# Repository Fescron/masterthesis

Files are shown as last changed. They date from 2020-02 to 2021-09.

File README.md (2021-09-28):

# Masterthesis








<br/>

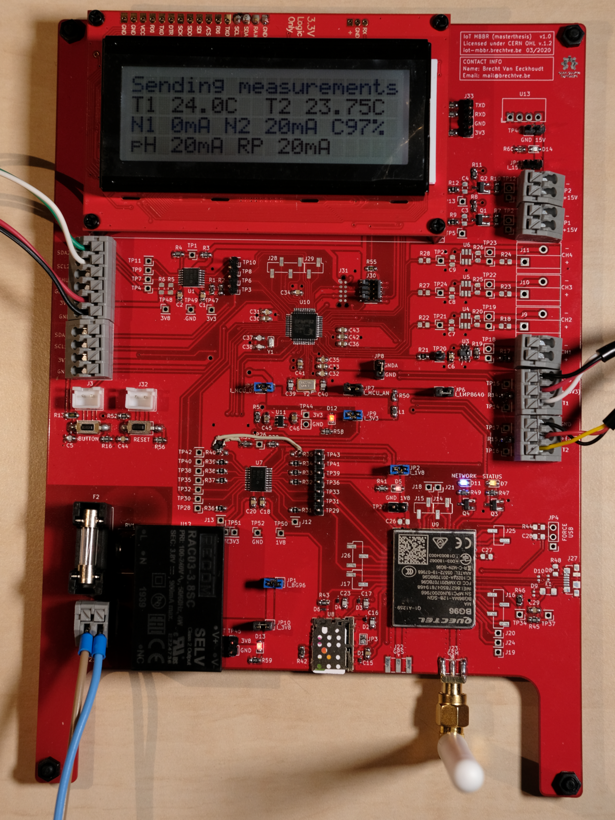
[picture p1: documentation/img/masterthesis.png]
Masterthesis PCB


<br/>

| Quick access links | |
|---|-----|
| [PCB v1.0 schematic (PDF)](hardware/masterthesis-hardware/Plots/masterthesis-hardware-v1.0.pdf) | [Doxygen code documentation of individual files and methods](https://fescron.github.io/masterthesis/files.html) |
| [PCB v1.0 layout (PDF)](hardware/masterthesis-hardware/Plots/masterthesis-hardware-v1-0-PCB.pdf) | [Doxygen TODO's](https://fescron.github.io/masterthesis/todo.html) |

<br>

This repository is a collection of hardware, firmware and some documentation files for the project I created for my masterthesis.

<br/>

## 0 - Table of Contents

- [Masterthesis](#masterthesis)
  - [0 - Table of Contents](#0---table-of-contents)
  - [1 - Situation](#1---situation)
  - [2 - Hardware](#2---hardware)
  - [3 - Firmware](#3---firmware)
  - [4 - Additional hardware changes (PCB v1.0)](#4---additional-hardware-changes-pcb-v10)

<br/>

## 1 - Situation

The goal of the thesis was to create a module to connect a *Moving Bed BioReactor* (MBBR, schematically pictured below) to the Cloud. A MBBR is a system which removes excess nitrites in, in this case, drainwater coming from greenhouses to prevent eutrophication in surrounding water bodies. This is done by denitrifying bacteria inside the bioreactor, which grow on moving plastic *carriers*, and convert the nitrate to nitrogen gas. This is done in anoxic conditions and in the presence of a suitable electron donor, such as a glycerol-based carbon source.

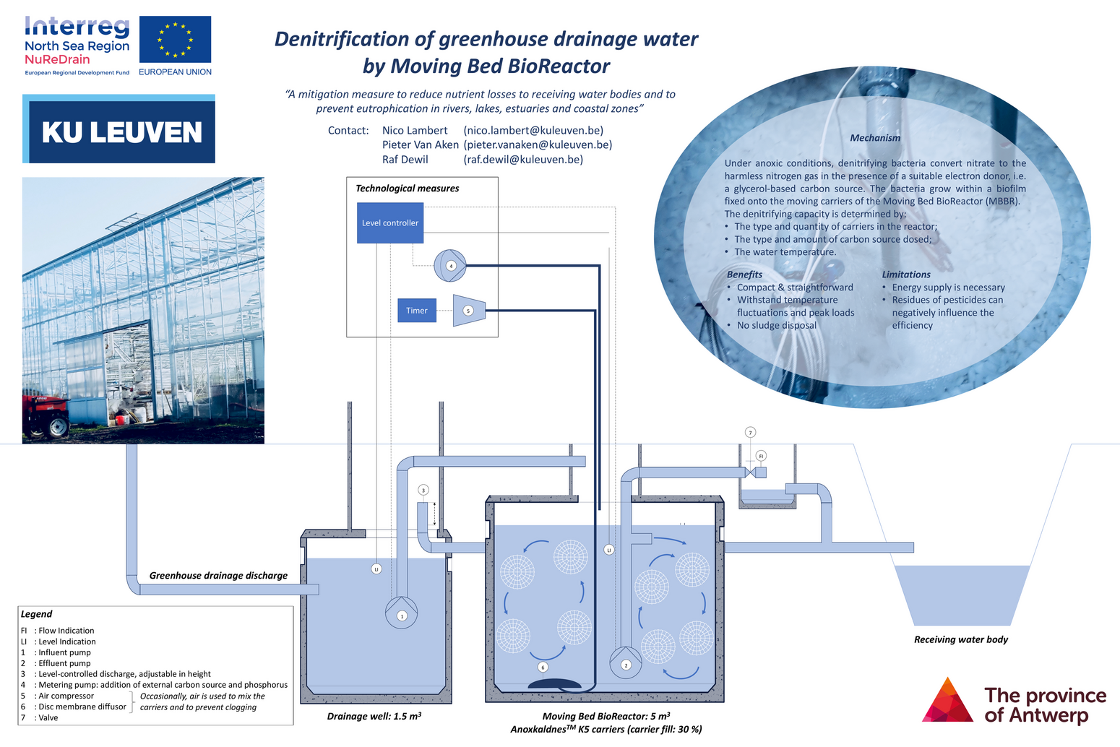
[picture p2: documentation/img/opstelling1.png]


<br/>

The picture below on the left gives an overview of the system that has already been build on the location. The drainage well from the diagram above is pictured on the lower right of this picture. The MBBR itself and a smaller drainage well are underground, under the two manhole covers on the left. In the middle of the picture the measuring system is visible, with under it two blue barrels of carbon source. The picture below on the right gives a peek inside the MBBR. The plastic *carries* are clearly visible.

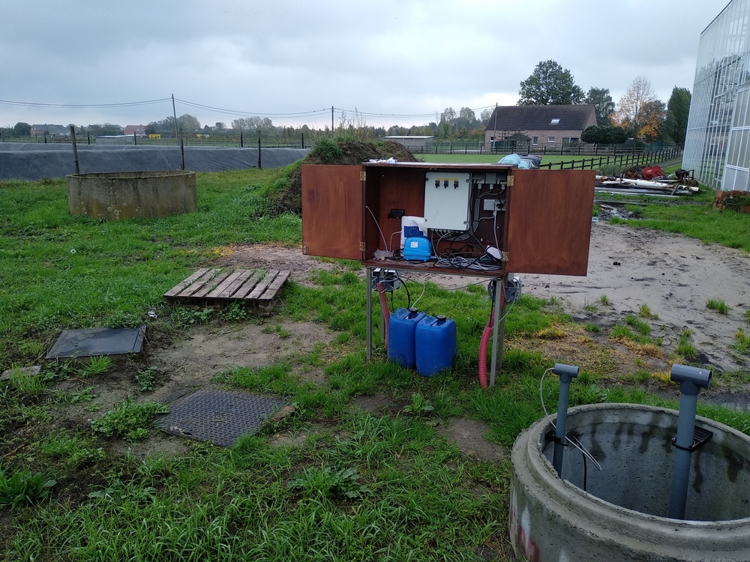
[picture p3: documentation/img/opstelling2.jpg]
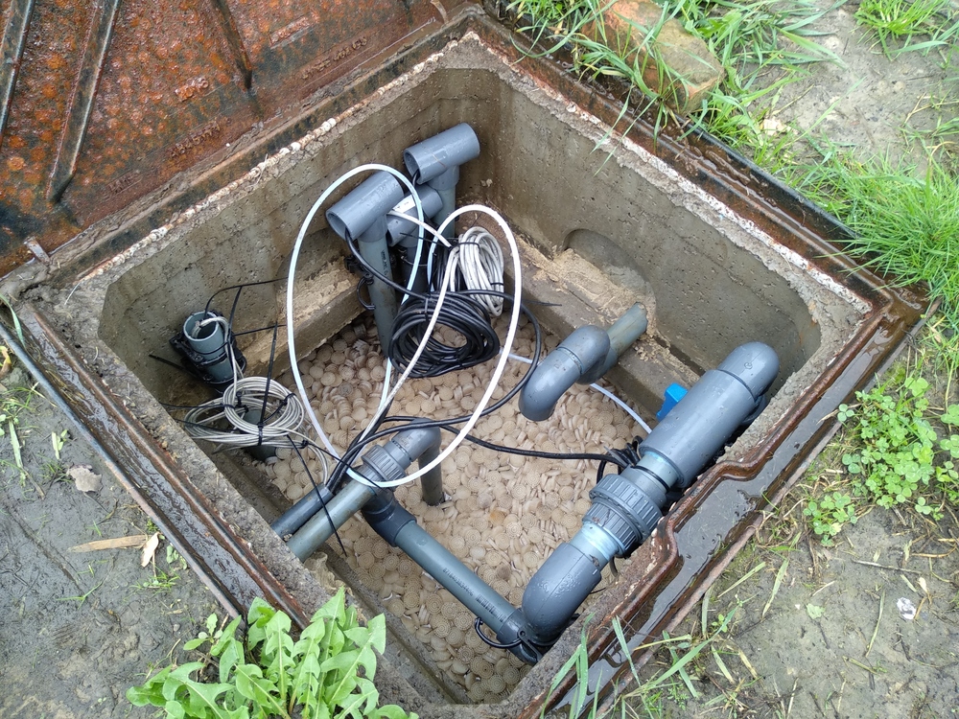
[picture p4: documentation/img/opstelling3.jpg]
MBBR
 

<br/>

To get an overview of the added components of the masterthesis (in full-color) in relation to the already existing structures (semi-transparant), a global block diagram (in Dutch) was created which can be seen below.

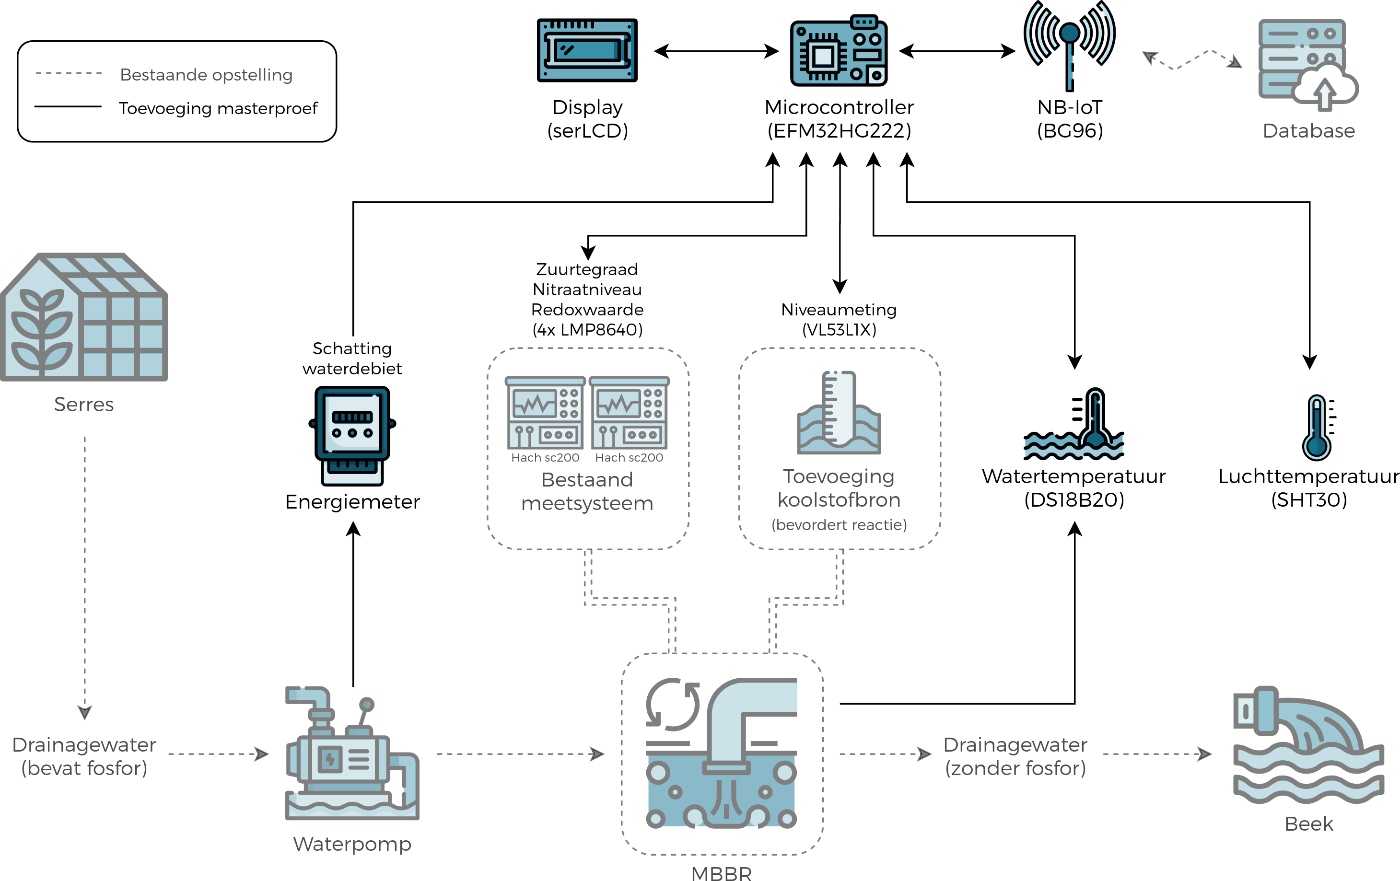
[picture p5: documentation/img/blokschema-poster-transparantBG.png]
Block diagram in relation to MBBR


<br>

The heart of the project is the *EFM32HG222* microcontroller and with a Sparkfun *SerLCD* display it is possible to display status information and measurements. The IoT connection is done with a *BG96* modem over NB-IoT. To get an indication of the amount of water processed by the MBBR, the amount of energy used by the waterpump is monitored with an energy-meter. This gives a pulse to the microcontroller when a certain amount of energy is used. Measurements done by the MBBR system (Hach *sc200*: acidity level, nitrate value, redox value) are acquired via *4-20 mA current loops*. The remaining amount of carbon source in a barrel is measured with a *VL53L1X* sensor. To measure the water temperature a *DS18B20* sensor was chosen, and to get the air temperature (and humidity) a *SHT30* sensor is used.

<br/>

## 2 - Hardware

Below one can see the block diagram of the constructed PCB (inside the big grey rounded rectangle) and the external sensors/modules on the far right. Semi-transparent items are optional for future expansion. The voltages used by the different components are indicated in square brackets. The different interconnecting technologies (I2C, USART, SWD, ADC, GPIO, ...) are indicated inside the MCU block.

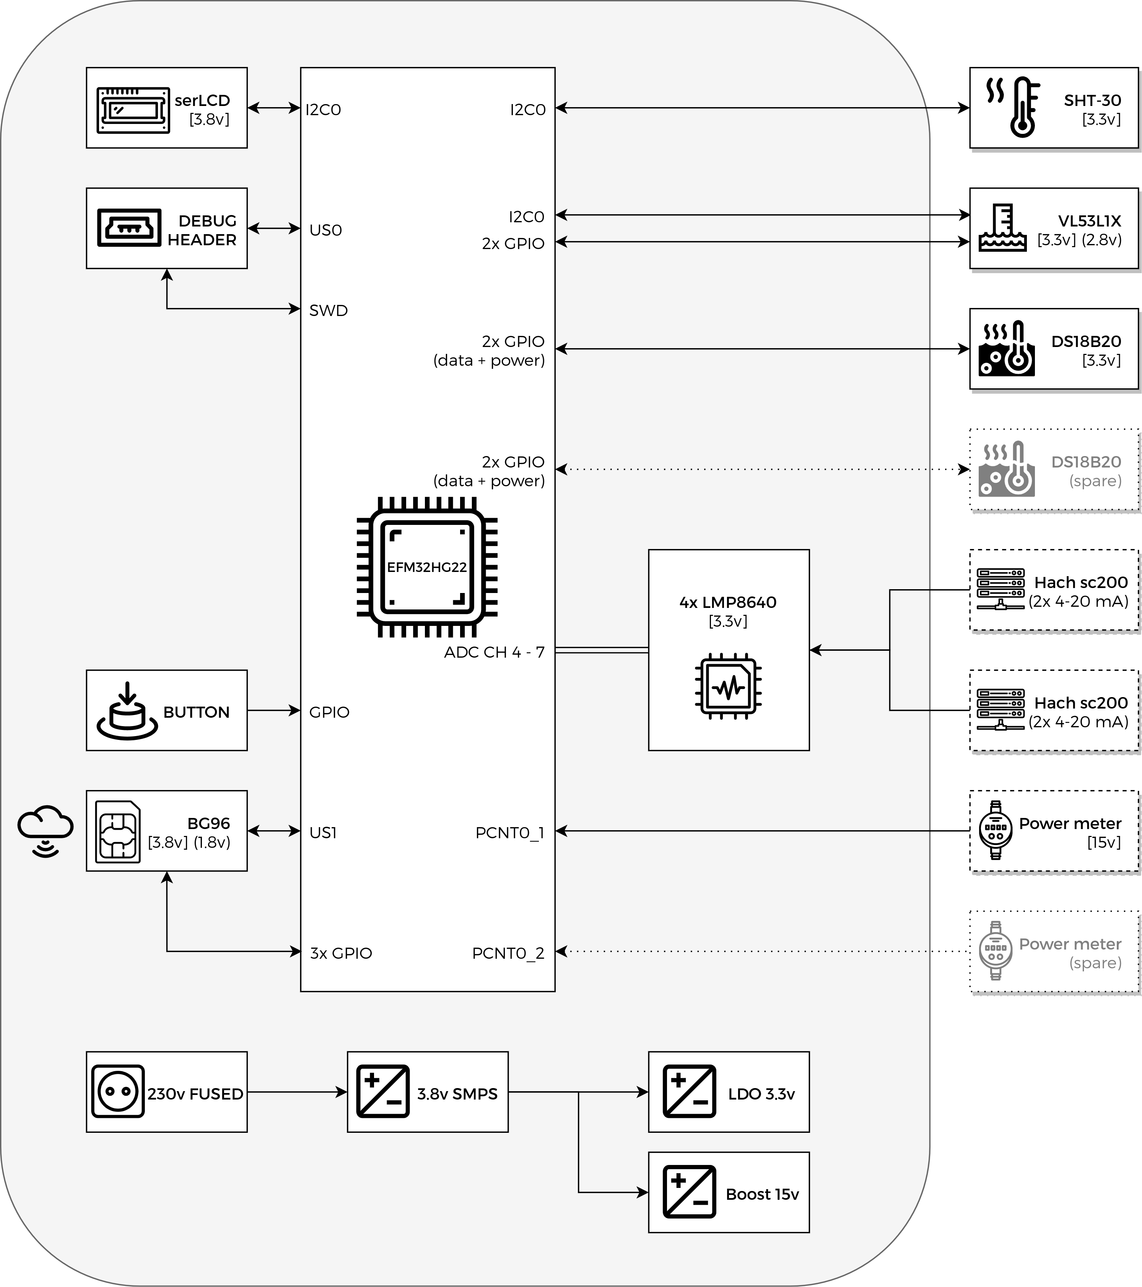
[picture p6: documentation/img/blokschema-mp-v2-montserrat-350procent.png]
Block diagram of the constructed PCB


<br>

230v mains power is used to power the project. A big SMPS is used to convert this AC voltage to a 3.8v DC voltage, mainly to power the BG96 modem and the display. The logic interfaces of the modem however run on 1.8v (indicated by the rounded brackets), so a level-shifter is used to convert the 3.3v logic signals from the MCU. The 3.8v voltage is then further stepped down to 3.3V using an LDO, for use by the MCU and temperature sensors. A 15V boostconverter is also added to supply power to the energy-meter. The schematic of the project can be found [here](hardware/masterthesis-hardware/Plots/masterthesis-hardware-v1.0.pdf).

<br/>

## 3 - Firmware

To get a better idea of the code functionality a few flowcharts were designed, which can be seen below. The left most diagram indicates the *main code-flow*. The code-flow inside the yellow frames on this main flowchart are elaborated in the two diagrams next to the main diagram. The middle flowchart indicates how different statuses are send to the cloud, and the right one indicates how data is being send to the cloud.

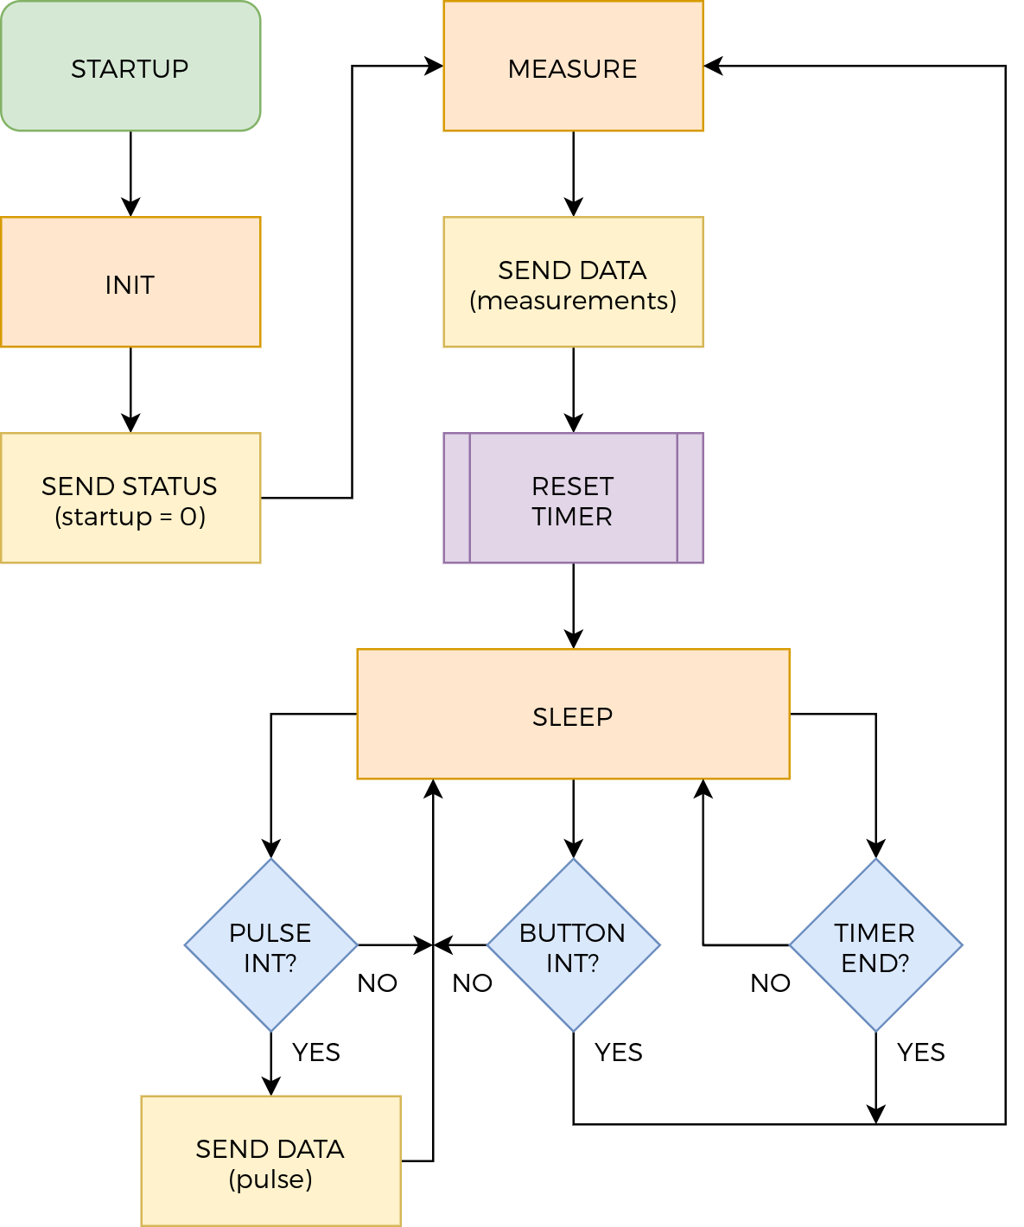
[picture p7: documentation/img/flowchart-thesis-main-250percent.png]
Main flow chart
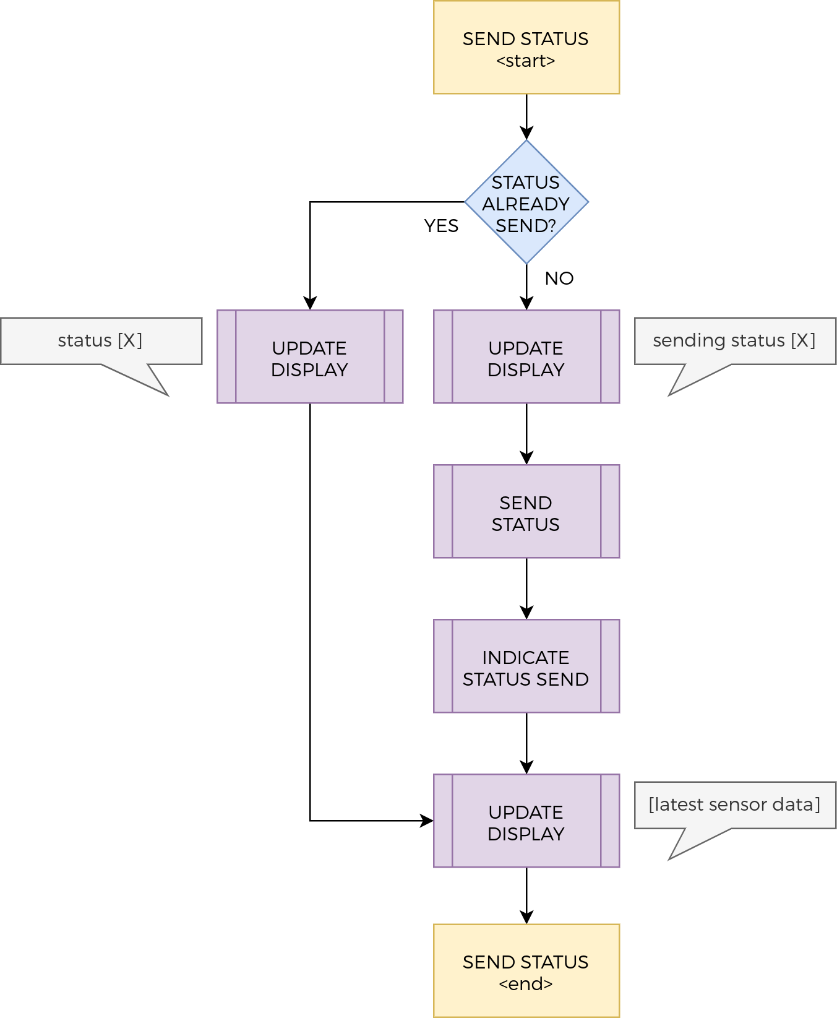
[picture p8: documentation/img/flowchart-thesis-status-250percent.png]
Status flow chart
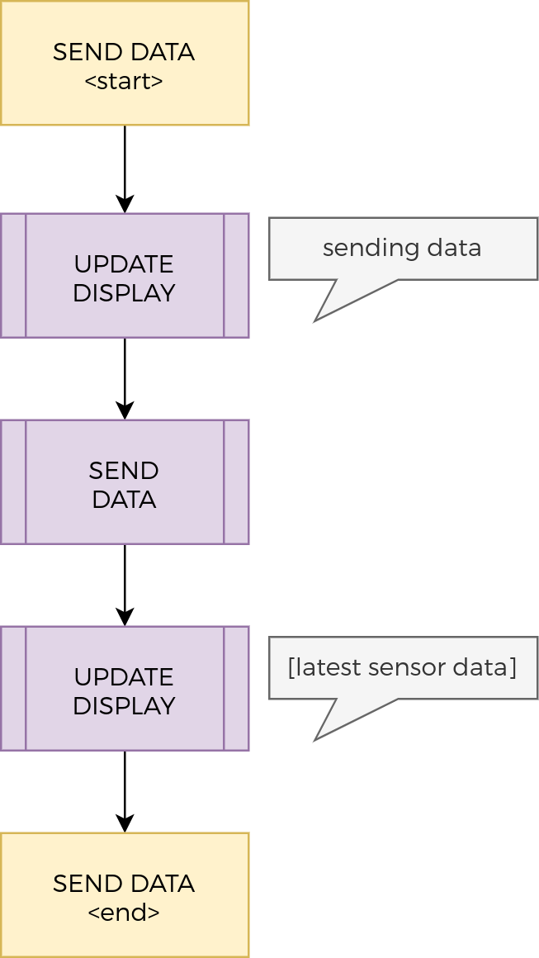
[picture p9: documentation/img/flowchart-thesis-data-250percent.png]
Sending data flow chart
  

<br>

When starting up the code first initializes all the peripherals (INIT). After this a status message is send (SEND STATUS) indicating that the module started up. It can be noted that there is functionality to make sure the module doesn't *spam* status messages, which can be seen in the middle flowchart. Before sending the status message the display is updated indicating that a status message is being send. After the message has been send to the cloud the display is updated with the latest measurements.

After the startup message has been send new measurements are taken (MEASURE), and subsequently these are send to the cloud (SEND DATA). Prior to sending this data the display is updated with a message that data is being send. Afterwards the new measurements are shown on the display. When all of this is done the internal timer is reset (RESET TIMER) so the module can go back to sleep (SLEEP) and wake up after a predefined amount of time (TIMER END) to take new measurements. The module can also wake up on a button press (BUTTON INT) or on an incoming pulse from the energy meter (PULS INT). If the latter is the case this is directly send to the cloud (SEND DATA).

<br>

## 4 - Additional hardware changes (PCB v1.0)

Even though a lot of time was spend making sure the schematic was correct a bodge had to be made to make sure the modem could be turned correctly on and off with the `PWRKEY` pin. At first this was supposed to be done with the `TXB0108PWR` levelshifter but it turned out this could not work due to the inner workings of this chip. Luckily a lot of testpads and zero-ohm resistors were included in the design and a MOSFET, resistor and bodge-wire could easily be soldered to enable the correct functionality. This can be seen on the first overview picture on this repository.

What can also be seen on this picture is that not all of the components are fitted. Some were not soldered because they were not necessary at that point, like for example the micro-USB port which can be used for firmware updates and configuration of the modem. A 3D-render of the whole project is however given below, only missing the display and surrounding case.

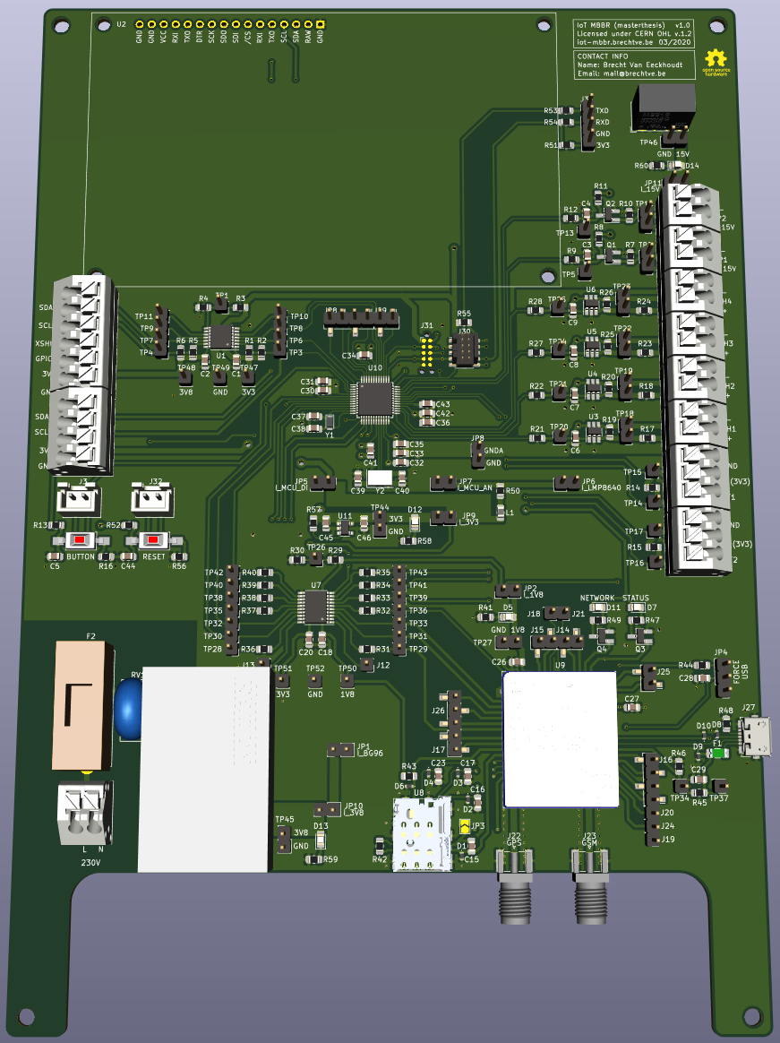
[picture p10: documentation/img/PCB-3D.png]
Masterthesis PCB 3D view


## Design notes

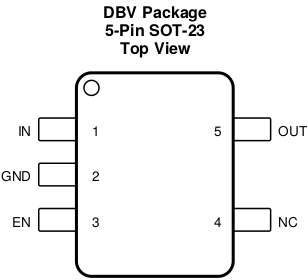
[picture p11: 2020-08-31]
hardware/masterthesis-hardware/TLV75533PDBV-SOT-23-5.png

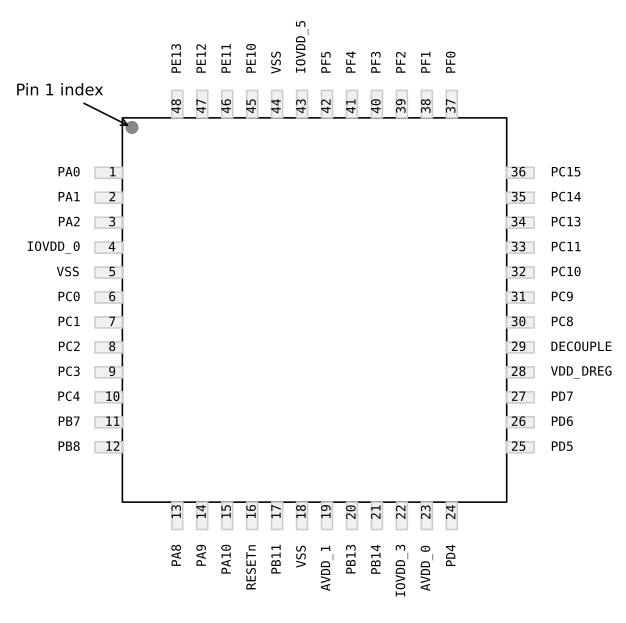
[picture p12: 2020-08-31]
hardware/masterthesis-hardware/EFM32HG222-TQFP48.png

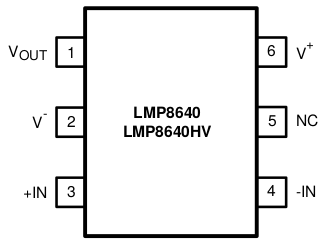
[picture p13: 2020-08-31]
hardware/masterthesis-hardware/LMP38640-SOT-23-6.png

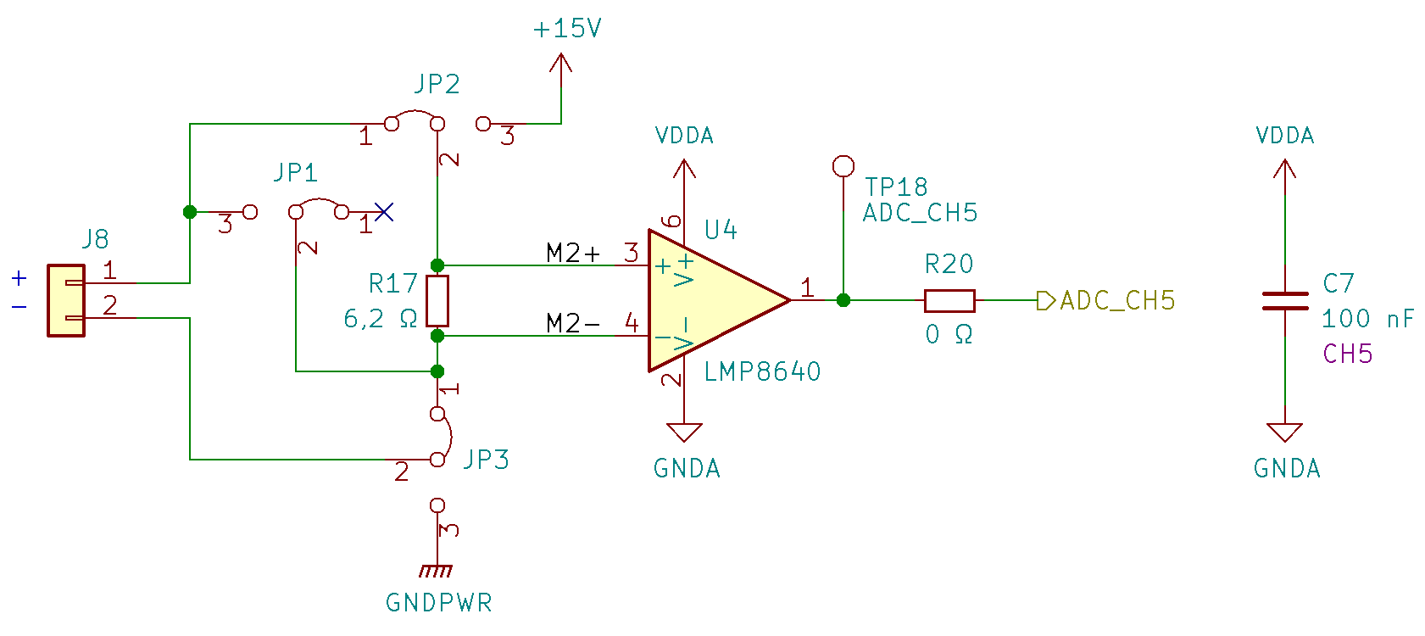
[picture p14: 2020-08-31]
documentation/schematics/4-20mA-active-passive.png

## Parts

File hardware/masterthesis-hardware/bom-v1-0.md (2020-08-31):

# BOM - v1.0 - [15/03/2020]

<br/>

## Sensors and other modules

| Type | Manufacturer | Ordering |
| --- | --- | --- |
| SHT30 | Adafruit | [Mouser.be](https://www.mouser.be/ProductDetail/Adafruit/4099?qs=sGAEpiMZZMve4%2FbfQkoj%252BBbfTR7tiJ1XAJc4Q4bxq1I%3D) |
| DS18B20 | Sparkfun | [Mouser.be](https://www.mouser.be/ProductDetail/SparkFun/SEN-11050?qs=WyAARYrbSnY0sq2HamgEvg%3D%3D) |
| VL53L1X | STMicroelectronics | [Mouser.be](https://www.mouser.be/ProductDetail/STMicroelectronics/VL53L1X-SATEL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) |
| Slip ring | Adafruit | [Mouser.be](https://www.mouser.be/ProductDetail/Adafruit/736?qs=sGAEpiMZZMsMyYRRhGMFNoMqoNVCBxsNJSIWehw82CY%3D) |
| serLCD | Sparkfun | [Mouser.be](https://www.mouser.be/ProductDetail/SparkFun/LCD-14074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) |
| 230VAC to 3.8VDC 3W | RECOM Power | [Mouser.be](https://www.mouser.be/ProductDetail/RECOM-Power/RAC03-38SC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) |
| 3.3VDC to 15VDC 1W  | Murata Power Solutions | [Mouser.be](https://www.mouser.be/ProductDetail/Murata-Power-Solutions/MEE1S0315SC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) |
| Case | Hammond Manufacturing  | [Mouser.be](https://www.mouser.be/ProductDetail/Hammond-Manufacturing/1554V2GYCL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) |

<br/>

## Chips and other components

| Component | Value | Footprint | Other | Ordering |
| --- | --- | --- | --- | --- |
| | EFM32HG222 | TQFP48 | 64 kB flash, 8 kB RAM | [Mouser.be](https://www.mouser.be/ProductDetail/Silicon-Labs/EFM32HG222F64G-C-QFP48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) |
| | LMP8640 | SOT-23-Thin-6 | Texas Instruments Current Shunt Monitor | [Mouser.be](https://www.mouser.be/ProductDetail/Texas-Instruments/LMP8640MK-T-NOPB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) |
| | MMUN2233LT1G | SOT-23 | Calibrated NPN bipolar transistor | [Mouser.be](https://www.mouser.be/ProductDetail/ON-Semiconductor/MMUN2233LT1G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) |
| | TXB0108PWR | TSSOP-20 | 8-Bit Bidirectional Voltage-Level Translator | [Mouser.be](https://www.mouser.be/ProductDetail/Texas-Instruments/TXB0108PWR?qs=sGAEpiMZZMupTq4AYuRvQKKOVTxKvBsp) |
| | TXS0104EPWR | TSSOP-14 | 4-Bit Bidirectional Voltage-Level Translator | [Mouser.be](https://www.mouser.be/ProductDetail/Texas-Instruments/TXS0104EPWR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) |
| | TLV75533PDBVR | SOT-23-5 | 3.3V LDO | [Mouser.be](https://www.mouser.be/ProductDetail/Texas-Instruments/TLV75533PDBVR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) |
| | PPTC resettable fuse | 1206 | Littelfuse 1206L110SLYR (6V 1,1A hold, 2,2A cutoff) | [Mouser.be](https://www.mouser.be/ProductDetail/Littelfuse/1206L110SLYR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) |
| | SP3030-01ETG | 0402 | Unidirectional Low Capacitance TVS | [Mouser.be](https://www.mouser.be/ProductDetail/Littelfuse/SSP3030-01ETGP3030-01ETG?qs=sGAEpiMZZMsUHo5Nc1jlm5q6wolV3djR) |
| | SP1003-01ETG | 0402 | Unidirectional General Purpose TVS | [Mouser.be](https://www.mouser.be/ProductDetail/Littelfuse/SP1003-01ETG?qs=sGAEpiMZZMvn9JuIWNFwezGwQ6bhGW%2Ff) |
| | Ferrite Bead | 0805 | 0,5 Ω (1 kΩ @ 100 MHz), 250 mA, (&plusmn;)25% | [Mouser.be](https://www.mouser.be/ProductDetail/Murata-Electronics/BLM21BD102SN1D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) |
| | SPST Tact Switch | SW_SPST_FSMSM | 50 mA, 24 VDC | [Mouser.be](https://www.mouser.be/ProductDetail/TE-Connectivity-Alcoswitch/FSMSM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) |
| | 32,768 kHz Crystal | 2012 | 12,5 pF, (&plusmn;)20 PPM | [Mouser.be](https://www.mouser.be/ProductDetail/ABRACON/ABS06-127-32768kHz-T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) |
| | 24 MHz Crystal | 5x3.2-4PAD | 8 pF min, 20 pF Typical, (&plusmn;)10 PPM | [Mouser.be](https://www.mouser.be/ProductDetail/ECS/ECS-240-8-30B-CKM-TR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) |
| | Red LED | 0805 | 2V 20mA typical | [Mouser.be](https://www.mouser.be/ProductDetail/Wurth-Elektronik/150080RS75000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) |
| | Yellow LED | 0805 | 2V 20mA typical | [Mouser.be](https://www.mouser.be/ProductDetail/Wurth-Elektronik/150080YS75000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) |
| | Bright Green LED | 0805 | 2V 20mA typical | [Mouser.be](https://www.mouser.be/ProductDetail/Wurth-Elektronik/150080VS75000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) |
| | 250 VAC Fuse | 5 mm x 20 mm | 32 mA , Slow Blow/Time Delay | [Mouser.be](https://www.mouser.be/ProductDetail/Littelfuse/0218032MXP?qs=sGAEpiMZZMsIz3CjQ1xegWrlMY7vL59ho1KZDWRmjG4%3D) |
| | (250 VAC Fuse) | (5 mm x 20 mm) | (40 mA , Slow Blow/Time Delay) | ([Mouser.be](https://www.mouser.be/ProductDetail/Littelfuse/0218040MXP?qs=sGAEpiMZZMsIz3CjQ1xegWrlMY7vL59hsDSpvDVgBZo%3D)) |
| | 5 mm Fuse Holder | Stelvio-Kontek_PTF78 | Keystone Electronics, Black, Shrouded | [Mouser.be](https://www.mouser.be/ProductDetail/Keystone-Electronics/4628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) |
| | 250 VAC RMS MOV | D12mm_W6.1mm_P7.5mm  | 650 Vmax Clamping Voltage (varistor) | [Mouser.be](https://www.mouser.be/ProductDetail/Panasonic/ERZ-E08A391CS?qs=sGAEpiMZZMuQmL5N8IqpXw3FFZmgJFwpBddYiZ3tFNw%3D) |
| | MOSFET (NMOS) | SOT-23 | Enhancement, 60V 210 mA | [Mouser.be](https://www.mouser.be/ProductDetail/Diodes-Incorporated/2N7002-7-F?qs=jMXWnm70%252BC%252BAX%252BMLzUkTZg==) |

<br/>

## Connectors

| Component | Value | Footprint | Other | Ordering |
| --- | --- | --- | --- | --- |
| | TBL002A-350-02GY-2GY | 01x02 3.5mm pitch | 45° grey screwless terminal block | [Mouser.be](https://www.mouser.be/ProductDetail/CUI-Devices/TBL002A-350-02GY-2GY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) |
| | TBL002A-350-03GY-2GY | 01x03 3.5mm pitch | 45° grey screwless terminal block | [Mouser.be](https://www.mouser.be/ProductDetail/CUI-Devices/TBL002A-350-03GY-2GY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) |
| | TBL002A-350-04GY-2GY | 01x04 3.5mm pitch | 45° grey screwless terminal block | [Mouser.be](https://www.mouser.be/ProductDetail/CUI-Devices/TBL002A-350-04GY-2GY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) |
| | TBL002A-350-06GY-2GY | 01x06 3.5mm pitch | 45° grey screwless terminal block | [Mouser.be](https://www.mouser.be/ProductDetail/CUI-Devices/TBL002A-350-06GY-2GY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) |
| | SWD header | 02x05 0.05" | keyed/shrouded header | [Mouser.be](https://www.mouser.be/ProductDetail/Samtec/FTSH-105-01-L-DV-K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) |
| | CON-SMA-EDGE-S | SMA edge | SMA-J-P-X-ST-EM1_EdgeMount | [Mouser.be](https://www.mouser.be/ProductDetail/RF-Solutions/CON-SMA-EDGE-S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) |
| | Micro USB | 47346-0001 | Molex | [Mouser.be](https://www.mouser.be/ProductDetail/Molex/47346-0001?qs=%2Fha2pyFaduiJWkclJ6vmoxPm1IDZfDKPxl9YVM5WTkQ%3D) |
| | Nano SIM holder | | JAE Electronics | [Mouser.be](https://www.mouser.be/ProductDetail/JAE-Electronics/SF72S006VBAR2500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) |

<br/>

## Resistors

| Component | Value | Footprint | Other | Ordering |
| --- | --- | --- | --- | --- |
| | 0 Ω | 0805 | (&plusmn;)5% | [Mouser.be](https://www.mouser.be/ProductDetail/Yageo/RC0805JR-070RL?qs=sGAEpiMZZMtlubZbdhIBIL%252BeN7w0kdZVrTXkiv06W9E%3D) |
| | 1 Ω | 0805 | (&plusmn;)1% | [Mouser.be](https://www.mouser.be/ProductDetail/Yageo/RC0805FR-071RL?qs=sGAEpiMZZMtlubZbdhIBIBEZimkhVqQ4xwd%252BRXN4zfg%3D) |
| | 6,2 Ω | 0805 | (&plusmn;)0,1% | [Mouser.be](https://www.mouser.be/ProductDetail/TE-Connectivity-Neohm/CPF0805B6R2E1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) |
| | 100 Ω | 0805 | | |
| | 1 kΩ | 0805 | | |
| | 1,47 kΩ | 0805 | (&plusmn;)1% | [Mouser.be](https://www.mouser.be/ProductDetail/Yageo/RC0805FR-071K47L?qs=sGAEpiMZZMu61qfTUdNhG5eFuApKbqVdLUrU1N1LHRY%3D) |
| | 2,2 kΩ  | 0805 | | |
| | 10 kΩ | 0805 | | |
| | 15 kΩ | 0805 | | |
| | 51 kΩ | 0805 | (&plusmn;)1% | [Mouser.be](https://www.mouser.be/ProductDetail/Yageo/RE0805FRE0751KL?qs=sGAEpiMZZMtlubZbdhIBIKm0gsRX2fVks15H7Fepbdc%3D) |
| | 100 kΩ  | 0805 | | |
| | 120 kΩ  | 0805 | | |
| | 1 MΩ | 0805 | (&plusmn;)1% | [Mouser.be](https://www.mouser.be/ProductDetail/Yageo/RC0805FR-101ML?qs=sGAEpiMZZMtlubZbdhIBIEM5%252BYIsBt7JbDHmQom9yyE%3D) |

<br/>

## Capacitors

| Component | Value | Footprint | Other | Ordering |
| --- | --- | --- | --- | --- |
| | 10 pF | 0805 | C0G, 50V, (&plusmn;)10% | [Mouser.be](https://www.mouser.be/ProductDetail/Yageo/CC0805KRNPO9BN100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) |
| | 12 pF | 0805 | C0G, 50V, (&plusmn;)5% | [Mouser.be](https://www.mouser.be/ProductDetail/AVX/08055A120JAT2A?qs=sGAEpiMZZMs0AnBnWHyRQAO9wz3NDm%2FCUKlQUVMZQfQ%3D) |
| | 18 pF | 0805 | C0G, 50V, (&plusmn;)5% | [Mouser.be](https://www.mouser.be/ProductDetail/AVX/08055A180JAT2A?qs=sGAEpiMZZMs0AnBnWHyRQKZcV7shucx0ZTMDhu%252BdGVw%3D) |
| | 33 pF | 0805 | C0G, 50V, (&plusmn;)10% | [Mouser.be](https://www.mouser.be/ProductDetail/KEMET/C0805C330K5GACTU?qs=sGAEpiMZZMs0AnBnWHyRQDFFXrMS8epKKdBCCDfrMeo%3D) |
| | 1 nF = 1000 pF | 0805 | X7R, 16V, (&plusmn;)10% | [Mouser.be](https://www.mouser.be/ProductDetail/Wurth-Elektronik/885012207033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) |
| | 10 nF | 0805 | X7R, 50V, (&plusmn;)10% | [Mouser.be](https://www.mouser.be/ProductDetail/Wurth-Elektronik/885012207092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) |
| | 100 nF = 0,1 µF | 0805 | X7R, 16V, (&plusmn;)10% | [Mouser.be](https://www.mouser.be/ProductDetail/Yageo/CC0805KRX7R7BB104?qs=sGAEpiMZZMs0AnBnWHyRQMMzfhmH8IQX2eB5GrOHrwc%3D) |
| | 1 µF | 0805 | X7R, 16V, (&plusmn;)10% | [Mouser.be](https://www.mouser.be/ProductDetail/Taiyo-Yuden/EMK212B7105KG-T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) |
| | 2,2 µF | 0805 | X7R, 10V, (&plusmn;)10% | [Mouser.be](https://www.mouser.be/ProductDetail/Taiyo-Yuden/LMK212B7225KG-T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) |
| | 10 µF | 0805 | X7R, 10V, (&plusmn;)10% | [Mouser.be](https://www.mouser.be/ProductDetail/Murata-Electronics/GRM21BR71A106KA73K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) |
| | 100 µF | 1206 | X5R, 10V, (&plusmn;)20% | [Mouser.be](https://www.mouser.be/ProductDetail/Murata-Electronics/GRM31CR61A107ME05L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) |
| | 470 µF (instead of 100 µF) | 2917 (7343-43) | Tantalium, 10V, (&plusmn;)10% | [Mouser.be](https://www.mouser.be/ProductDetail/AVX/TPSE477K010R0100?qs=sGAEpiMZZMtZ1n0r9vR22WBN%252BThccN0vWWE0vgOaCcw%3D) |

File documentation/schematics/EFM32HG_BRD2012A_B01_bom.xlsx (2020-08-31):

P/N: | BRD2012A
Revision: | B01
Description: | EFM32 Happy Gecko Starter Kit
Revised: | Friday, March 27, 2015
Item | Quantity | Reference | Value | Manufacturer | Manufacturers Part Number | Tolerance | Rating | Technology | Not Mounted
1 | 5 | C100,C101,C610,C1001,C1003 | 1N | Murata | GRM155 |  | 16V | X7R
2 | 56 | C102,C103,C104,C105,C106,C107,C108,C408,C409,C410,C411,C600,C603,C604,C605,C606,C611,C660,C701,C702,C704,C706,C707,C710,C721,C724,C726,C727,C728,C730,C733,C734,C736,C739,C740,C741,C742,C744,C800,C803,C804,C805,C806,C807,C808,C810,C891,C904,C910,C911,C912,C913,C914,C916,C917,C920 | 100N | Murata | GRM155 |  | 16V | X7R
3 | 4 | C400,C401,C608,C609 | 1U | Murata | GRM18 |  | 10V | X5R
4 | 1 | C402 | 4U7 | Murata | GRM21 |  | 25V | X5R
5 | 15 | C404,C415,C601,C607,C700,C703,C714,C719,C720,C725,C731,C732,C735,C907,C915 | 10U | Murata | GRM21 |  | 10V | X5R
6 | 9 | C405,C406,C650,C718,C738,C890,C905,C908,C909 | 10N | Murata | GRM155 |  | 16V | X7R
7 | 2 | C417,C418 | 12P | Murata | GRM155 |  | 50V | C0G
8 | 4 | C421,C422,C900,C901 | 18P | Murata | GRM155 |  | 50V | C0G
9 | 2 | C602,C705 | 33N | Murata | GRM155 |  | 16V | X7R
10 | 2 | C729,C737 | 10N | Murata | GRM155 |  | 16V | X7R | NM
11 | 1 | C743 | 22U | Murata | GRM21 |  | 10V | X5R
12 | 2 | C902,C903 | 12P | Murata | GRM155 |  | 50V | C0G
13 | 2 | C1002,C1004 | 10P | Murata | GRM155 |  | 50V | C0G
14 | 1 | DISP1 | LS013B7DH03 | SHARP | LS013B7DH03
15 | 1 | D400 | PRTR5V0U2F | NXP Semiconductors | PRTR5V0U2F,115
16 | 1 | D600 | IP4220CZ6 | NXP Semiconductors | IP4220CZ6,125
17 | 1 | D703 | LM4040CIM3-3.0 | National | LM4040CIM3-3.0/NOPB
18 | 2 | D705,D800 | VESD05A8A-HNH | Vishay Semiconductors | VESD05A8A-HNH
19 | 1 | D801 | PESD5V0F5UF | NXP Semiconductors | PESD5V0F5UF,115
20 | 2 | J101,J102 | HEADER_2X16_2.54MM_TH |  |  |  |  |  | NM
21 | 3 | LED100,LED101,LED900 | YELLOW | Würth Electronics | 150060YS75000
22 | 1 | LED901 | BLUE | Panasonic | LNJ926W8CRA
23 | 1 | LED903 | RED | Würth Electronics | 150060RS75000
24 | 1 | LED904 | LED_G_R | Avago | HSMF-C165
25 | 9 | L400,L700,L702,L703,L780,L800,L801,L900,L1001 | CBF102WB | Würth Electronics | 74279266
26 | 2 | L401,L600 | CBF221HC | Würth Electronics | 742792022
27 | 1 | M1 | HOLE_PTH_3MM |  |  |  |  |  | NM
28 | 2 | M2,M3 | HOLE_TH_3MM |  |  |  |  |  | NM
29 | 2 | M4,M5 | 25x4mm | Parafix | PAR220812RB1
30 | 1 | PCB1 | PCB2012 |  | PCB2012 Rev. B00
31 | 1 | P100 | HEADER_2X10_2.54MM_HOR_SMD | Taitek | HE2-20G6C394-5R
32 | 1 | P101 | XF2L-1025-1A_MEMLCD | OMRON | XF2L-1025-1A
33 | 1 | P400 | USB MICRO-B | Hirose | ZX62-B-5PA(11)
34 | 1 | P601 | WR_COM_USB_MINI_B | Würth Electronics | 651 005 161 21
35 | 1 | P700 | COIN_CELL | Keystone | 3002
36 | 1 | P701 | HEADER_2X10_1.27MM_SMD | Sullins | GRPB102VWQS
37 | 1 | P800 | HEADER_DEBUG_ETM | Samtec | FSTH-110-01-L-DV-K-P-TR
38 | 1 | Q700 | BSS84 | Diodes Inc. | BSS84DW-7-F
39 | 1 | Q701 | DMN5L06 | Diodes Inc. | DMN5L06DWK-7
40 | 1 | Q702 | BC846BWT1G | ON Semiconductor | BC846BWT1G
41 | 1 | Q703 | NTS210 | ON Semiconductor | NTS2101PT1G
42 | 1 | Q800 | DMN5L06WK | Diodes Inc. | DMN5L06WK-7
43 | 2 | RP800,RP801 | 33R | ROHM | MNR04M0APJ330
44 | 6 | R100,R103,R129,R728,R810,R811 | 100R
45 | 6 | R101,R102,R109,R708,R742,R815 | 1M
46 | 8 | R104,R111,R119,R748,R779,R786,R915,R916 | 0R
47 | 4 | R105,R118,R610,R814 | 10M
48 | 16 | R106,R603,R604,R605,R606,R611,R612,R650,R651,R652,R681,R735,R800,R816,R890,R891 | 100K |  |  | 1%
49 | 3 | R107,R108,R900 | 3K
50 | 1 | R110 | 10M |  |  |  |  |  | NM
51 | 11 | R112,R113,R600,R609,R623,R700,R729,R739,R782,R785,R914 | 10K |  |  | 1%
52 | 8 | R114,R115,R607,R608,R727,R774,R807,R808 | 4K7
53 | 2 | R116,R734 | 510K |  |  | 1%
54 | 9 | R128,R682,R705,R743,R772,R783,R792,R919,R920 | 1K
55 | 3 | R403,R731,R910 | 1R
56 | 2 | R405,R406 | 15R
57 | 2 | R601,R702 | 180K
58 | 2 | R602,R703 | 110K
59 | 4 | R621,R627,R745,R747 | 0R |  |  |  |  |  | NM
60 | 1 | R622 | 47R |  |  | 1%
61 | 2 | R701,R740 | 4R7 | Bourns | CRT1206-BY-4R7-ELFTR | 0.10%
62 | 1 | R706 | 15K
63 | 1 | R707 | 33K
64 | 4 | R709,R710,R732,R733 | 1K8 | YAGEO | RT0603BRD071K8L | 0.10%
65 | 2 | R717,R736 | 10R
66 | 2 | R718,R737 | 12K | YAGEO | RT0603BRD0712KL | 0.10%
67 | 1 | R738 | 8K2
68 | 1 | R741 | 51K |  |  | 1%
69 | 1 | R744 | 22K
70 | 1 | R746 | 2R2
71 | 1 | R760 | 330K |  |  | 1%
72 | 2 | R781,R805 | 33R
73 | 1 | R801 | 47K
74 | 1 | R809 | 100K |  |  | 1% |  |  | NM
75 | 1 | R901 | 1K5
76 | 2 | R902,R904 | 22R
77 | 2 | R903,R912 | 2K
78 | 2 | R917,R918 | 4K7 |  |  |  |  |  | NM
79 | 2 | R1002,R1007 | 6K2
80 | 2 | R1003,R1008 | 62R
81 | 3 | R1004,R1009,R1010 | 51K | YAGEO | RT0603BRD0751KL | 0.10%
82 | 1 | R1005 | 160R | YAGEO | RT0603BRD07160RL | 0.10%
83 | 1 | ST1 | 2X1 2.54MM |  |  |  |  |  | NM
84 | 2 | SW100,SW101 | WS_TSS_6X6MM_SMD | Würth Electronics | 430 182 043 816
85 | 1 | SW103 | WS_TASV_6X3.5MM_SMD | Würth Electronics | 434 121 043 816
86 | 1 | SW104 | SW_DP3T | ALPS | SSSS223600
87 | 1 | TPH999 | PROTO_TH |  |  |  |  |  | NM
88 | 3 | TPJ403,TPJ404,TPJ405 | TP_SMD
89 | 54 | TP150,TP151,TP152,TP153,TPJ600,TPJ606,TPJ607,TPJ608,TPJ611,TPJ612,TPJ613,TPJ614,TPJ650,TPJ651,TPJ652,TPJ653,TP700,TP701,TP702,TP705,TP706,TP707,TP708,TP710,TP711,TP712,TP713,TP714,TPJ811,TPJ812,TPJ813,TPJ814,TPJ817,TPJ818,TPJ820,TPJ900,TPJ901,TPJ902,TP903,TPJ905,TPJ908,TPJ909,TPJ910,TPJ911,TPJ912,TPJ913,TP923,TPJ950,TPJ951,TPJ952,TPJ953,TPJ954,TPJ955,TPJ956 | TP_SMD |  |  |  |  |  | NM
90 | 6 | TP154,TP156,TP400,TP401,TP703,TP709 | TP_SMD |  |  |  |  |  | NM
91 | 2 | T1,T2 | TOUCH |  |  |  |  |  | NM
92 | 1 | U1 | EFM32HG322F64 | Silicon Laboratories | EFM32HG322F64
93 | 1 | U100 | TS3A44159 | Texas Instruments | TS3A44159RSVR
94 | 2 | U101,U707 | TS3A24159 | Texas Instruments | TS3A24159YZPR
95 | 1 | U102 | Si7021-A10 | Silicon Laboratories | Si7021-A10-GM1
96 | 5 | U103,U602,U650,U702,U805 | TS3A4751 | Texas Instruments | TS3A4751RUCR
97 | 2 | U600,U701 | LP3982ILD-ADJ | National Semiconductor | LP3982ILDX-ADJ
98 | 1 | U601 | 24AA024 | Microchip | 24AA024-I/MS
99 | 1 | U603 | TLV70536 | Texas Instruments | TLV70536YFP
100 | 4 | U604,U800,U802,U806 | 74LVC4066 | NXP | 74LVC4066BQ,115
101 | 5 | U660,U661,U803,U804,U809 | 74LVC2G125 | Texas Instruments | SN74LVC2G125YZPR
102 | 1 | U700 | NX3V1G66 | NXP | NX3V1G66GM
103 | 2 | U703,U705 | LTC6102CDD | National Semiconductor | LTC6102CDD#PBF
104 | 1 | U704 | TS5A23167 | Texas Instruments | TS5A23167YZP
105 | 1 | U706 | MCP6001T | Microchip Technology | MCP6001T-I/LT
106 | 2 | U708,U709 | TS5A23166 | Texas Instruments | TS5A23166YZPR
107 | 1 | U808 | 74LVC8T245 | Texas Instruments | SN74LVC8T245RHL
108 | 1 | U900 | Control MCU
109 | 1 | U902 | M25PX16 | Numonyx | M25PX16-VMP6E
110 | 1 | U1000 | AD8656 | Analog Devices Inc | AD8656ARMZ
111 | 1 | X400 | 24 MHz | NDK | NX3225GA-24.000MHz
112 | 1 | X401 | 32.768kHz | Micro Crytstal AG | CM8V-T1A, 32768Hz, 12.5pF, +/- 20ppm
113 | 1 | X900 | 16MHz | NDK | NX3225GA-16.000MHZ

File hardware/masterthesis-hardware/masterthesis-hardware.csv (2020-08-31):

Source: | /home/brecht/Qsync/Documents/1-Github-Repositories/masterthesis-hardware/hardware/masterthesis-hardware/masterthesis-hardware.sch
Date: | di 12 mei 2020 15:58:45 CEST
Tool: | Eeschema 5.1.5-52549c5~86~ubuntu19.04.1
Generator: | /usr/share/kicad/plugins/bom_csv_grouped_by_value.py
Component Count: | 195
Individual Components:
Item | Qty | Reference(s) | Value | LibPart | Footprint | Datasheet | Class | Comment | Comment2 | Function | Load capacitance | Mounted | Placement | Tolerance | Type
 |  | C1 | 100 nF | Device:C_Small | Capacitor_SMD:C_0805_2012Metric_Pad1.15x1.40mm_HandSolder | ~
 |  | C2 | 100 nF | Device:C_Small | Capacitor_SMD:C_0805_2012Metric_Pad1.15x1.40mm_HandSolder | ~
 |  | C3 | 100 nF | Device:C_Small | Capacitor_SMD:C_0805_2012Metric_Pad1.15x1.40mm_HandSolder | ~ |  |  |  | optional
 |  | C4 | 100 nF | Device:C_Small | Capacitor_SMD:C_0805_2012Metric_Pad1.15x1.40mm_HandSolder | ~ |  |  |  | optional
 |  | C5 | 1 nF | Device:C_Small | Capacitor_SMD:C_0805_2012Metric_Pad1.15x1.40mm_HandSolder | ~
 |  | C6 | 100 nF | Device:C_Small | Capacitor_SMD:C_0805_2012Metric_Pad1.15x1.40mm_HandSolder | ~ |  |  |  |  |  |  | CH4
 |  | C7 | 100 nF | Device:C_Small | Capacitor_SMD:C_0805_2012Metric_Pad1.15x1.40mm_HandSolder | ~ |  |  |  |  |  |  | CH5
 |  | C8 | 100 nF | Device:C_Small | Capacitor_SMD:C_0805_2012Metric_Pad1.15x1.40mm_HandSolder | ~ |  |  |  |  |  |  | CH6
 |  | C9 | 100 nF | Device:C_Small | Capacitor_SMD:C_0805_2012Metric_Pad1.15x1.40mm_HandSolder | ~ |  |  |  |  |  |  | CH7
 |  | C10 | 470 µF | Device:CP_Small | Capacitor_Tantalum_SMD:CP_EIA-7343-43_Kemet-X_Pad2.25x2.55mm_HandSolder | ~ |  |  |  |  |  | NM | VBAT_BB_alt |  | LOW ESR
 |  | C11 | 100 µF | Device:C_Small | Capacitor_SMD:C_1206_3216Metric_Pad1.42x1.75mm_HandSolder | ~ |  |  |  |  |  |  | VBAT_BB |  | LOW ESR
 |  | C12 | 100 nF | Device:C_Small | Capacitor_SMD:C_0805_2012Metric_Pad1.15x1.40mm_HandSolder | ~ |  |  |  |  |  |  | VBAT_BB |  | MLCC
 |  | C13 | 470 µF | Device:CP_Small | Capacitor_Tantalum_SMD:CP_EIA-7343-43_Kemet-X_Pad2.25x2.55mm_HandSolder | ~ |  |  |  |  |  | NM | VBAT_RB_alt |  | LOW ESR
 |  | C14 | 33 pF | Device:C_Small | Capacitor_SMD:C_0805_2012Metric_Pad1.15x1.40mm_HandSolder | ~ |  |  |  |  |  |  | VBAT_BB |  | MLCC
 |  | C15 | 100 nF | Device:C_Small | Capacitor_SMD:C_0805_2012Metric_Pad1.15x1.40mm_HandSolder | ~
 |  | C16 | 33 pF | Device:C_Small | Capacitor_SMD:C_0805_2012Metric_Pad1.15x1.40mm_HandSolder | ~
 |  | C17 | 33 pF | Device:C_Small | Capacitor_SMD:C_0805_2012Metric_Pad1.15x1.40mm_HandSolder | ~
 |  | C18 | 100 nF | Device:C_Small | Capacitor_SMD:C_0805_2012Metric_Pad1.15x1.40mm_HandSolder | ~
 |  | C19 | 10 pF | Device:C_Small | Capacitor_SMD:C_0805_2012Metric_Pad1.15x1.40mm_HandSolder | ~ |  |  |  |  |  |  | VBAT_BB |  | MLCC
 |  | C20 | 100 nF | Device:C_Small | Capacitor_SMD:C_0805_2012Metric_Pad1.15x1.40mm_HandSolder | ~
 |  | C21 | 100 µF | Device:C_Small | Capacitor_SMD:C_1206_3216Metric_Pad1.42x1.75mm_HandSolder | ~ |  |  |  |  |  |  | VBAT_RF |  | LOW ESR
 |  | C22 | 100 nF | Device:C_Small | Capacitor_SMD:C_0805_2012Metric_Pad1.15x1.40mm_HandSolder | ~ |  |  |  |  |  |  | VBAT_RF |  | MLCC
 |  | C23 | 33 pF | Device:C_Small | Capacitor_SMD:C_0805_2012Metric_Pad1.15x1.40mm_HandSolder | ~
 |  | C24 | 33 pF | Device:C_Small | Capacitor_SMD:C_0805_2012Metric_Pad1.15x1.40mm_HandSolder | ~ |  |  |  |  |  |  | VBAT_RF |  | MLCC
 |  | C25 | 10 pF | Device:C_Small | Capacitor_SMD:C_0805_2012Metric_Pad1.15x1.40mm_HandSolder | ~ |  |  |  |  |  |  | VBAT_RF |  | MLCC
 |  | C26 | 2,2 µF | Device:C_Small | Capacitor_SMD:C_0805_2012Metric_Pad1.15x1.40mm_HandSolder | ~ |  |  |  | optional
 |  | C27 | 10 nF | Device:C_Small | Capacitor_SMD:C_0805_2012Metric_Pad1.15x1.40mm_HandSolder | ~ |  |  |  | optional
 |  | C28 | 10 nF | Device:C_Small | Capacitor_SMD:C_0805_2012Metric_Pad1.15x1.40mm_HandSolder | ~ |  |  |  | optional
 |  | C29 | 100 nF | Device:C_Small | Capacitor_SMD:C_0805_2012Metric_Pad1.15x1.40mm_HandSolder | ~ |  |  |  | optional
 |  | C30 | 10 µF | Device:C_Small | Capacitor_SMD:C_0805_2012Metric_Pad1.15x1.40mm_HandSolder | ~ |  |  |  |  |  |  | IOVDD_0
 |  | C31 | 100 nF | Device:C_Small | Capacitor_SMD:C_0805_2012Metric_Pad1.15x1.40mm_HandSolder | ~ |  |  |  |  |  |  | IOVDD_0
 |  | C32 | 100 nF | Device:C_Small | Capacitor_SMD:C_0805_2012Metric_Pad1.15x1.40mm_HandSolder | ~ |  |  |  |  |  |  | IOVDD_3
 |  | C33 | 10 µF | Device:C_Small | Capacitor_SMD:C_0805_2012Metric_Pad1.15x1.40mm_HandSolder | ~ |  |  |  |  |  |  | AVDDD_0
 |  | C34 | 100 nF | Device:C_Small | Capacitor_SMD:C_0805_2012Metric_Pad1.15x1.40mm_HandSolder | ~ |  |  |  |  |  |  | IOVDD_5
 |  | C35 | 10 nF | Device:C_Small | Capacitor_SMD:C_0805_2012Metric_Pad1.15x1.40mm_HandSolder | ~ |  |  |  |  |  |  | AVDD_0
 |  | C36 | 10 µF | Device:C_Small | Capacitor_SMD:C_0805_2012Metric_Pad1.15x1.40mm_HandSolder | ~ |  |  |  |  |  |  | VDD_DREG
 |  | C37 | 18 pF | Device:C_Small | Capacitor_SMD:C_0805_2012Metric_Pad1.15x1.40mm_HandSolder | ~
 |  | C38 | 18 pF | Device:C_Small | Capacitor_SMD:C_0805_2012Metric_Pad1.15x1.40mm_HandSolder | ~
 |  | C39 | 12 pF | Device:C_Small | Capacitor_SMD:C_0805_2012Metric_Pad1.15x1.40mm_HandSolder | ~
 |  | C40 | 12 pF | Device:C_Small | Capacitor_SMD:C_0805_2012Metric_Pad1.15x1.40mm_HandSolder | ~
 |  | C41 | 10 nF | Device:C_Small | Capacitor_SMD:C_0805_2012Metric_Pad1.15x1.40mm_HandSolder | ~ |  |  |  |  |  |  | AVDD_1
 |  | C42 | 100 nF | Device:C_Small | Capacitor_SMD:C_0805_2012Metric_Pad1.15x1.40mm_HandSolder | ~ |  |  |  |  |  |  | VDD_DREG
 |  | C43 | 1 µF | Device:C_Small | Capacitor_SMD:C_0805_2012Metric_Pad1.15x1.40mm_HandSolder | ~ | X5R |  |  |  |  |  | DECOUPLE
 |  | C44 | 100 nF | Device:C_Small | Capacitor_SMD:C_0805_2012Metric_Pad1.15x1.40mm_HandSolder | ~
 |  | C45 | 1 µF | Device:C_Small | Capacitor_SMD:C_0805_2012Metric_Pad1.15x1.40mm_HandSolder | ~
 |  | C46 | 1 µF | Device:C_Small | Capacitor_SMD:C_0805_2012Metric_Pad1.15x1.40mm_HandSolder | ~
 |  | D1 | SP1003-01ETG | Device:D_Zener_Small_ALT | Diode_SMD:D_0402_1005Metric | ~ |  | Unidirectional TVS | General Purpose
 |  | D2 | SP1003-01ETG | Device:D_Zener_Small_ALT | Diode_SMD:D_0402_1005Metric | ~ |  | Unidirectional TVS | General Purpose
 |  | D3 | SP1003-01ETG | Device:D_Zener_Small_ALT | Diode_SMD:D_0402_1005Metric | ~ |  | Unidirectional TVS | General Purpose
 |  | D4 | SP1003-01ETG | Device:D_Zener_Small_ALT | Diode_SMD:D_0402_1005Metric | ~ |  | Unidirectional TVS | General Purpose
 |  | D5 | RED_1V8 | Device:LED_Small_ALT | LED_SMD:LED_0805_2012Metric_Pad1.15x1.40mm_HandSolder | ~
 |  | D6 | SP1003-01ETG | Device:D_Zener_Small_ALT | Diode_SMD:D_0402_1005Metric | ~ |  | Unidirectional TVS | General Purpose
 |  | D7 | YELLOW_STATUS | Device:LED_Small_ALT | LED_SMD:LED_0805_2012Metric_Pad1.15x1.40mm_HandSolder | ~
 |  | D8 | SP3030-01ETG | Device:D_Zener_Small_ALT | Diode_SMD:D_0402_1005Metric | ~ |  | Unidirectional TVS | Low Capacitance
 |  | D9 | SP1003-01ETG | Device:D_Zener_Small_ALT | Diode_SMD:D_0402_1005Metric | ~ |  | Unidirectional TVS | General Purpose
 |  | D10 | SP3030-01ETG | Device:D_Zener_Small_ALT | Diode_SMD:D_0402_1005Metric | ~ |  | Unidirectional TVS | Low Capacitance
 |  | D11 | GREEN_NETWORK | Device:LED_Small_ALT | LED_SMD:LED_0805_2012Metric_Pad1.15x1.40mm_HandSolder | ~
 |  | D12 | RED_3V3 | Device:LED_Small_ALT | LED_SMD:LED_0805_2012Metric_Pad1.15x1.40mm_HandSolder | ~
 |  | D13 | RED_3V8 | Device:LED_Small_ALT | LED_SMD:LED_0805_2012Metric_Pad1.15x1.40mm_HandSolder | ~
 |  | D14 | RED_15V | Device:LED_Small_ALT | LED_SMD:LED_0805_2012Metric_Pad1.15x1.40mm_HandSolder | ~
 |  | F1 | 1206L110SLYR | Device:Polyfuse_Small | Fuse:Fuse_1206_3216Metric_Pad1.42x1.75mm_HandSolder | ~
 |  | F2 | 32 mA | Device:Fuse_Small | Fuse:Fuseholder_Cylinder-5x20mm_Stelvio-Kontek_PTF78_Horizontal_Open | ~ |  |  |  |  |  |  |  |  | Slow Blow
 |  | G1 | Symbol_OSHW-Logo_11.4x12mm | BrechtVE_Aesthetics:Symbol_OSHW-Logo_11.4x12mm | BrechtVE_Aesthetics:OSHW-Logo_5.7x6mm_SolderMask
 |  | H1 | MountingHole | Mechanical:MountingHole | MountingHole:MountingHole_3.2mm_M3 | ~
 |  | H2 | MountingHole | Mechanical:MountingHole | MountingHole:MountingHole_3.2mm_M3 | ~
 |  | H3 | MountingHole | Mechanical:MountingHole | MountingHole:MountingHole_3.2mm_M3 | ~
 |  | H4 | MountingHole | Mechanical:MountingHole | MountingHole:MountingHole_3.2mm_M3 | ~
 |  | J1 | PCNT | Connector_Generic:Conn_01x02 | Connector_Phoenix_PTSA_extra:PhoenixContact_PTSA_1,5_2-G-3,5_1x02_P3.50mm_Angled | ~
 |  | J2 | PCNT_spare | Connector_Generic:Conn_01x02 | Connector_Phoenix_PTSA_extra:PhoenixContact_PTSA_1,5_2-G-3,5_1x02_P3.50mm_Angled | ~
 |  | J3 | PUSH_button | Connector_Generic:Conn_01x02 | Connector_JST:JST_XH_B2B-XH-A_1x02_P2.50mm_Vertical | ~
 |  | J4 | VL51L1X | Connector_Generic:Conn_01x06 | Connector_Phoenix_PTSA_extra:PhoenixContact_PTSA_1,5_6-G-3,5_1x06_P3.50mm_Angled | ~
 |  | J5 | SHT-30 | Connector_Generic:Conn_01x04 | Connector_Phoenix_PTSA_extra:PhoenixContact_PTSA_1,5_4-G-3,5_1x04_P3.50mm_Angled | ~
 |  | J6 | DS18B20 | Connector_Generic:Conn_01x03 | Connector_Phoenix_PTSA_extra:PhoenixContact_PTSA_1,5_3-G-3,5_1x03_P3.50mm_Angled | ~
 |  | J7 | DS18B20_spare | Connector_Generic:Conn_01x03 | Connector_Phoenix_PTSA_extra:PhoenixContact_PTSA_1,5_3-G-3,5_1x03_P3.50mm_Angled | ~
 |  | J8 | CH4 | Connector_Generic:Conn_01x02 | Connector_Phoenix_PTSA_extra:PhoenixContact_PTSA_1,5_2-G-3,5_1x02_P3.50mm_Angled | ~
 |  | J9 | CH4 | Connector_Generic:Conn_01x02 | Connector_Phoenix_PTSA_extra:PhoenixContact_PTSA_1,5_2-G-3,5_1x02_P3.50mm_Angled | ~
 |  | J10 | CH4 | Connector_Generic:Conn_01x02 | Connector_Phoenix_PTSA_extra:PhoenixContact_PTSA_1,5_2-G-3,5_1x02_P3.50mm_Angled | ~
 |  | J11 | CH4 | Connector_Generic:Conn_01x02 | Connector_Phoenix_PTSA_extra:PhoenixContact_PTSA_1,5_2-G-3,5_1x02_P3.50mm_Angled | ~
 |  | J12 | A1 | Connector_Generic:Conn_01x01 | Connector_PinHeader_2.54mm:PinHeader_1x01_P2.54mm_Vertical | ~
 |  | J13 | B1 | Connector_Generic:Conn_01x01 | Connector_PinHeader_2.54mm:PinHeader_1x01_P2.54mm_Vertical | ~
 |  | J14 | UART2 | Connector_Generic:Conn_01x02 | Connector_PinHeader_2.54mm:PinHeader_1x02_P2.54mm_Vertical_SMD_Pin1Left | ~
 |  | J15 | UART3 | Connector_Generic:Conn_01x02 | Connector_PinHeader_2.54mm:PinHeader_1x02_P2.54mm_Vertical_SMD_Pin1Left | ~
 |  | J16 | PCM | Connector_Generic:Conn_01x04 | Connector_PinHeader_2.54mm:PinHeader_1x04_P2.54mm_Vertical_SMD_Pin1Left | ~
 |  | J17 | I2C | Connector_Generic:Conn_01x02 | Connector_PinHeader_2.54mm:PinHeader_1x02_P2.54mm_Vertical_SMD_Pin1Left | ~
 |  | J18 | GPIO26 | Connector_Generic:Conn_01x01 | Connector_PinHeader_2.54mm:PinHeader_1x01_P2.54mm_Vertical | ~
 |  | J19 | GPIO64 | Connector_Generic:Conn_01x01 | Connector_PinHeader_2.54mm:PinHeader_1x01_P2.54mm_Vertical | ~
 |  | J20 | ADC1 | Connector_Generic:Conn_01x01 | Connector_PinHeader_2.54mm:PinHeader_1x01_P2.54mm_Vertical | ~
 |  | J21 | ADC0 | Connector_Generic:Conn_01x01 | Connector_PinHeader_2.54mm:PinHeader_1x01_P2.54mm_Vertical | ~
 |  | J22 | SMA-edge | Connector:Conn_Coaxial_Power | Connector_Coaxial:SMA_Samtec_SMA-J-P-X-ST-EM1_EdgeMount | ~
 |  | J23 | SMA-edge | Connector:Conn_Coaxial_Power | Connector_Coaxial:SMA_Samtec_SMA-J-P-X-ST-EM1_EdgeMount | ~
 |  | J24 | PSM_IND | Connector_Generic:Conn_01x01 | Connector_PinHeader_2.54mm:PinHeader_1x01_P2.54mm_Vertical | ~
 |  | J25 | W/AP | Connector_Generic:Conn_01x02 | Connector_PinHeader_2.54mm:PinHeader_1x02_P2.54mm_Vertical_SMD_Pin1Left | ~
 |  | J26 | UART1_unused | Connector_Generic:Conn_01x03 | Connector_PinHeader_2.54mm:PinHeader_1x03_P2.54mm_Vertical_SMD_Pin1Left | ~
 |  | J27 | USB_B_Micro | Connector:USB_B_Micro | Connector_USB:USB_Micro-B_Molex_47346-0001 | ~
 |  | J28 | GPIO_PE_spare | Connector_Generic:Conn_01x04 | Connector_PinHeader_2.54mm:PinHeader_1x04_P2.54mm_Vertical_SMD_Pin1Left | ~
 |  | J29 | GPIO_PF_spare | Connector_Generic:Conn_01x02 | Connector_PinHeader_2.54mm:PinHeader_1x02_P2.54mm_Vertical_SMD_Pin1Left | ~
 |  | J30 | DebugHeader_Cortex-M_SWD_UART_10p | BrechtVE_DebugHeader:DebugHeader_Cortex-M_SWD_UART_10p | Connector_PinHeader_1.27mm:PinHeader_2x05_P1.27mm_Vertical_SMD
 |  | J31 | DebugHeader_Cortex-M_JTAG_10p_TagConnect | BrechtVE_DebugHeader:DebugHeader_Cortex-M_SWD_UART_10p_TagConnect | Connector:Tag-Connect_TC2050-IDC-NL_2x05_P1.27mm_Vertical
 |  | J32 | RESET_button | Connector_Generic:Conn_01x02 | Connector_JST:JST_XH_B2B-XH-A_1x02_P2.50mm_Vertical | ~
 |  | J33 | DebugHeader_UART_4p | BrechtVE_DebugHeader:DebugHeader_UART_4p | Connector_PinHeader_2.54mm:PinHeader_1x04_P2.54mm_Vertical
 |  | J34 | 230V input | Connector_Generic:Conn_01x02 | Connector_Phoenix_PTSA_extra:PhoenixContact_PTSA_1,5_2-G-3,5_1x02_P3.50mm_Angled | ~
 |  | JP1 | I_BG96 | Device:Jumper_NC_Small | Connector_PinHeader_2.54mm:PinHeader_1x02_P2.54mm_Vertical | ~
 |  | JP2 | I_1V8 | Device:Jumper_NC_Small | Connector_PinHeader_2.54mm:PinHeader_1x02_P2.54mm_Vertical | ~
 |  | JP3 | GND_USIM_GND | Jumper:SolderJumper_2_Open | Jumper:SolderJumper-2_P1.3mm_Open_TrianglePad1.0x1.5mm | ~
 |  | JP4 | USB_BOOT | Jumper:Jumper_3_Bridged12 | Connector_PinHeader_2.54mm:PinHeader_1x03_P2.54mm_Vertical | ~
 |  | JP5 | I_MCU_DI | Device:Jumper_NC_Small | Connector_PinHeader_2.54mm:PinHeader_1x02_P2.54mm_Vertical | ~
 |  | JP6 | I_LPM8640 | Device:Jumper_NC_Small | Connector_PinHeader_2.54mm:PinHeader_1x02_P2.54mm_Vertical | ~
 |  | JP7 | I_MCU_AN | Device:Jumper_NC_Small | Connector_PinHeader_2.54mm:PinHeader_1x02_P2.54mm_Vertical | ~
 |  | JP8 | GND_GNDA | Device:Jumper_NC_Small | Connector_PinHeader_2.54mm:PinHeader_1x02_P2.54mm_Vertical | ~
 |  | JP9 | I_3V3 | Device:Jumper_NC_Small | Connector_PinHeader_2.54mm:PinHeader_1x02_P2.54mm_Vertical | ~
 |  | JP10 | I_3V8 | Device:Jumper_NC_Small | Connector_PinHeader_2.54mm:PinHeader_1x02_P2.54mm_Vertical | ~
 |  | JP11 | I_15V | Device:Jumper_NC_Small | Connector_PinHeader_2.54mm:PinHeader_1x02_P2.54mm_Vertical | ~
 |  | L1 | BLM21BD102SN1D | Device:L_Core_Ferrite_Small | Inductor_SMD:L_0805_2012Metric_Pad1.15x1.40mm_HandSolder | ~
 |  | Q1 | 2N7002-7-F | Transistor_FET:2N7002 | Package_TO_SOT_SMD:SOT-23_Handsoldering | https://www.mouser.be/datasheet/2/115/2N7002-1591994.pdf
 |  | Q2 | 2N7002-7-F | Transistor_FET:2N7002 | Package_TO_SOT_SMD:SOT-23_Handsoldering | https://www.mouser.be/datasheet/2/115/2N7002-1591994.pdf
 |  | Q3 | MMUN2233LT1G | Transistor_BJT:DTC143Z | Package_TO_SOT_SMD:SOT-23_Handsoldering | https://www.mouser.be/datasheet/2/308/DTC143Z-D-462208.pdf
 |  | Q4 | MMUN2233LT1G | Transistor_BJT:DTC143Z | Package_TO_SOT_SMD:SOT-23_Handsoldering | https://www.mouser.be/datasheet/2/308/DTC143Z-D-462208.pdf
 |  | R1 | 10 kΩ | Device:R_Small | Resistor_SMD:R_0805_2012Metric_Pad1.15x1.40mm_HandSolder | ~ |  |  |  |  |  | NM
 |  | R2 | 10 kΩ | Device:R_Small | Resistor_SMD:R_0805_2012Metric_Pad1.15x1.40mm_HandSolder | ~ |  |  |  |  |  | NM
 |  | R3 | 10 kΩ | Device:R_Small | Resistor_SMD:R_0805_2012Metric_Pad1.15x1.40mm_HandSolder | ~ |  |  |  | protection
 |  | R4 | 120 kΩ | Device:R_Small | Resistor_SMD:R_0805_2012Metric_Pad1.15x1.40mm_HandSolder | ~ |  |  |  | protection
 |  | R5 | 10 kΩ | Device:R_Small | Resistor_SMD:R_0805_2012Metric_Pad1.15x1.40mm_HandSolder | ~ |  |  |  |  |  | NM
 |  | R6 | 10 kΩ | Device:R_Small | Resistor_SMD:R_0805_2012Metric_Pad1.15x1.40mm_HandSolder | ~ |  |  |  |  |  | NM
 |  | R7 | 10 kΩ | Device:R_Small | Resistor_SMD:R_0805_2012Metric_Pad1.15x1.40mm_HandSolder | ~
 |  | R8 | 10 kΩ | Device:R_Small | Resistor_SMD:R_0805_2012Metric_Pad1.15x1.40mm_HandSolder | ~
 |  | R9 | 0 Ω | Device:R_Small | Resistor_SMD:R_0805_2012Metric_Pad1.15x1.40mm_HandSolder | ~
 |  | R10 | 10 kΩ | Device:R_Small | Resistor_SMD:R_0805_2012Metric_Pad1.15x1.40mm_HandSolder | ~
 |  | R11 | 10 kΩ | Device:R_Small | Resistor_SMD:R_0805_2012Metric_Pad1.15x1.40mm_HandSolder | ~
 |  | R12 | 0 Ω | Device:R_Small | Resistor_SMD:R_0805_2012Metric_Pad1.15x1.40mm_HandSolder | ~
 |  | R13 | 1 MΩ | Device:R_Small | Resistor_SMD:R_0805_2012Metric_Pad1.15x1.40mm_HandSolder | ~
 |  | R14 | 10 kΩ | Device:R_Small | Resistor_SMD:R_0805_2012Metric_Pad1.15x1.40mm_HandSolder | ~
 |  | R15 | 10 kΩ | Device:R_Small | Resistor_SMD:R_0805_2012Metric_Pad1.15x1.40mm_HandSolder | ~
 |  | R16 | 100 Ω | Device:R_Small | Resistor_SMD:R_0805_2012Metric_Pad1.15x1.40mm_HandSolder | ~
 |  | R17 | 0 Ω | Device:R_Small | Resistor_SMD:R_0805_2012Metric_Pad1.15x1.40mm_HandSolder | ~
 |  | R18 | 0 Ω | Device:R_Small | Resistor_SMD:R_0805_2012Metric_Pad1.15x1.40mm_HandSolder | ~
 |  | R19 | 6,2 Ω | Device:R_Small | Resistor_SMD:R_0805_2012Metric_Pad1.15x1.40mm_HandSolder | ~
 |  | R20 | 6,2 Ω | Device:R_Small | Resistor_SMD:R_0805_2012Metric_Pad1.15x1.40mm_HandSolder | ~
 |  | R21 | 0 Ω | Device:R_Small | Resistor_SMD:R_0805_2012Metric_Pad1.15x1.40mm_HandSolder | ~
 |  | R22 | 0 Ω | Device:R_Small | Resistor_SMD:R_0805_2012Metric_Pad1.15x1.40mm_HandSolder | ~
 |  | R23 | 0 Ω | Device:R_Small | Resistor_SMD:R_0805_2012Metric_Pad1.15x1.40mm_HandSolder | ~
 |  | R24 | 0 Ω | Device:R_Small | Resistor_SMD:R_0805_2012Metric_Pad1.15x1.40mm_HandSolder | ~
 |  | R25 | 6,2 Ω | Device:R_Small | Resistor_SMD:R_0805_2012Metric_Pad1.15x1.40mm_HandSolder | ~
 |  | R26 | 6,2 Ω | Device:R_Small | Resistor_SMD:R_0805_2012Metric_Pad1.15x1.40mm_HandSolder | ~
 |  | R27 | 0 Ω | Device:R_Small | Resistor_SMD:R_0805_2012Metric_Pad1.15x1.40mm_HandSolder | ~
 |  | R28 | 0 Ω | Device:R_Small | Resistor_SMD:R_0805_2012Metric_Pad1.15x1.40mm_HandSolder | ~
 |  | R29 | 10 kΩ | Device:R_Small | Resistor_SMD:R_0805_2012Metric_Pad1.15x1.40mm_HandSolder | ~ |  |  |  | protection
 |  | R30 | 120 kΩ | Device:R_Small | Resistor_SMD:R_0805_2012Metric_Pad1.15x1.40mm_HandSolder | ~ |  |  |  | protection
 |  | R31 | 0 Ω | Device:R_Small | Resistor_SMD:R_0805_2012Metric_Pad1.15x1.40mm_HandSolder | ~
 |  | R32 | 0 Ω | Device:R_Small | Resistor_SMD:R_0805_2012Metric_Pad1.15x1.40mm_HandSolder | ~
 |  | R33 | 0 Ω | Device:R_Small | Resistor_SMD:R_0805_2012Metric_Pad1.15x1.40mm_HandSolder | ~
 |  | R34 | 0 Ω | Device:R_Small | Resistor_SMD:R_0805_2012Metric_Pad1.15x1.40mm_HandSolder | ~
 |  | R35 | 0 Ω | Device:R_Small | Resistor_SMD:R_0805_2012Metric_Pad1.15x1.40mm_HandSolder | ~
 |  | R36 | 0 Ω | Device:R_Small | Resistor_SMD:R_0805_2012Metric_Pad1.15x1.40mm_HandSolder | ~
 |  | R37 | 0 Ω | Device:R_Small | Resistor_SMD:R_0805_2012Metric_Pad1.15x1.40mm_HandSolder | ~
 |  | R38 | 0 Ω | Device:R_Small | Resistor_SMD:R_0805_2012Metric_Pad1.15x1.40mm_HandSolder | ~
 |  | R39 | 0 Ω | Device:R_Small | Resistor_SMD:R_0805_2012Metric_Pad1.15x1.40mm_HandSolder | ~
 |  | R40 | 0 Ω | Device:R_Small | Resistor_SMD:R_0805_2012Metric_Pad1.15x1.40mm_HandSolder | ~
 |  | R41 | 100 Ω | Device:R_Small | Resistor_SMD:R_0805_2012Metric_Pad1.15x1.40mm_HandSolder | ~
 |  | R42 | 15 kΩ | Device:R_Small | Resistor_SMD:R_0805_2012Metric_Pad1.15x1.40mm_HandSolder | ~
 |  | R43 | 51 kΩ | Device:R_Small | Resistor_SMD:R_0805_2012Metric_Pad1.15x1.40mm_HandSolder | ~
 |  | R44 | 10 kΩ | Device:R_Small | Resistor_SMD:R_0805_2012Metric_Pad1.15x1.40mm_HandSolder | ~
 |  | R45 | 1 kΩ | Device:R_Small | Resistor_SMD:R_0805_2012Metric_Pad1.15x1.40mm_HandSolder | ~ |  |  |  | protection
 |  | R46 | 2.2 kΩ | Device:R_Small | Resistor_SMD:R_0805_2012Metric_Pad1.15x1.40mm_HandSolder | ~ |  |  |  | protection
 |  | R47 | 2,2 kΩ | Device:R_Small | Resistor_SMD:R_0805_2012Metric_Pad1.15x1.40mm_HandSolder | ~
 |  | R48 | 1 MΩ | Device:R_Small | Resistor_SMD:R_0805_2012Metric_Pad1.15x1.40mm_HandSolder | ~
 |  | R49 | 2,2 kΩ | Device:R_Small | Resistor_SMD:R_0805_2012Metric_Pad1.15x1.40mm_HandSolder | ~
 |  | R50 | 1 Ω | Device:R_Small | Resistor_SMD:R_0805_2012Metric_Pad1.15x1.40mm_HandSolder | ~
 |  | R51 | 10 kΩ | Device:R_Small | Resistor_SMD:R_0805_2012Metric_Pad1.15x1.40mm_HandSolder | ~
 |  | R52 | 1 kΩ | Device:R_Small | Resistor_SMD:R_0805_2012Metric_Pad1.15x1.40mm_HandSolder | ~
 |  | R53 | 100 Ω | Device:R_Small | Resistor_SMD:R_0805_2012Metric_Pad1.15x1.40mm_HandSolder | ~
 |  | R54 | 100 Ω | Device:R_Small | Resistor_SMD:R_0805_2012Metric_Pad1.15x1.40mm_HandSolder | ~
 |  | R55 | 100 kΩ | Device:R_Small | Resistor_SMD:R_0805_2012Metric_Pad1.15x1.40mm_HandSolder | ~
 |  | R56 | 100 Ω | Device:R_Small | Resistor_SMD:R_0805_2012Metric_Pad1.15x1.40mm_HandSolder | ~
 |  | R57 | 10 kΩ | Device:R_Small | Resistor_SMD:R_0805_2012Metric_Pad1.15x1.40mm_HandSolder | ~
 |  | R58 | 1 kΩ | Device:R_Small | Resistor_SMD:R_0805_2012Metric_Pad1.15x1.40mm_HandSolder | ~
 |  | R59 | 1, 47 kΩ | Device:R_Small | Resistor_SMD:R_0805_2012Metric_Pad1.15x1.40mm_HandSolder | ~
 |  | R60 | 10 kΩ | Device:R_Small | Resistor_SMD:R_0805_2012Metric_Pad1.15x1.40mm_HandSolder | ~
 |  | RV1 | ERZ-E08A391CS | Device:Varistor | Varistor:RV_Disc_D12mm_W6.1mm_P7.5mm | ~
 |  | SW1 | SW_Push | Switch:SW_Push | Button_Switch_SMD:SW_SPST_FSMSM | ~
 |  | SW2 | SW_Push | Switch:SW_Push | Button_Switch_SMD:SW_SPST_FSMSM | ~
 |  | U1 | TXS0104EPWR | Logic_LevelTranslator_extra:TXS0104EPWR | Package_SO:TSSOP-14_4.4x5mm_P0.65mm | http://www.ti.com/lit/ds/symlink/txs0104e.pdf
 |  | U2 | Sparkfun_20x4_serLCD | Display_Character_extra:Sparkfun_20x4_serLCD | Display_extra:Sparkfun_20x4_serLCD | https://www.sparkfun.com/products/14074
 |  | U3 | LMP8640 | Amplifier_Current:LMP8640 | Package_TO_SOT_SMD:SOT-23-6_Handsoldering | http://www.ti.com/lit/ds/symlink/lmp8640.pdf
 |  | U4 | LMP8640 | Amplifier_Current:LMP8640 | Package_TO_SOT_SMD:SOT-23-6_Handsoldering | http://www.ti.com/lit/ds/symlink/lmp8640.pdf
 |  | U5 | LMP8640 | Amplifier_Current:LMP8640 | Package_TO_SOT_SMD:SOT-23-6_Handsoldering | http://www.ti.com/lit/ds/symlink/lmp8640.pdf
 |  | U6 | LMP8640 | Amplifier_Current:LMP8640 | Package_TO_SOT_SMD:SOT-23-6_Handsoldering | http://www.ti.com/lit/ds/symlink/lmp8640.pdf
 |  | U7 | TXB0108PWR | Logic_LevelTranslator_extra:TXB0108PWR | Package_SO:TSSOP-20_4.4x6.5mm_P0.65mm | http://www.ti.com/lit/ds/symlink/txb0108.pdf
 |  | U8 | nanoSIM_JAE_SF72S006VBAR2500 | Connector_extra:nanoSIM_JAE_SF72S006VBAR2500 | Connector_Card_extra:nanoSIM_JAE_SF72S006VBAR2500 | https://www.mouser.be/datasheet/2/206/B-0282-2E_SF72-1100798.pdf
 |  | U9 | Quectel_BG96 | RF_GSM_extra:Quectel_BG96 | Package_LGA_extra:Quectel_BG96_LGA102
 |  | U10 | EFM32HG222 | MCU_SiliconLabs_extra:EFM32HG222 | Package_QFP:TQFP-48_7x7mm_P0.5mm
 |  | U11 | TLV75533PDBV | Regulator_Linear:TLV75533PDBV | Package_TO_SOT_SMD:SOT-23-5 | http://www.ti.com/lit/ds/symlink/tlv755p.pdf
 |  | U12 | RAC03-3.8SC | Converter_ACDC_extra:RAC03-3.8SC | Converter_ACDC_extra:RAC03-3.8SC | https://www.mouser.be/datasheet/2/468/RAC03-C-1711223.pdf
 |  | U13 | MEE1S0315SC | Converter_DCDC_extra:MEE1S0315SC | Converter_DCDC:Converter_DCDC_Murata_MEE1SxxxxSC_THT | https://www.mouser.be/datasheet/2/281/MEE1%20Series-1186048.pdf
 |  | Y1 | 32,768 kHz | Device:Crystal_Small | Crystal:Crystal_SMD_2012-2Pin_2.0x1.2mm_HandSoldering | ~ |  |  |  |  | 12,5 pF |  |  | +- 20 ppm
 |  | Y2 | 24 MHz | Device:Crystal_GND24_Small | Crystal:Crystal_SMD_5032-4Pin_5.0x3.2mm | ~ |  |  |  |  | 8 pF |  |  | +- 20 ppm
Collated Components:
Item | Qty | Reference(s) | Value | LibPart | Footprint | Datasheet | Class | Comment | Comment2 | Function | Load capacitance | Mounted | Placement | Tolerance | Type
1 | 19 | C1, C2, C3, C4, C6, C7, C8, C9, C12, C15, C18, C20, C22, C29, C31, C32, C34, C42, C44 | 100 nF | Device:C_Small | Capacitor_SMD:C_0805_2012Metric_Pad1.15x1.40mm_HandSolder | ~ |  |  |  | optional |  |  | CH4 |  | MLCC
2 | 1 | C5 | 1 nF | Device:C_Small | Capacitor_SMD:C_0805_2012Metric_Pad1.15x1.40mm_HandSolder | ~
3 | 2 | C10, C13 | 470 µF | Device:CP_Small | Capacitor_Tantalum_SMD:CP_EIA-7343-43_Kemet-X_Pad2.25x2.55mm_HandSolder | ~ |  |  |  |  |  | NM | VBAT_BB_alt |  | LOW ESR
4 | 2 | C11, C21 | 100 µF | Device:C_Small | Capacitor_SMD:C_1206_3216Metric_Pad1.42x1.75mm_HandSolder | ~ |  |  |  |  |  |  | VBAT_BB |  | LOW ESR
5 | 5 | C14, C16, C17, C23, C24 | 33 pF | Device:C_Small | Capacitor_SMD:C_0805_2012Metric_Pad1.15x1.40mm_HandSolder | ~ |  |  |  |  |  |  | VBAT_BB |  | MLCC
6 | 2 | C19, C25 | 10 pF | Device:C_Small | Capacitor_SMD:C_0805_2012Metric_Pad1.15x1.40mm_HandSolder | ~ |  |  |  |  |  |  | VBAT_BB |  | MLCC
7 | 1 | C26 | 2,2 µF | Device:C_Small | Capacitor_SMD:C_0805_2012Metric_Pad1.15x1.40mm_HandSolder | ~ |  |  |  | optional
8 | 4 | C27, C28, C35, C41 | 10 nF | Device:C_Small | Capacitor_SMD:C_0805_2012Metric_Pad1.15x1.40mm_HandSolder | ~ |  |  |  | optional |  |  | AVDD_0
9 | 3 | C30, C33, C36 | 10 µF | Device:C_Small | Capacitor_SMD:C_0805_2012Metric_Pad1.15x1.40mm_HandSolder | ~ |  |  |  |  |  |  | IOVDD_0
10 | 2 | C37, C38 | 18 pF | Device:C_Small | Capacitor_SMD:C_0805_2012Metric_Pad1.15x1.40mm_HandSolder | ~
11 | 2 | C39, C40 | 12 pF | Device:C_Small | Capacitor_SMD:C_0805_2012Metric_Pad1.15x1.40mm_HandSolder | ~
12 | 3 | C43, C45, C46 | 1 µF | Device:C_Small | Capacitor_SMD:C_0805_2012Metric_Pad1.15x1.40mm_HandSolder | ~ | X5R |  |  |  |  |  | DECOUPLE
13 | 6 | D1, D2, D3, D4, D6, D9 | SP1003-01ETG | Device:D_Zener_Small_ALT | Diode_SMD:D_0402_1005Metric | ~ |  | Unidirectional TVS | General Purpose
14 | 1 | D5 | RED_1V8 | Device:LED_Small_ALT | LED_SMD:LED_0805_2012Metric_Pad1.15x1.40mm_HandSolder | ~
15 | 1 | D7 | YELLOW_STATUS | Device:LED_Small_ALT | LED_SMD:LED_0805_2012Metric_Pad1.15x1.40mm_HandSolder | ~
16 | 2 | D8, D10 | SP3030-01ETG | Device:D_Zener_Small_ALT | Diode_SMD:D_0402_1005Metric | ~ |  | Unidirectional TVS | Low Capacitance
17 | 1 | D11 | GREEN_NETWORK | Device:LED_Small_ALT | LED_SMD:LED_0805_2012Metric_Pad1.15x1.40mm_HandSolder | ~
18 | 1 | D12 | RED_3V3 | Device:LED_Small_ALT | LED_SMD:LED_0805_2012Metric_Pad1.15x1.40mm_HandSolder | ~
19 | 1 | D13 | RED_3V8 | Device:LED_Small_ALT | LED_SMD:LED_0805_2012Metric_Pad1.15x1.40mm_HandSolder | ~
20 | 1 | D14 | RED_15V | Device:LED_Small_ALT | LED_SMD:LED_0805_2012Metric_Pad1.15x1.40mm_HandSolder | ~
21 | 1 | F1 | 1206L110SLYR | Device:Polyfuse_Small | Fuse:Fuse_1206_3216Metric_Pad1.42x1.75mm_HandSolder | ~
22 | 1 | F2 | 32 mA | Device:Fuse_Small | Fuse:Fuseholder_Cylinder-5x20mm_Stelvio-Kontek_PTF78_Horizontal_Open | ~ |  |  |  |  |  |  |  |  | Slow Blow
23 | 1 | G1 | Symbol_OSHW-Logo_11.4x12mm | BrechtVE_Aesthetics:Symbol_OSHW-Logo_11.4x12mm | BrechtVE_Aesthetics:OSHW-Logo_5.7x6mm_SolderMask
24 | 4 | H1, H2, H3, H4 | MountingHole | Mechanical:MountingHole | MountingHole:MountingHole_3.2mm_M3 | ~
25 | 1 | J1 | PCNT | Connector_Generic:Conn_01x02 | Connector_Phoenix_PTSA_extra:PhoenixContact_PTSA_1,5_2-G-3,5_1x02_P3.50mm_Angled | ~
26 | 1 | J2 | PCNT_spare | Connector_Generic:Conn_01x02 | Connector_Phoenix_PTSA_extra:PhoenixContact_PTSA_1,5_2-G-3,5_1x02_P3.50mm_Angled | ~
27 | 1 | J3 | PUSH_button | Connector_Generic:Conn_01x02 | Connector_JST:JST_XH_B2B-XH-A_1x02_P2.50mm_Vertical | ~
28 | 1 | J4 | VL51L1X | Connector_Generic:Conn_01x06 | Connector_Phoenix_PTSA_extra:PhoenixContact_PTSA_1,5_6-G-3,5_1x06_P3.50mm_Angled | ~
29 | 1 | J5 | SHT-30 | Connector_Generic:Conn_01x04 | Connector_Phoenix_PTSA_extra:PhoenixContact_PTSA_1,5_4-G-3,5_1x04_P3.50mm_Angled | ~
30 | 1 | J6 | DS18B20 | Connector_Generic:Conn_01x03 | Connector_Phoenix_PTSA_extra:PhoenixContact_PTSA_1,5_3-G-3,5_1x03_P3.50mm_Angled | ~
31 | 1 | J7 | DS18B20_spare | Connector_Generic:Conn_01x03 | Connector_Phoenix_PTSA_extra:PhoenixContact_PTSA_1,5_3-G-3,5_1x03_P3.50mm_Angled | ~
32 | 4 | J8, J9, J10, J11 | CH4 | Connector_Generic:Conn_01x02 | Connector_Phoenix_PTSA_extra:PhoenixContact_PTSA_1,5_2-G-3,5_1x02_P3.50mm_Angled | ~
33 | 1 | J12 | A1 | Connector_Generic:Conn_01x01 | Connector_PinHeader_2.54mm:PinHeader_1x01_P2.54mm_Vertical | ~
34 | 1 | J13 | B1 | Connector_Generic:Conn_01x01 | Connector_PinHeader_2.54mm:PinHeader_1x01_P2.54mm_Vertical | ~
35 | 1 | J14 | UART2 | Connector_Generic:Conn_01x02 | Connector_PinHeader_2.54mm:PinHeader_1x02_P2.54mm_Vertical_SMD_Pin1Left | ~
36 | 1 | J15 | UART3 | Connector_Generic:Conn_01x02 | Connector_PinHeader_2.54mm:PinHeader_1x02_P2.54mm_Vertical_SMD_Pin1Left | ~
37 | 1 | J16 | PCM | Connector_Generic:Conn_01x04 | Connector_PinHeader_2.54mm:PinHeader_1x04_P2.54mm_Vertical_SMD_Pin1Left | ~
38 | 1 | J17 | I2C | Connector_Generic:Conn_01x02 | Connector_PinHeader_2.54mm:PinHeader_1x02_P2.54mm_Vertical_SMD_Pin1Left | ~
39 | 1 | J18 | GPIO26 | Connector_Generic:Conn_01x01 | Connector_PinHeader_2.54mm:PinHeader_1x01_P2.54mm_Vertical | ~
40 | 1 | J19 | GPIO64 | Connector_Generic:Conn_01x01 | Connector_PinHeader_2.54mm:PinHeader_1x01_P2.54mm_Vertical | ~
41 | 1 | J20 | ADC1 | Connector_Generic:Conn_01x01 | Connector_PinHeader_2.54mm:PinHeader_1x01_P2.54mm_Vertical | ~
42 | 1 | J21 | ADC0 | Connector_Generic:Conn_01x01 | Connector_PinHeader_2.54mm:PinHeader_1x01_P2.54mm_Vertical | ~
43 | 2 | J22, J23 | SMA-edge | Connector:Conn_Coaxial_Power | Connector_Coaxial:SMA_Samtec_SMA-J-P-X-ST-EM1_EdgeMount | ~
44 | 1 | J24 | PSM_IND | Connector_Generic:Conn_01x01 | Connector_PinHeader_2.54mm:PinHeader_1x01_P2.54mm_Vertical | ~
45 | 1 | J25 | W/AP | Connector_Generic:Conn_01x02 | Connector_PinHeader_2.54mm:PinHeader_1x02_P2.54mm_Vertical_SMD_Pin1Left | ~
46 | 1 | J26 | UART1_unused | Connector_Generic:Conn_01x03 | Connector_PinHeader_2.54mm:PinHeader_1x03_P2.54mm_Vertical_SMD_Pin1Left | ~
47 | 1 | J27 | USB_B_Micro | Connector:USB_B_Micro | Connector_USB:USB_Micro-B_Molex_47346-0001 | ~
48 | 1 | J28 | GPIO_PE_spare | Connector_Generic:Conn_01x04 | Connector_PinHeader_2.54mm:PinHeader_1x04_P2.54mm_Vertical_SMD_Pin1Left | ~
49 | 1 | J29 | GPIO_PF_spare | Connector_Generic:Conn_01x02 | Connector_PinHeader_2.54mm:PinHeader_1x02_P2.54mm_Vertical_SMD_Pin1Left | ~
50 | 1 | J30 | DebugHeader_Cortex-M_SWD_UART_10p | BrechtVE_DebugHeader:DebugHeader_Cortex-M_SWD_UART_10p | Connector_PinHeader_1.27mm:PinHeader_2x05_P1.27mm_Vertical_SMD
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

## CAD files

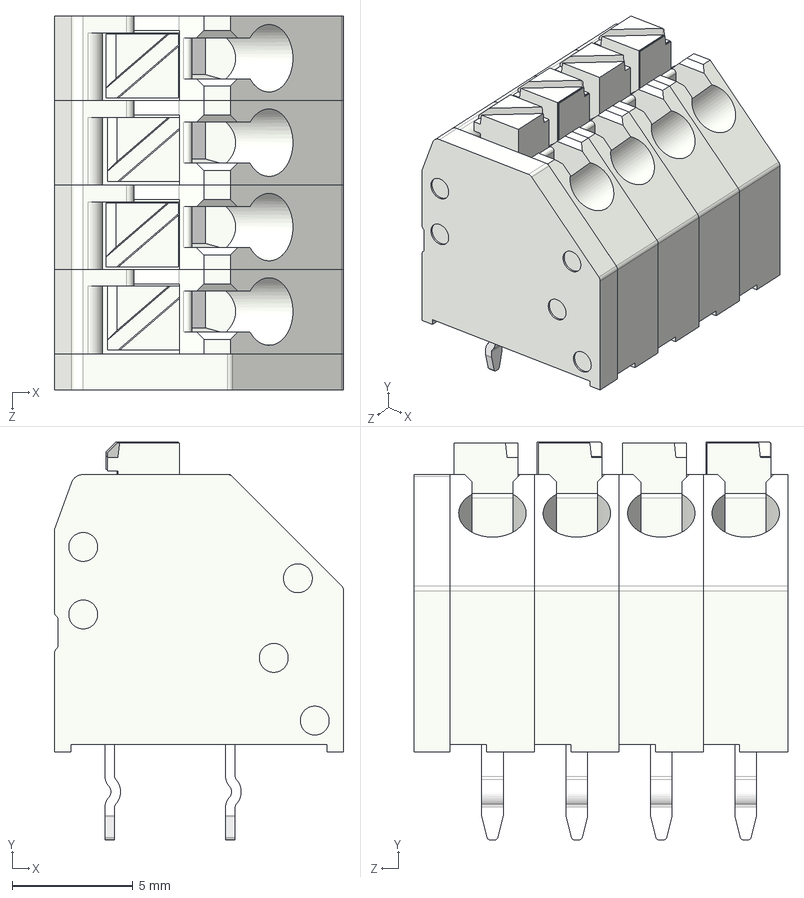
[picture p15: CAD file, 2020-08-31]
hardware/masterthesis-hardware/3D/CUI_DEVICES_TBL002A-350-04GY-2GY.step
12.0 x 16.5 x 15.5 mm
TBL002A-350 - END CAP_Gray
TBL002A-350 - BODY A_Gray x 2
TBL002A-350 - BODY B_Gray x 2
TBL002A-350 - PUSH BUTTON A_Gray x 2
TBL002A-350 - PUSH BUTTON B_Gray x 2

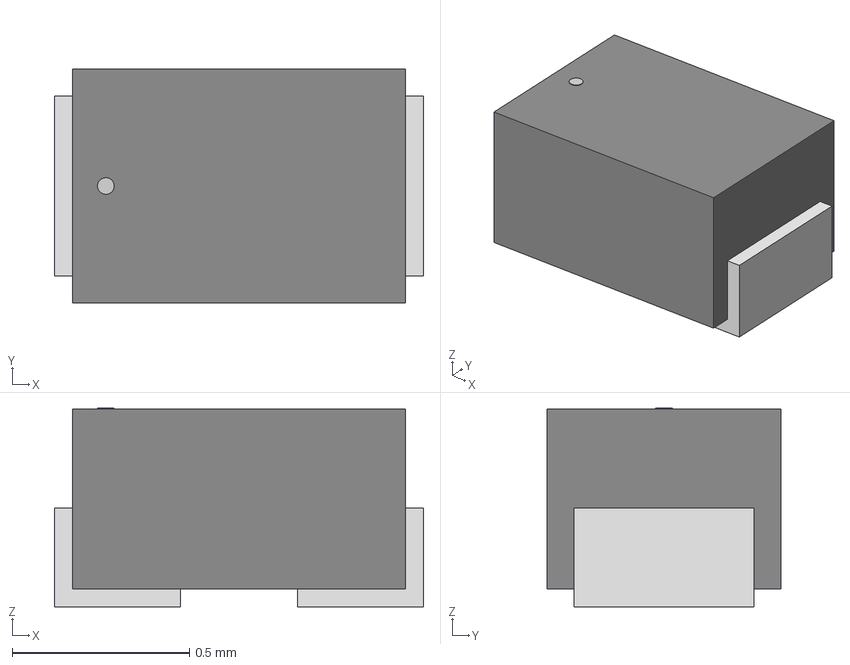
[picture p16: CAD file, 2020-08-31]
hardware/masterthesis-hardware/3D/CPDQR.step
1.04 x 0.66 x 0.561 mm

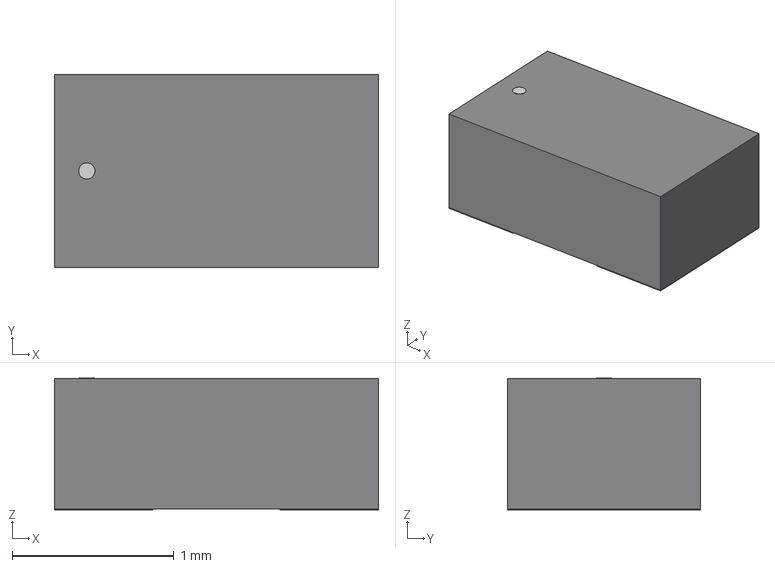
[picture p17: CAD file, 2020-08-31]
hardware/masterthesis-hardware/3D/xtal2_ST2012SB.step
2.01 x 1.19 x 0.815 mm

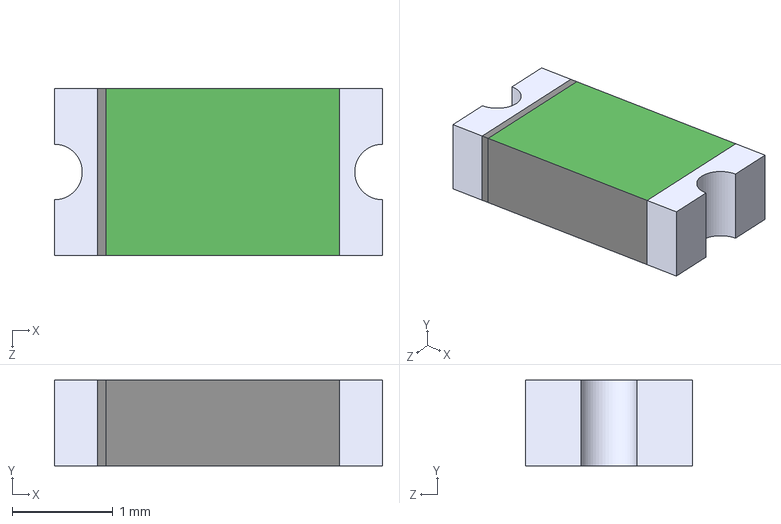
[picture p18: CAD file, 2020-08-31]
hardware/masterthesis-hardware/3D/0ZCJ0010FF2E--3DModel-STEP-56544.STEP
3.25 x 0.85 x 1.65 mm

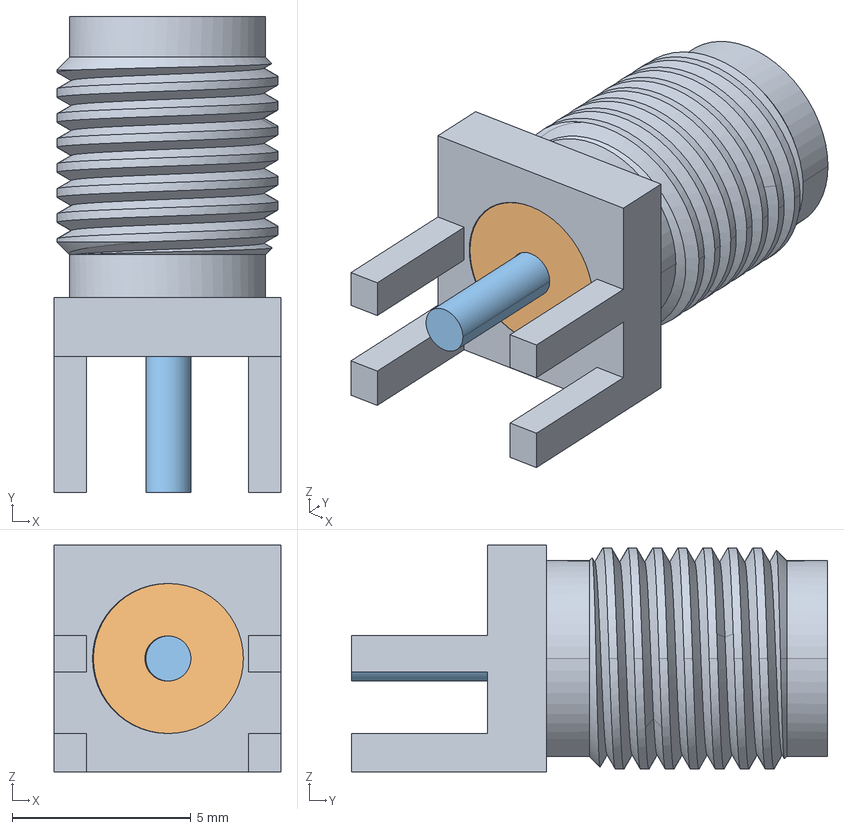
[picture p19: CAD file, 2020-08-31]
hardware/masterthesis-hardware/3D/CON-SMA-EDGE-S.stp
6.35 x 13.3 x 6.35 mm
SMA-K-KE
JIAOLI
ZHEN

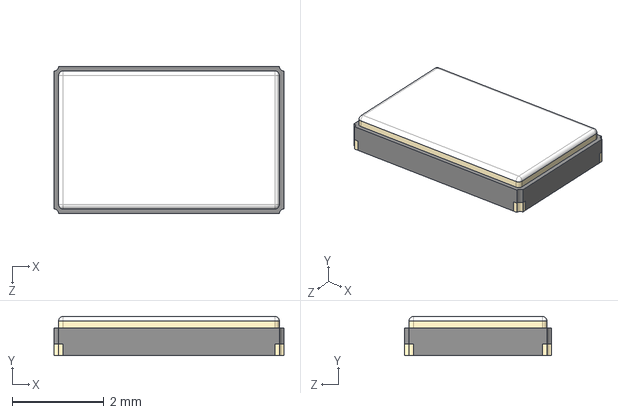
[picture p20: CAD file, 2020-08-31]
hardware/masterthesis-hardware/3D/ECS-100-20-30B-TR--3DModel-STEP-40055.STEP
5.00 x 0.85 x 3.20 mm

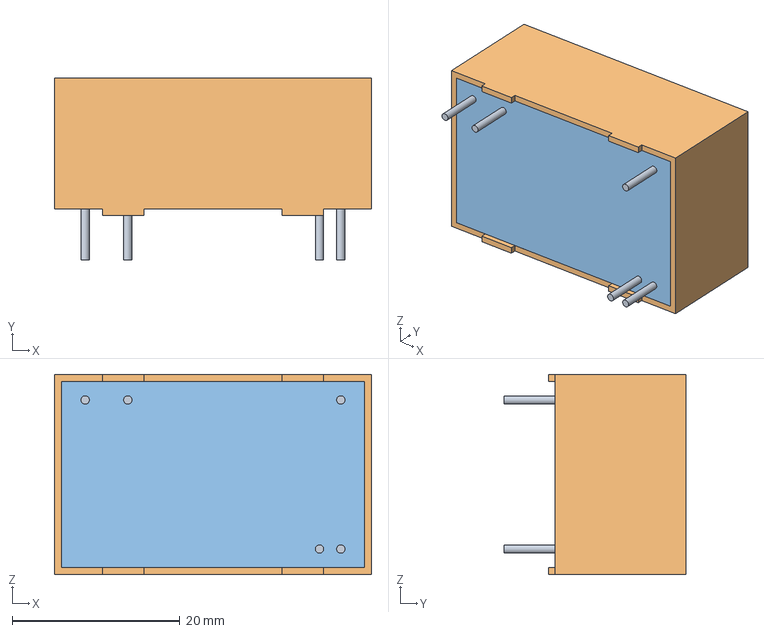
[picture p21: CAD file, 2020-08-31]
hardware/masterthesis-hardware/3D/RAC03-24SC--3DModel-STEP-1.STEP
37.8 x 21.8 x 23.9 mm

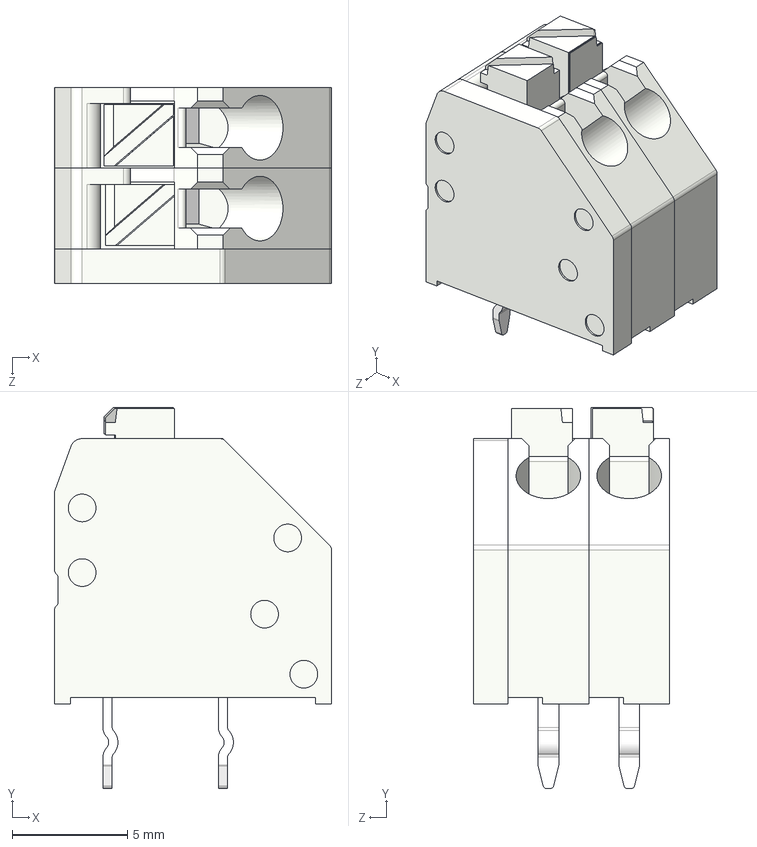
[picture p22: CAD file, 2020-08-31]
hardware/masterthesis-hardware/3D/CUI_DEVICES_TBL002A-350-02GY-2GY.step
12.0 x 16.5 x 8.50 mm
TBL002A-350 - END CAP_Gray
TBL002A-350 - BODY A_Gray
TBL002A-350 - BODY B_Gray
TBL002A-350 - PUSH BUTTON A_Gray
TBL002A-350 - PUSH BUTTON B_Gray

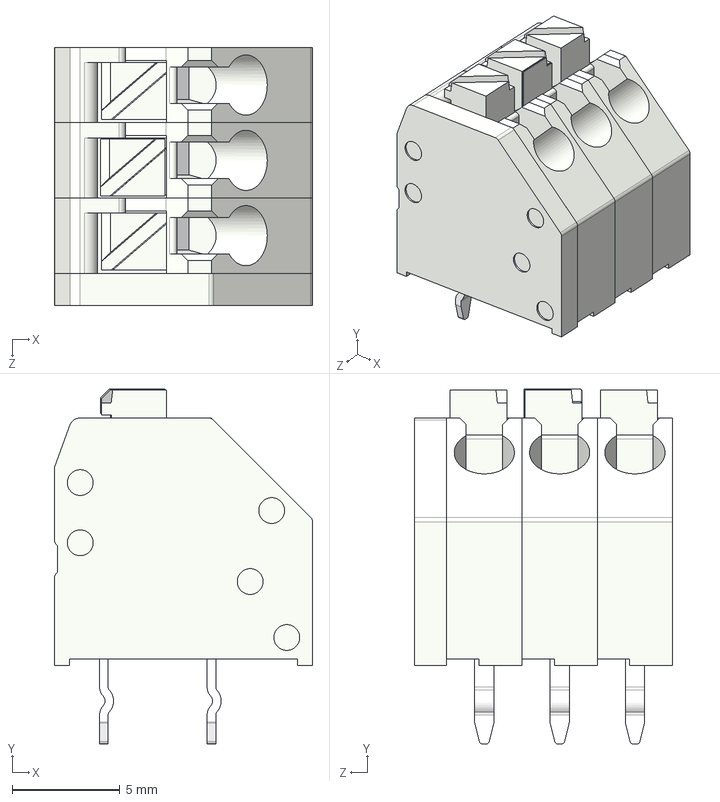
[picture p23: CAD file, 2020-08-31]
hardware/masterthesis-hardware/3D/CUI_DEVICES_TBL002A-350-03GY-2GY.step
12.0 x 16.5 x 12.0 mm
TBL002A-350 - END CAP_Gray
TBL002A-350 - BODY A_Gray x 2
TBL002A-350 - BODY B_Gray
TBL002A-350 - PUSH BUTTON A_Gray x 2
TBL002A-350 - PUSH BUTTON B_Gray

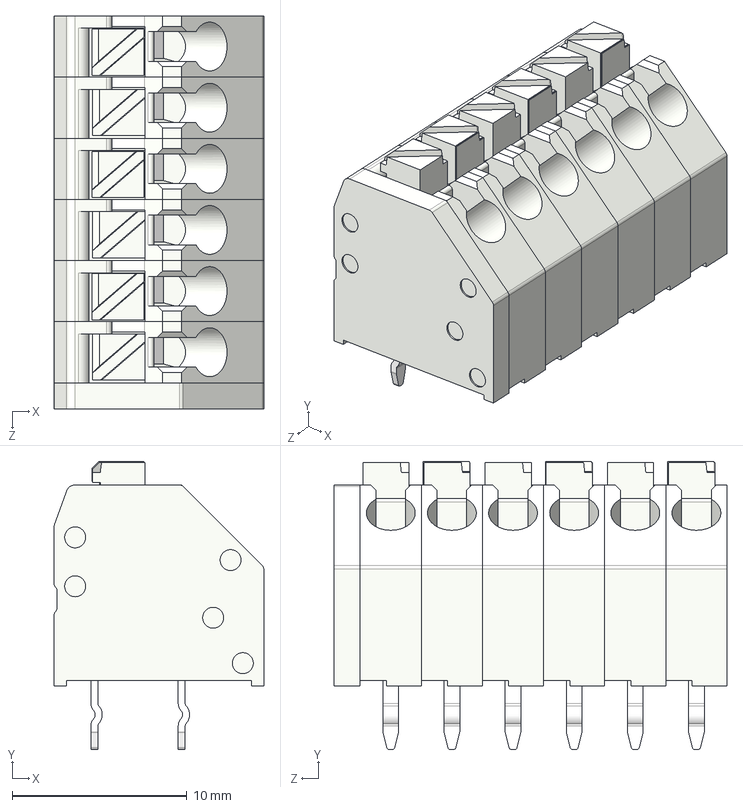
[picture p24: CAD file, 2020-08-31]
hardware/masterthesis-hardware/3D/CUI_DEVICES_TBL002A-350-06GY-2GY.step
12.0 x 16.5 x 22.5 mm
TBL002A-350 - END CAP_Gray
TBL002A-350 - BODY A_Gray x 3
TBL002A-350 - BODY B_Gray x 3
TBL002A-350 - PUSH BUTTON A_Gray x 3
TBL002A-350 - PUSH BUTTON B_Gray x 3

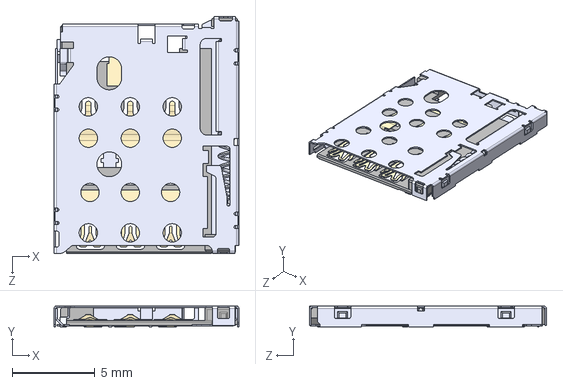
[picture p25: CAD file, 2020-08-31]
hardware/masterthesis-hardware/3D/SF72S006VBAR2500--3DModel-STEP-56544.STEP
11.2 x 1.26 x 14.4 mm

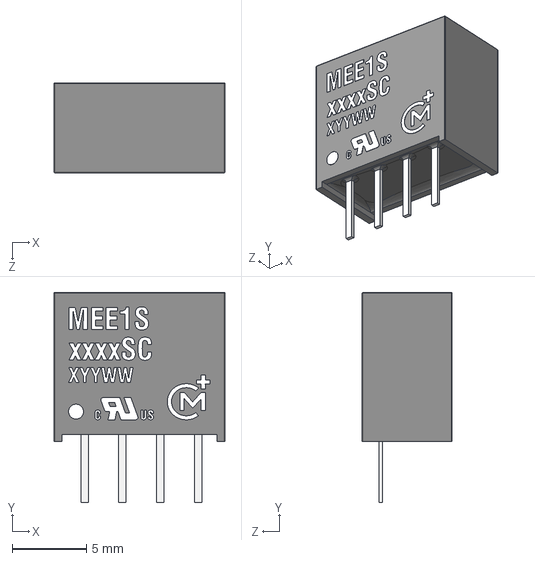
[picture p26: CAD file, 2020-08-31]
hardware/masterthesis-hardware/3D/mps_dcdc_mee1s_sc_a.step
11.5 x 14.1 x 6.07 mm

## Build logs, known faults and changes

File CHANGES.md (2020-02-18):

# Modifications made by Licensee (see section 3.4.b)

## Extract from license

**3.4.** The Licensee may communicate to the public and distribute the modified Documentation (thereby in addition to being a Licensee also becoming a Licensor), always provided that he shall:

- **a)** comply with section 3.1;
- **b)** cause the modified Documentation to carry prominent notices stating that the Licensee has modified the Documentation, with the date and description of the modifications;
- **c)** cause the modified Documentation to carry a new Documentation Location notice if the original Documentation provided for one;
- **d)** make available the modified Documentation at the same level of abstraction as that of the Documentation, in the preferred format for making modifications to it (e.g. the native format of the CAD tool as applicable), and in the event that format is proprietary, in a format viewable with a tool licensed under an OSI-approved license if the proprietary tool can create it; and
- **e)** license the modified Documentation under the terms and conditions of this Licence or, where applicable, a later version of this Licence as may be issued by CERN.

<br/>

## Versions

- v1.0: Initial version (Brecht Van Eeckhoudt - 02/2020)

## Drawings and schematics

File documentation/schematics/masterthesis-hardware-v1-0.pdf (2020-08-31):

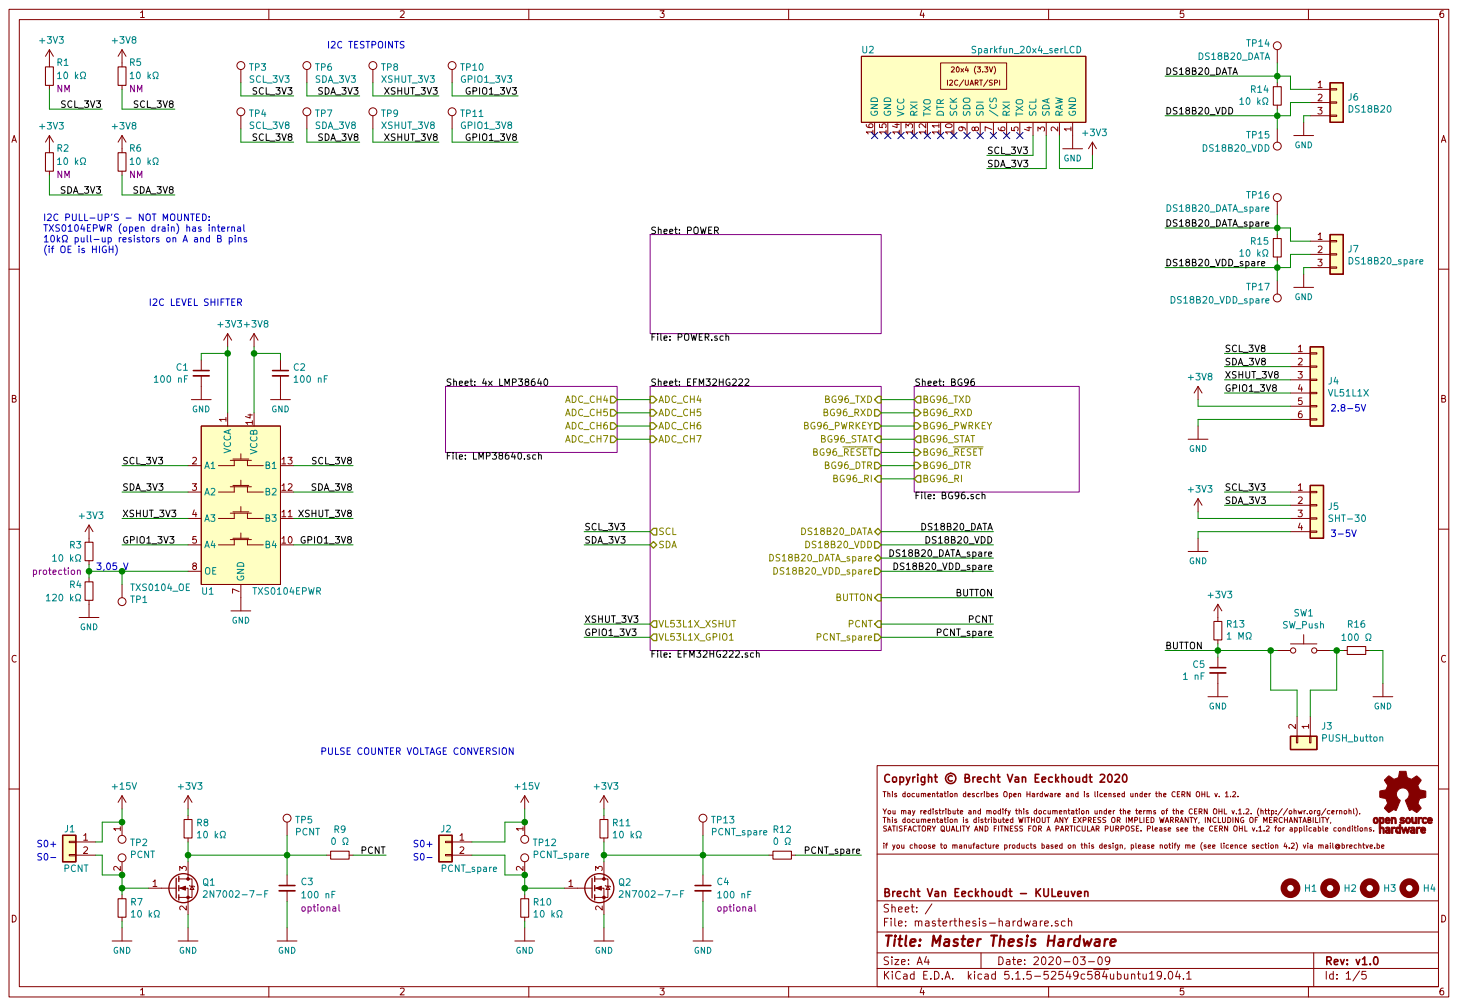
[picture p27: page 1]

1 SCK 10 DTR 11 TXO 12 RXI 13 VCC 14 GND 15 GND 16 RAW

I2C PULL-UP'S - NOT MOUNTED: TXS0104EPWR (open drain) has internal

10k pull-up resistors on A and B pins

PULSE COUNTER VOLTAGE CONVERSION

File: masterthesis-hardware.sch Sheet: / Brecht Van Eeckhoudt - KULeuven Copyright © Brecht Van Eeckhoudt 2020

This documentation describes Open Hardware and is licensed under the CERN OHL v. 1.2.

You may redistribute and modify this documentation under the terms of the CERN OHL v.1.2. (http://ohwr.org/cernohl).

Id: 1/5 Title: Master Thesis Hardware

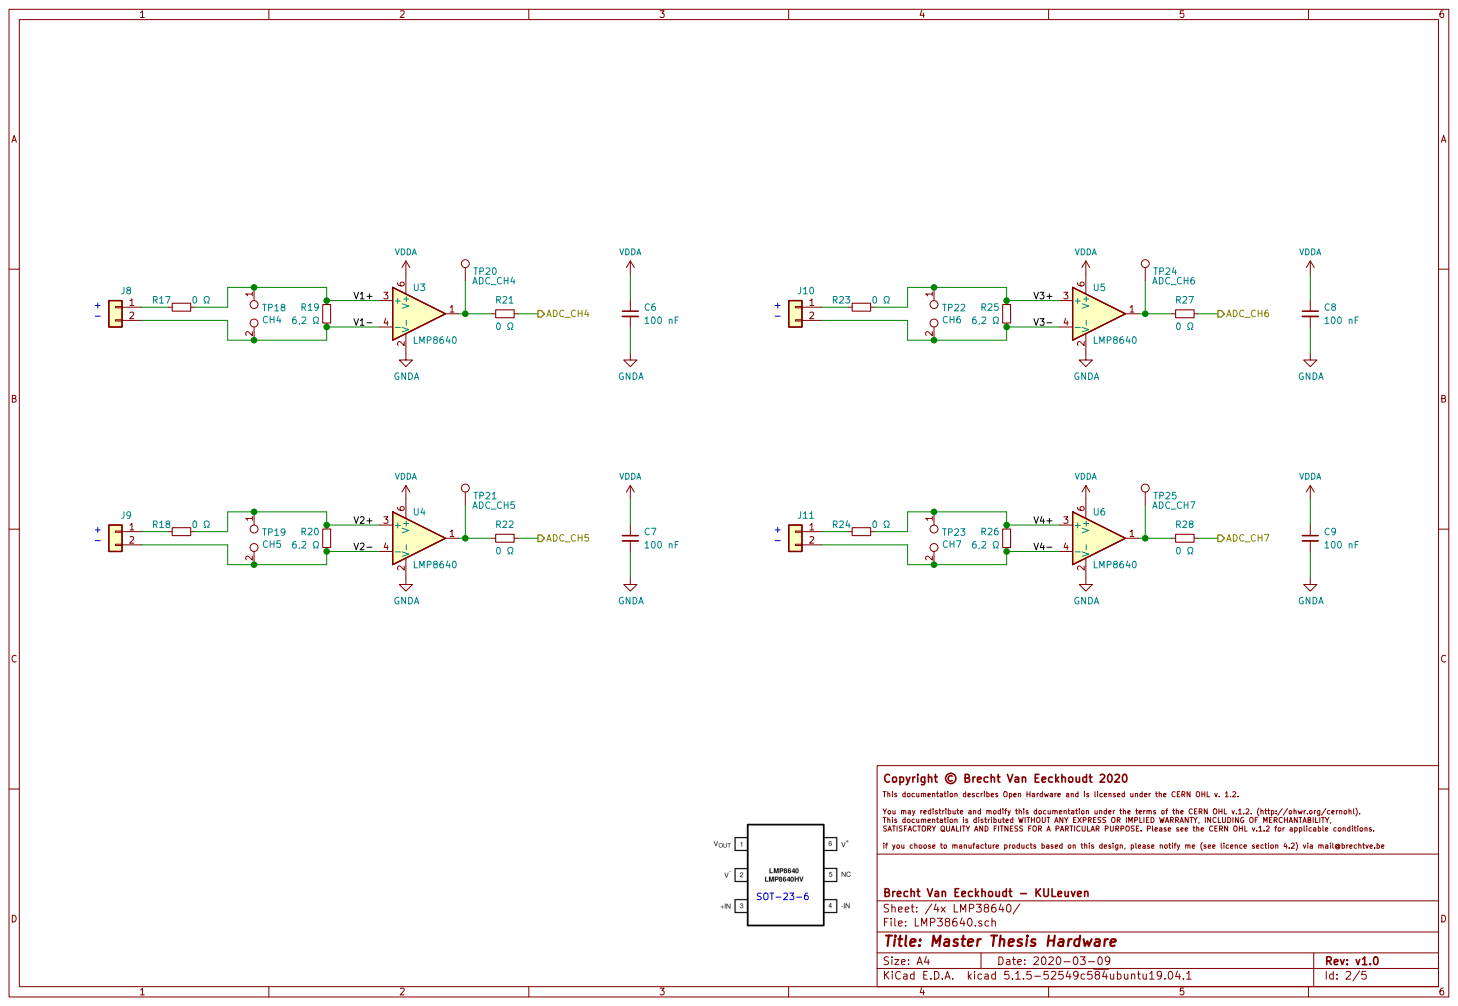
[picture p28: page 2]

if you choose to manufacture products based on this design, please notify me (see licence section 4.2) via mail@brechtve.be GNDA

File: LMP38640.sch Sheet: /4x LMP38640/ Brecht Van Eeckhoudt - KULeuven Copyright © Brecht Van Eeckhoudt 2020

This documentation describes Open Hardware and is licensed under the CERN OHL v. 1.2.

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

Id: 2/5 Title: Master Thesis Hardware

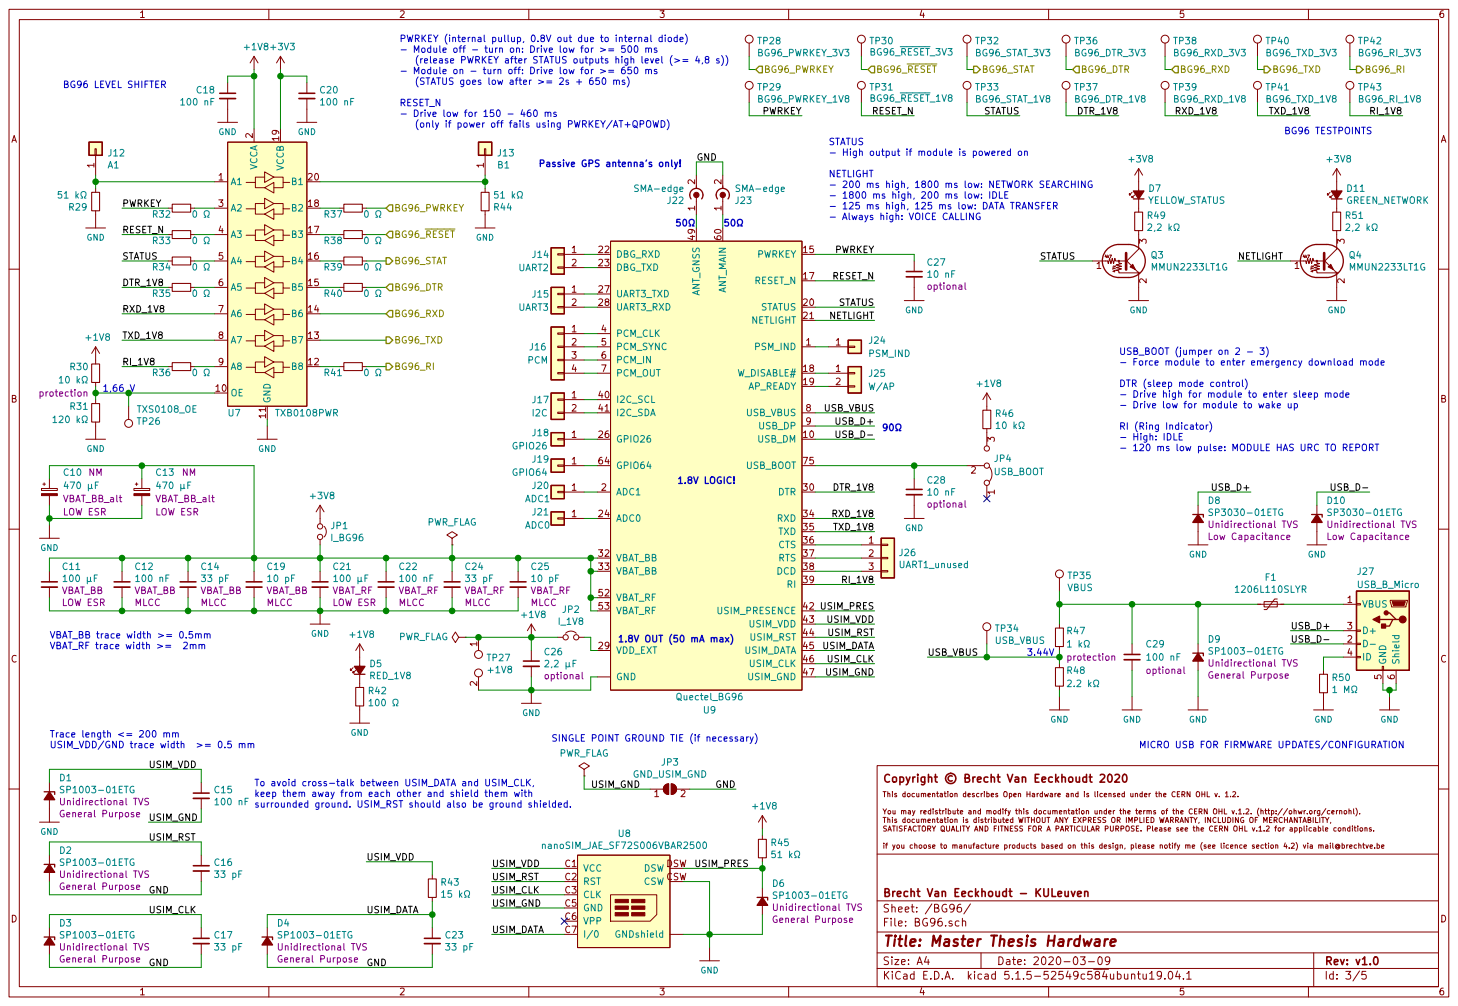
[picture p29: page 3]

PWRKEY (internal pullup, 0.8V out due to internal diode)
- Module off - turn on: Drive low for >= 500 ms
(release PWRKEY after STATUS outputs high level (>= 4,8 s))
- Module on - turn off: Drive low for >= 650 ms
(STATUS goes low after >= 2s + 650 ms) RESET_N
I_BG96 GND C15

- Drive low for 150 - 460 ms

(only if power off fails using PWRKEY/AT+QPOWD) VBAT_BB trace width >= 0.5mm

STATUS
- High output if module is powered on NETLIGHT

- 200 ms high, 1800 ms low: NETWORK SEARCHING
- 1800 ms high, 200 ms low: IDLE
- 125 ms high, 125 ms low: DATA TRANSFER
- Always high: VOICE CALLING

USB_BOOT (jumper on 2 - 3)
- Force module to enter emergency download mode
Unidirectional TVS General Purpose D8SP3030-01ETG

DTR (sleep mode control)
- Drive high for module to enter sleep mode
- Drive low for module to wake up

RI (Ring Indicator)
- High: IDLE
- 120 ms low pulse: MODULE HAS URC TO REPORT

if you choose to manufacture products based on this design, please notify me (see licence section 4.2) via mail@brechtve.be TP34 USB_VBUS GND

SINGLE POINT GROUND TIE (if necessary) Trace length <= 200 mm
USIM_VDD/GND trace width >= 0.5 mm

Unidirectional TVS General Purpose D1SP1003-01ETG

To avoid cross-talk between USIM_DATA and USIM_CLK, keep them away from each other and shield them with

File: BG96.sch Sheet: /BG96/ Brecht Van Eeckhoudt - KULeuven Copyright © Brecht Van Eeckhoudt 2020

Unidirectional TVS General Purpose D3SP1003-01ETG

surrounded ground. USIM_RST should also be ground shielded.

This documentation describes Open Hardware and is licensed under the CERN OHL v. 1.2.

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

Unidirectional TVS General Purpose

Id: 3/5 Title: Master Thesis Hardware

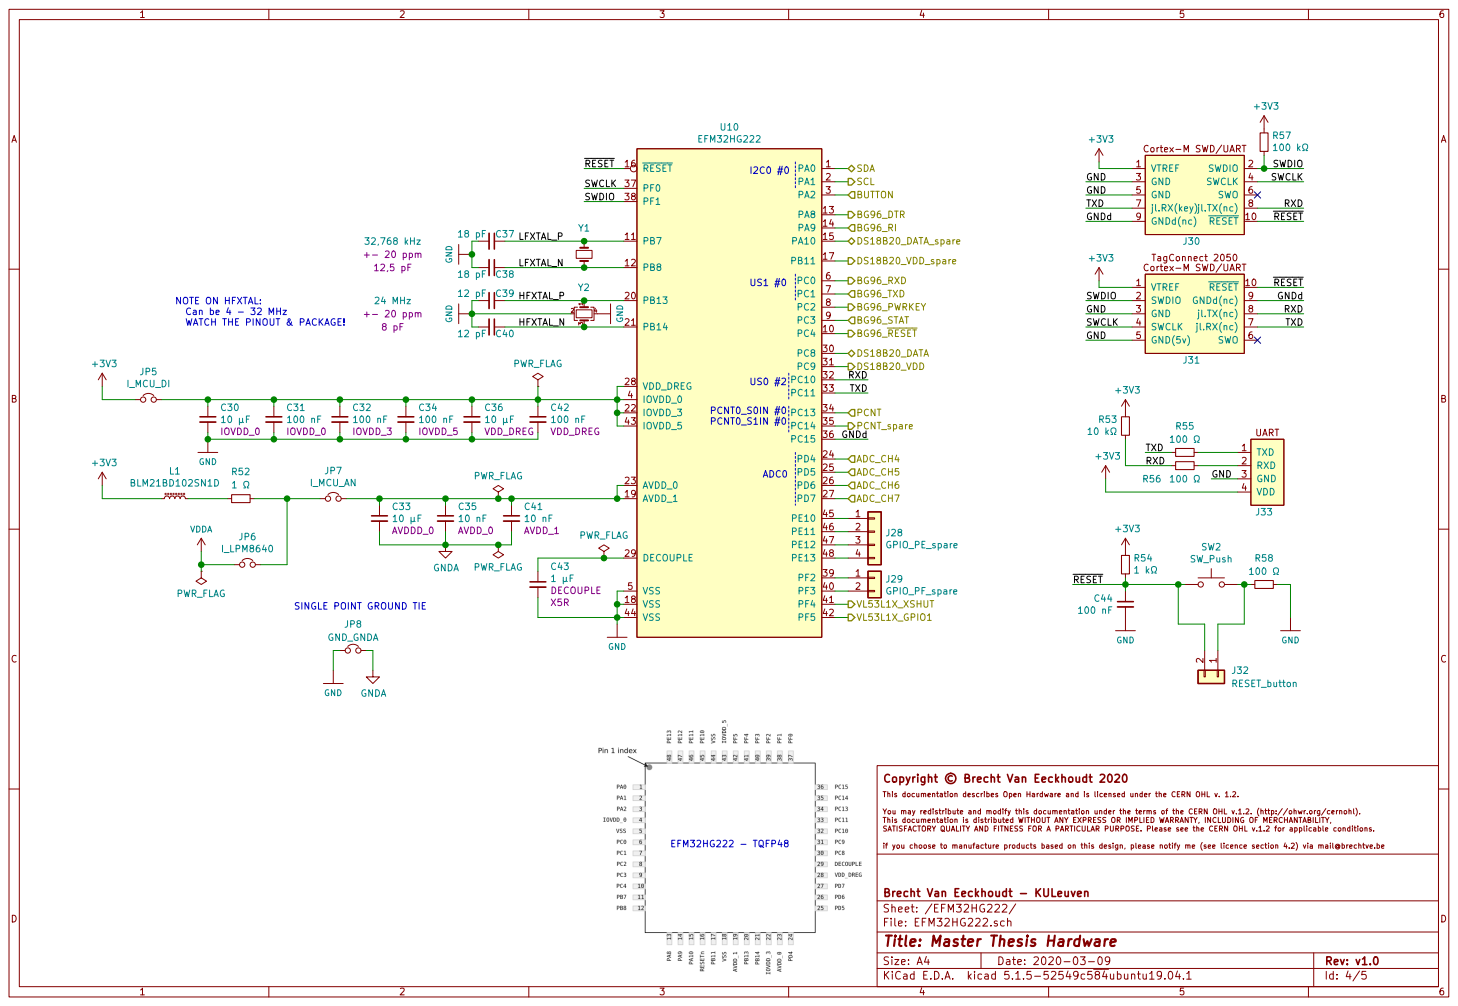
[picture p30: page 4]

Can be 4 - 32 MHz
WATCH THE PINOUT & PACKAGE!

File: EFM32HG222.sch Sheet: /EFM32HG222/ Brecht Van Eeckhoudt - KULeuven Copyright © Brecht Van Eeckhoudt 2020

This documentation describes Open Hardware and is licensed under the CERN OHL v. 1.2.

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

Id: 4/5 Title: Master Thesis Hardware

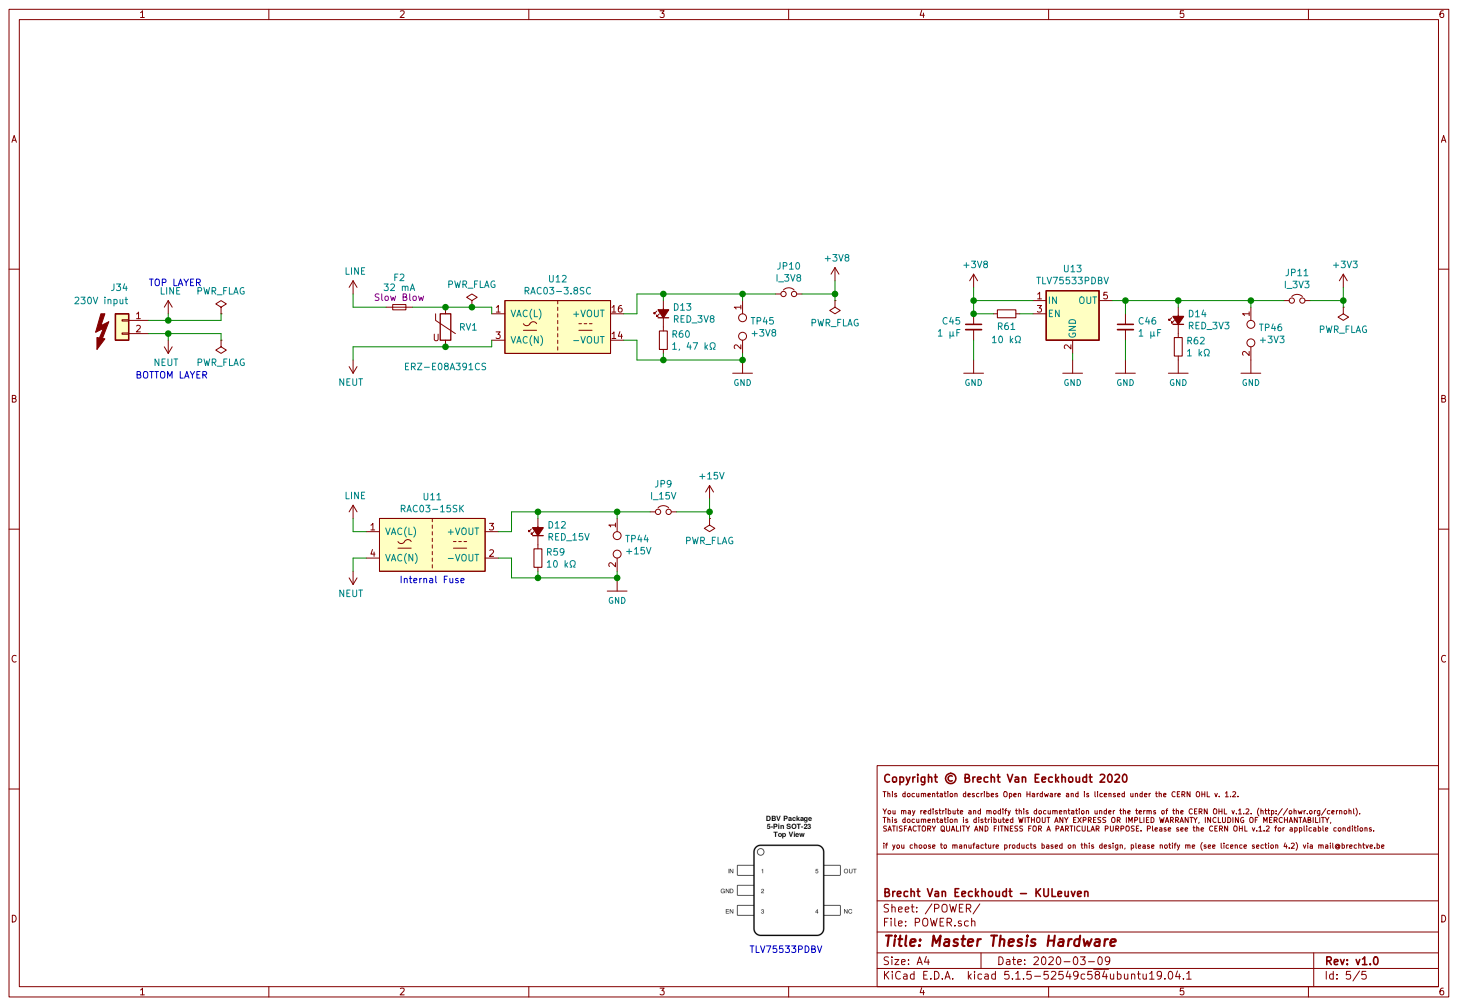
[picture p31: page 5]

LINE NEUT
Internal Fuse TOP LAYER

File: POWER.sch Sheet: /POWER/ Brecht Van Eeckhoudt - KULeuven Copyright © Brecht Van Eeckhoudt 2020

This documentation describes Open Hardware and is licensed under the CERN OHL v. 1.2.

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

Id: 5/5 Title: Master Thesis Hardware

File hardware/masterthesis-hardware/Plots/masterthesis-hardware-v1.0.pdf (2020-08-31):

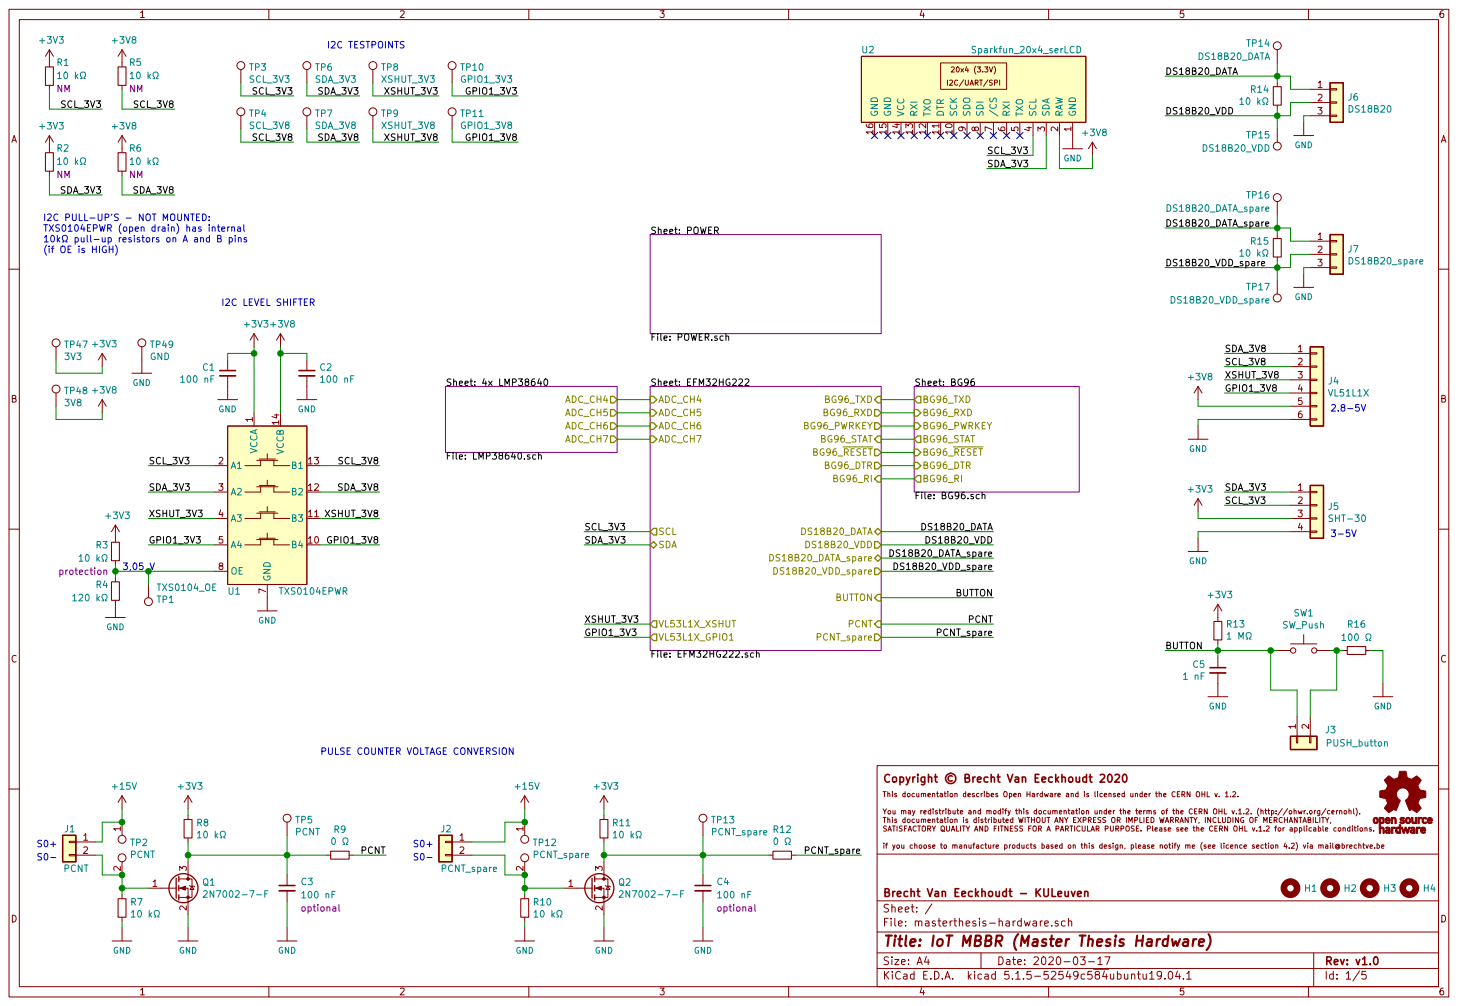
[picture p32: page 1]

1 SCK 10 DTR 11 TXO 12 RXI 13 VCC 14 GND 15 GND 16 RAW

I2C PULL-UP'S - NOT MOUNTED: TXS0104EPWR (open drain) has internal

10k pull-up resistors on A and B pins

PULSE COUNTER VOLTAGE CONVERSION

Id: 1/5 Title: IoT MBBR (Master Thesis Hardware) File: masterthesis-hardware.sch Sheet: / Brecht Van Eeckhoudt - KULeuven Copyright © Brecht Van Eeckhoudt 2020

This documentation describes Open Hardware and is licensed under the CERN OHL v. 1.2.

You may redistribute and modify this documentation under the terms of the CERN OHL v.1.2. (http://ohwr.org/cernohl).

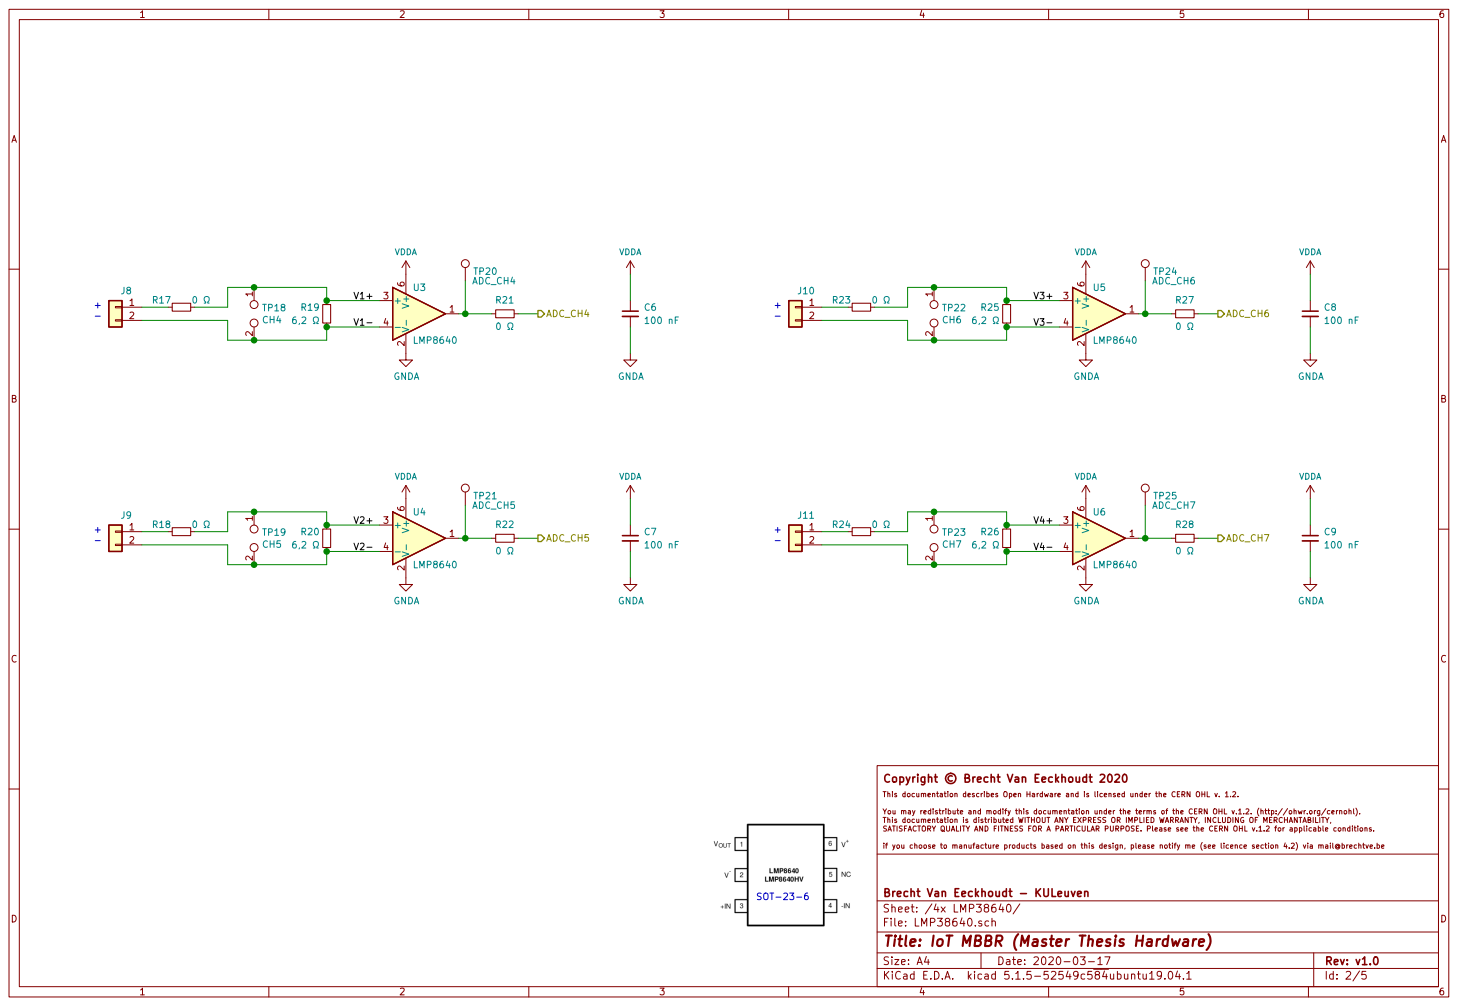
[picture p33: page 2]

if you choose to manufacture products based on this design, please notify me (see licence section 4.2) via mail@brechtve.be GNDA

Id: 2/5 Title: IoT MBBR (Master Thesis Hardware) File: LMP38640.sch Sheet: /4x LMP38640/ Brecht Van Eeckhoudt - KULeuven Copyright © Brecht Van Eeckhoudt 2020

This documentation describes Open Hardware and is licensed under the CERN OHL v. 1.2.

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

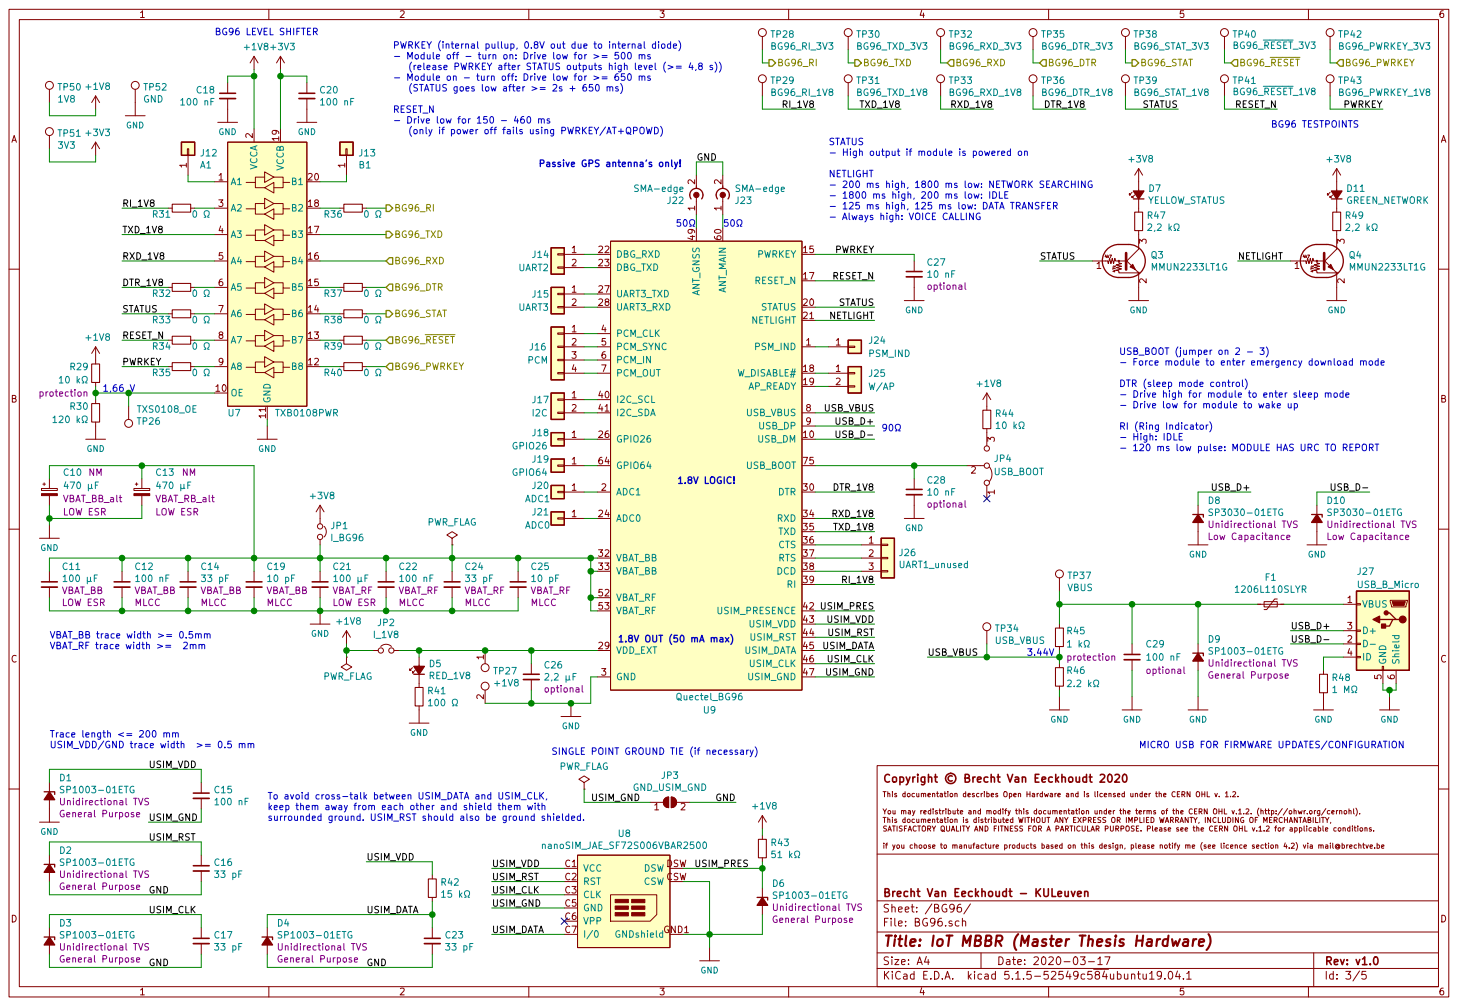
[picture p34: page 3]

BG96 TESTPOINTS MICRO USB FOR FIRMWARE UPDATES/CONFIGURATION
+3V8 GND 47k 4k7 1

PWRKEY (internal pullup, 0.8V out due to internal diode)
- Module off - turn on: Drive low for >= 500 ms
(release PWRKEY after STATUS outputs high level (>= 4,8 s))
- Module on - turn off: Drive low for >= 650 ms
(STATUS goes low after >= 2s + 650 ms) RESET_N

- Drive low for 150 - 460 ms
(only if power off fails using PWRKEY/AT+QPOWD)

- High output if module is powered on NETLIGHT

Passive GPS antenna's only!

- 200 ms high, 1800 ms low: NETWORK SEARCHING
- 1800 ms high, 200 ms low: IDLE
- 125 ms high, 125 ms low: DATA TRANSFER
- Always high: VOICE CALLING
TXD_1V8 RESET_N

USB_BOOT (jumper on 2 - 3)
- Force module to enter emergency download mode
Unidirectional TVS General Purpose D8SP3030-01ETG

DTR (sleep mode control)
- Drive high for module to enter sleep mode
- Drive low for module to wake up

- 120 ms low pulse: MODULE HAS URC TO REPORT VBAT_BB trace width >= 0.5mm

Trace length <= 200 mm
USIM_VDD/GND trace width >= 0.5 mm

SINGLE POINT GROUND TIE (if necessary)
PWR_FLAG

Unidirectional TVS General Purpose D1SP1003-01ETG

Id: 3/5 Title: IoT MBBR (Master Thesis Hardware) File: BG96.sch Sheet: /BG96/ Brecht Van Eeckhoudt - KULeuven Copyright © Brecht Van Eeckhoudt 2020

Unidirectional TVS General Purpose D3SP1003-01ETG

To avoid cross-talk between USIM_DATA and USIM_CLK, keep them away from each other and shield them with

surrounded ground. USIM_RST should also be ground shielded.

This documentation describes Open Hardware and is licensed under the CERN OHL v. 1.2.

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

Unidirectional TVS General Purpose D2SP1003-01ETG

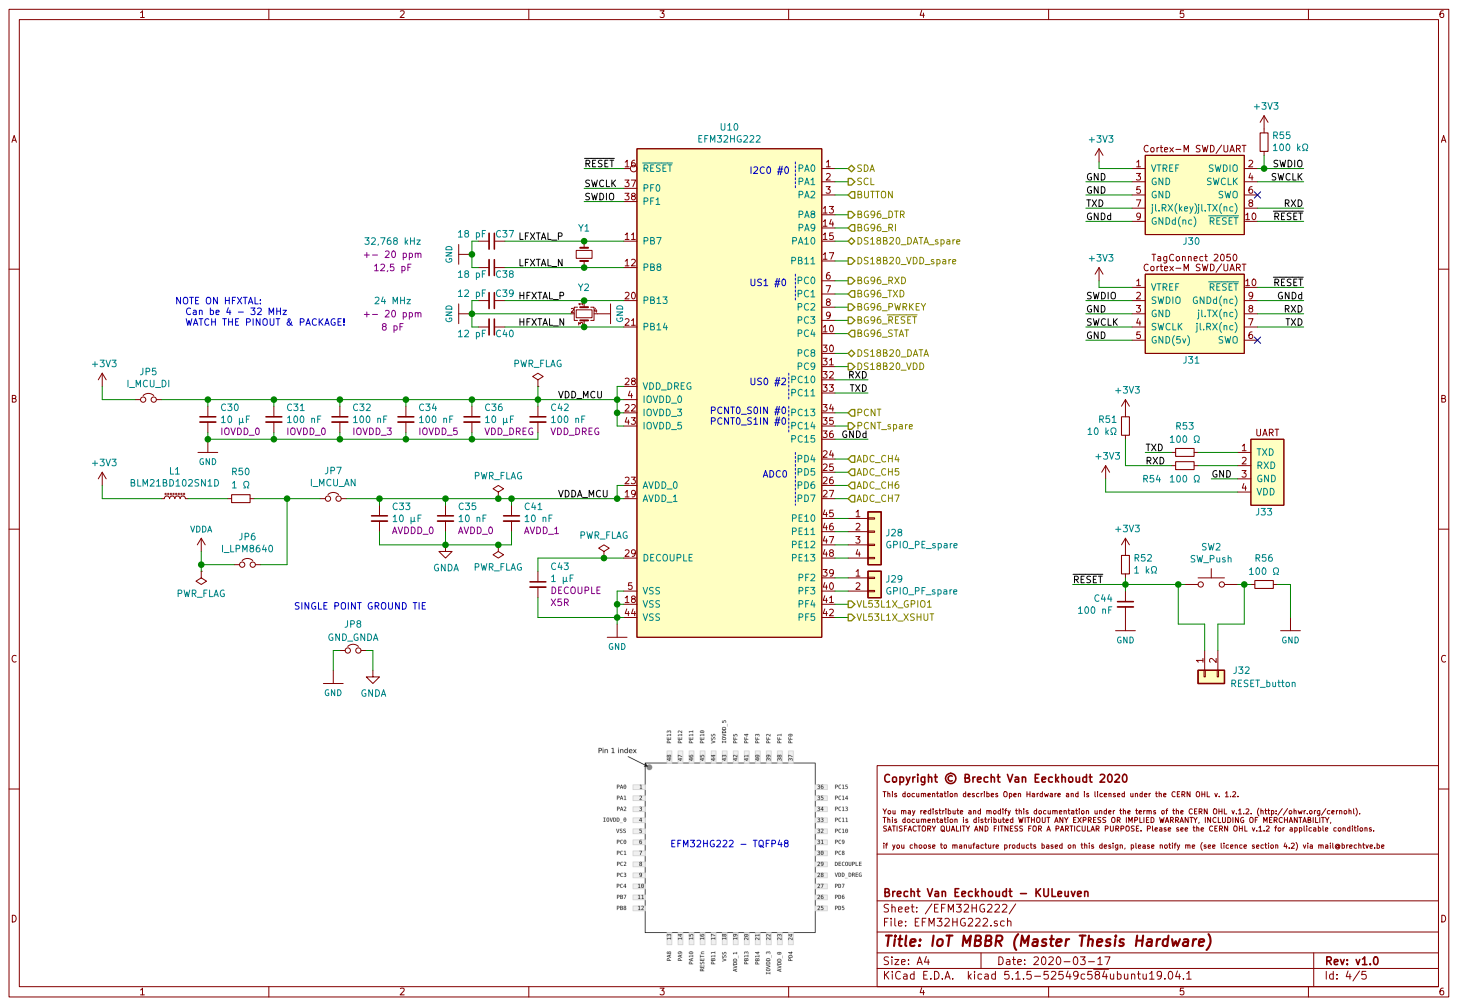
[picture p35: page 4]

Can be 4 - 32 MHz
WATCH THE PINOUT & PACKAGE! SINGLE POINT GROUND TIE

if you choose to manufacture products based on this design, please notify me (see licence section 4.2) via mail@brechtve.be R50

Id: 4/5 Title: IoT MBBR (Master Thesis Hardware) File: EFM32HG222.sch Sheet: /EFM32HG222/ Brecht Van Eeckhoudt - KULeuven Copyright © Brecht Van Eeckhoudt 2020

This documentation describes Open Hardware and is licensed under the CERN OHL v. 1.2.

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

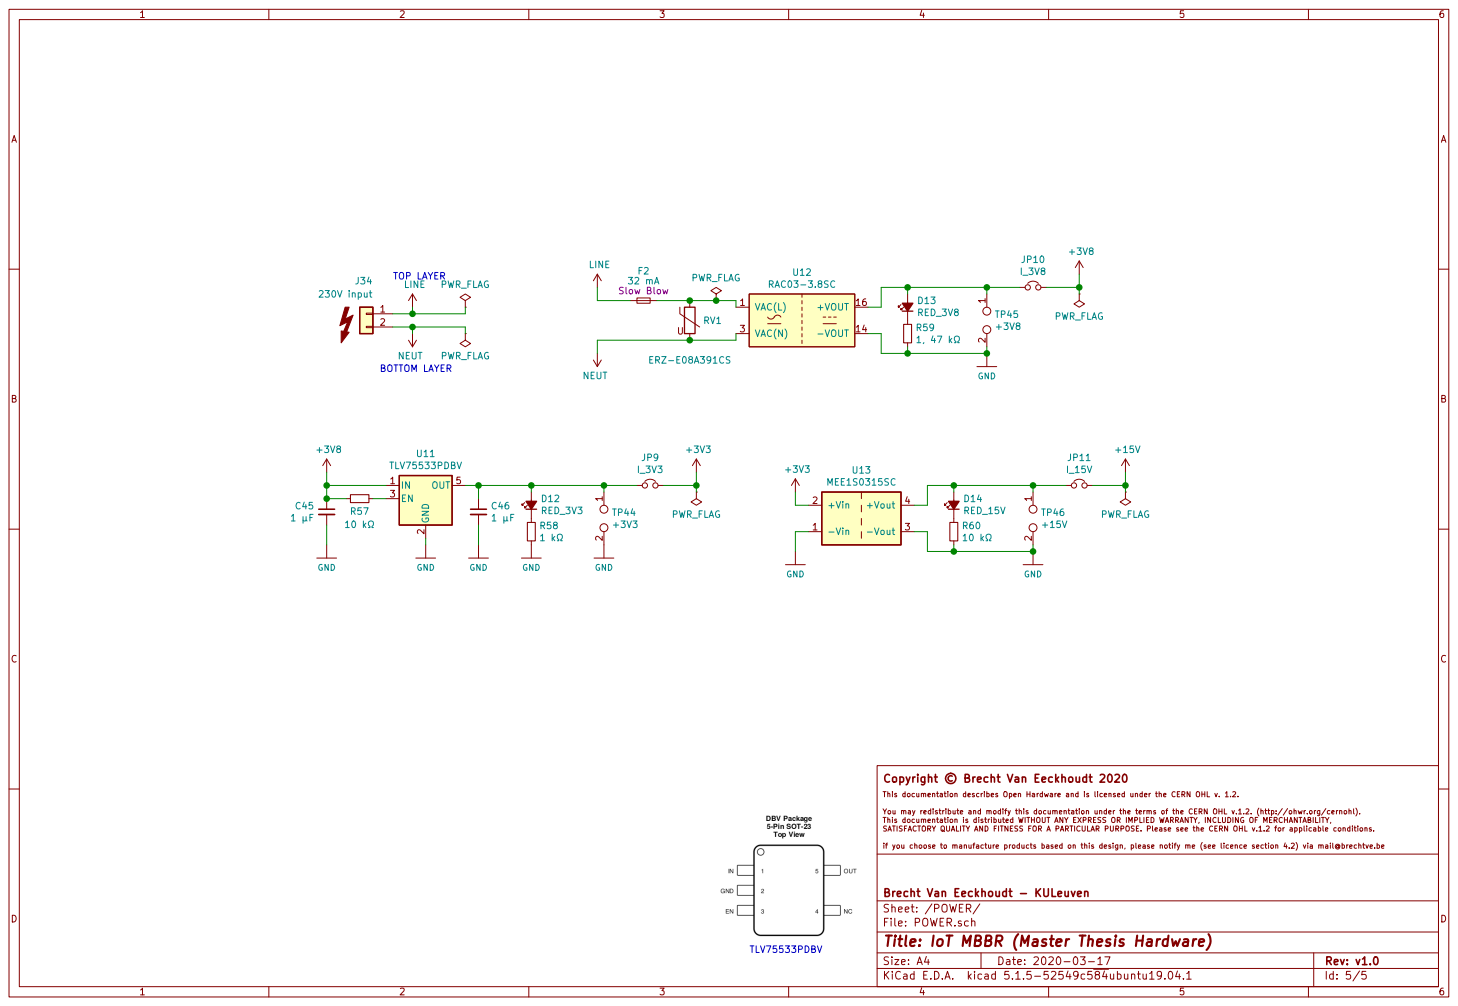
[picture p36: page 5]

Id: 5/5 Title: IoT MBBR (Master Thesis Hardware) File: POWER.sch Sheet: /POWER/ Brecht Van Eeckhoudt - KULeuven Copyright © Brecht Van Eeckhoudt 2020

This documentation describes Open Hardware and is licensed under the CERN OHL v. 1.2.

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

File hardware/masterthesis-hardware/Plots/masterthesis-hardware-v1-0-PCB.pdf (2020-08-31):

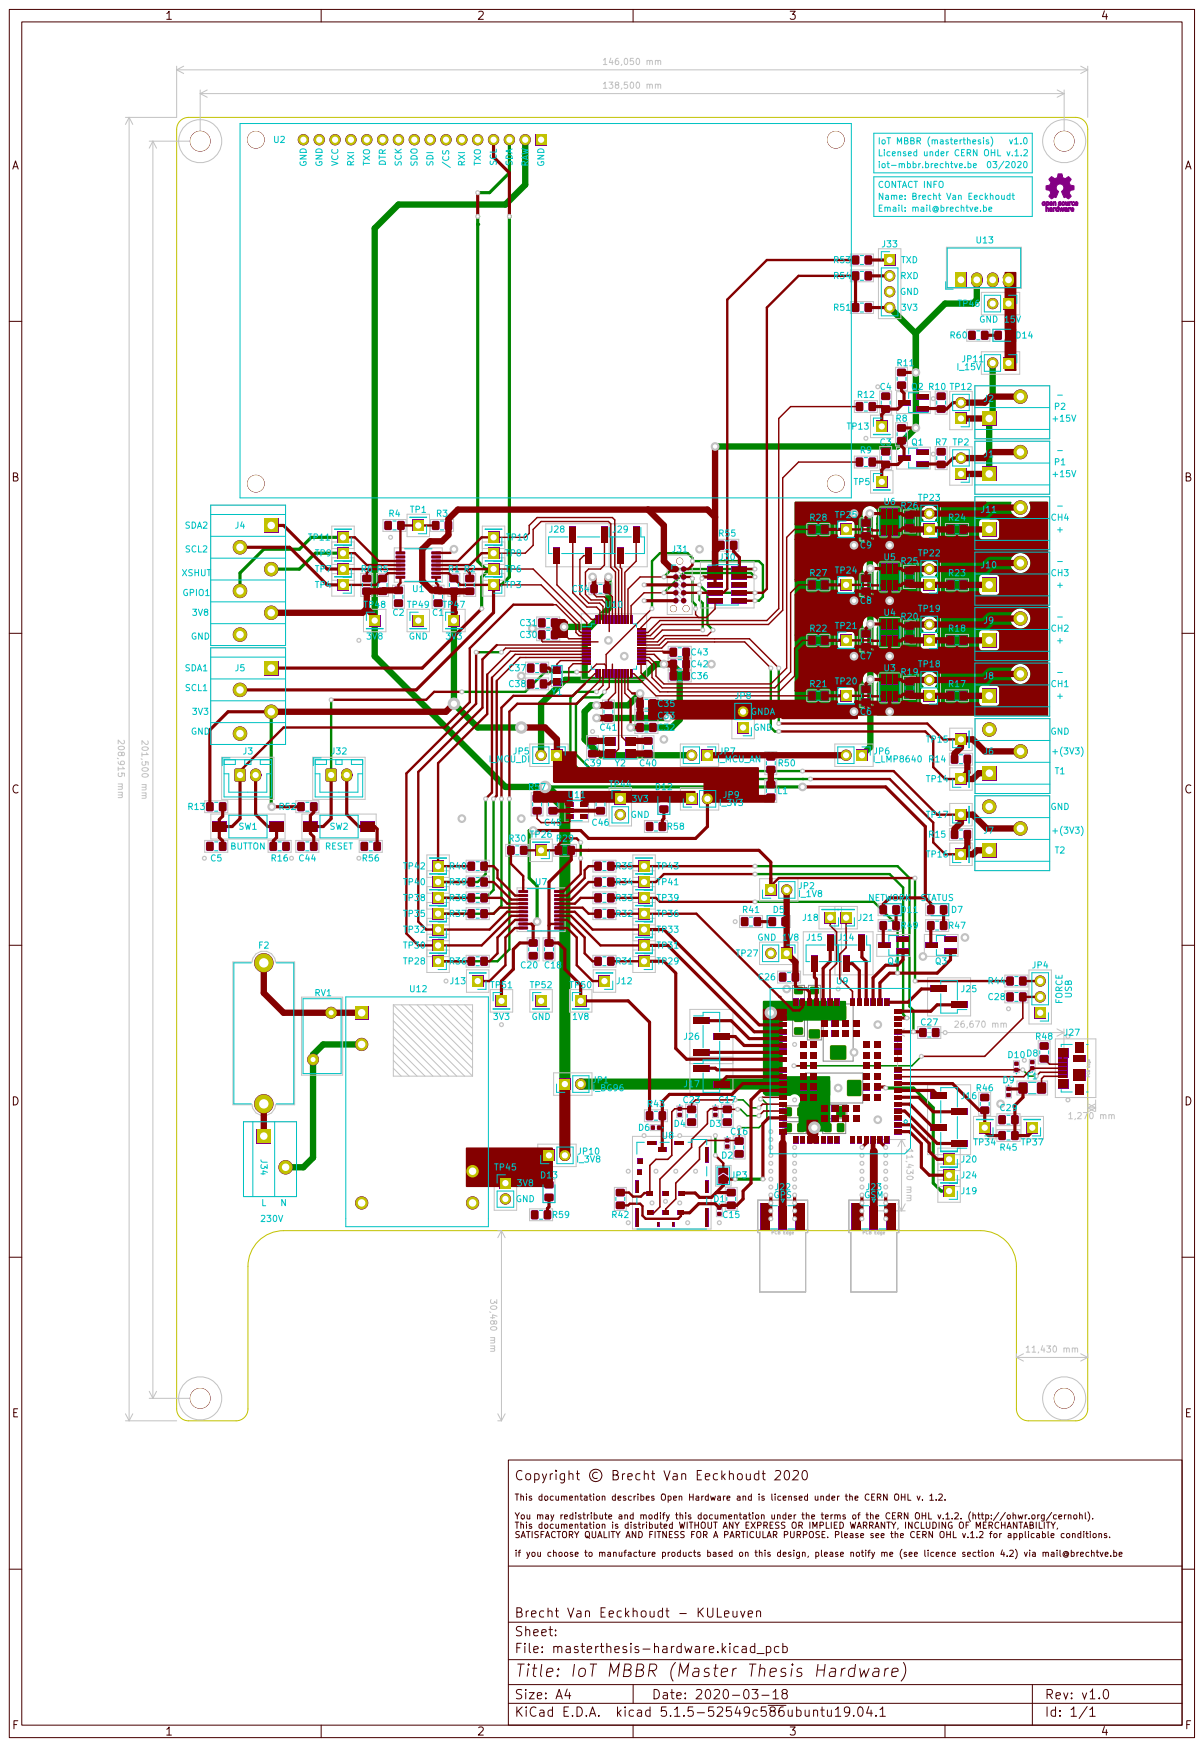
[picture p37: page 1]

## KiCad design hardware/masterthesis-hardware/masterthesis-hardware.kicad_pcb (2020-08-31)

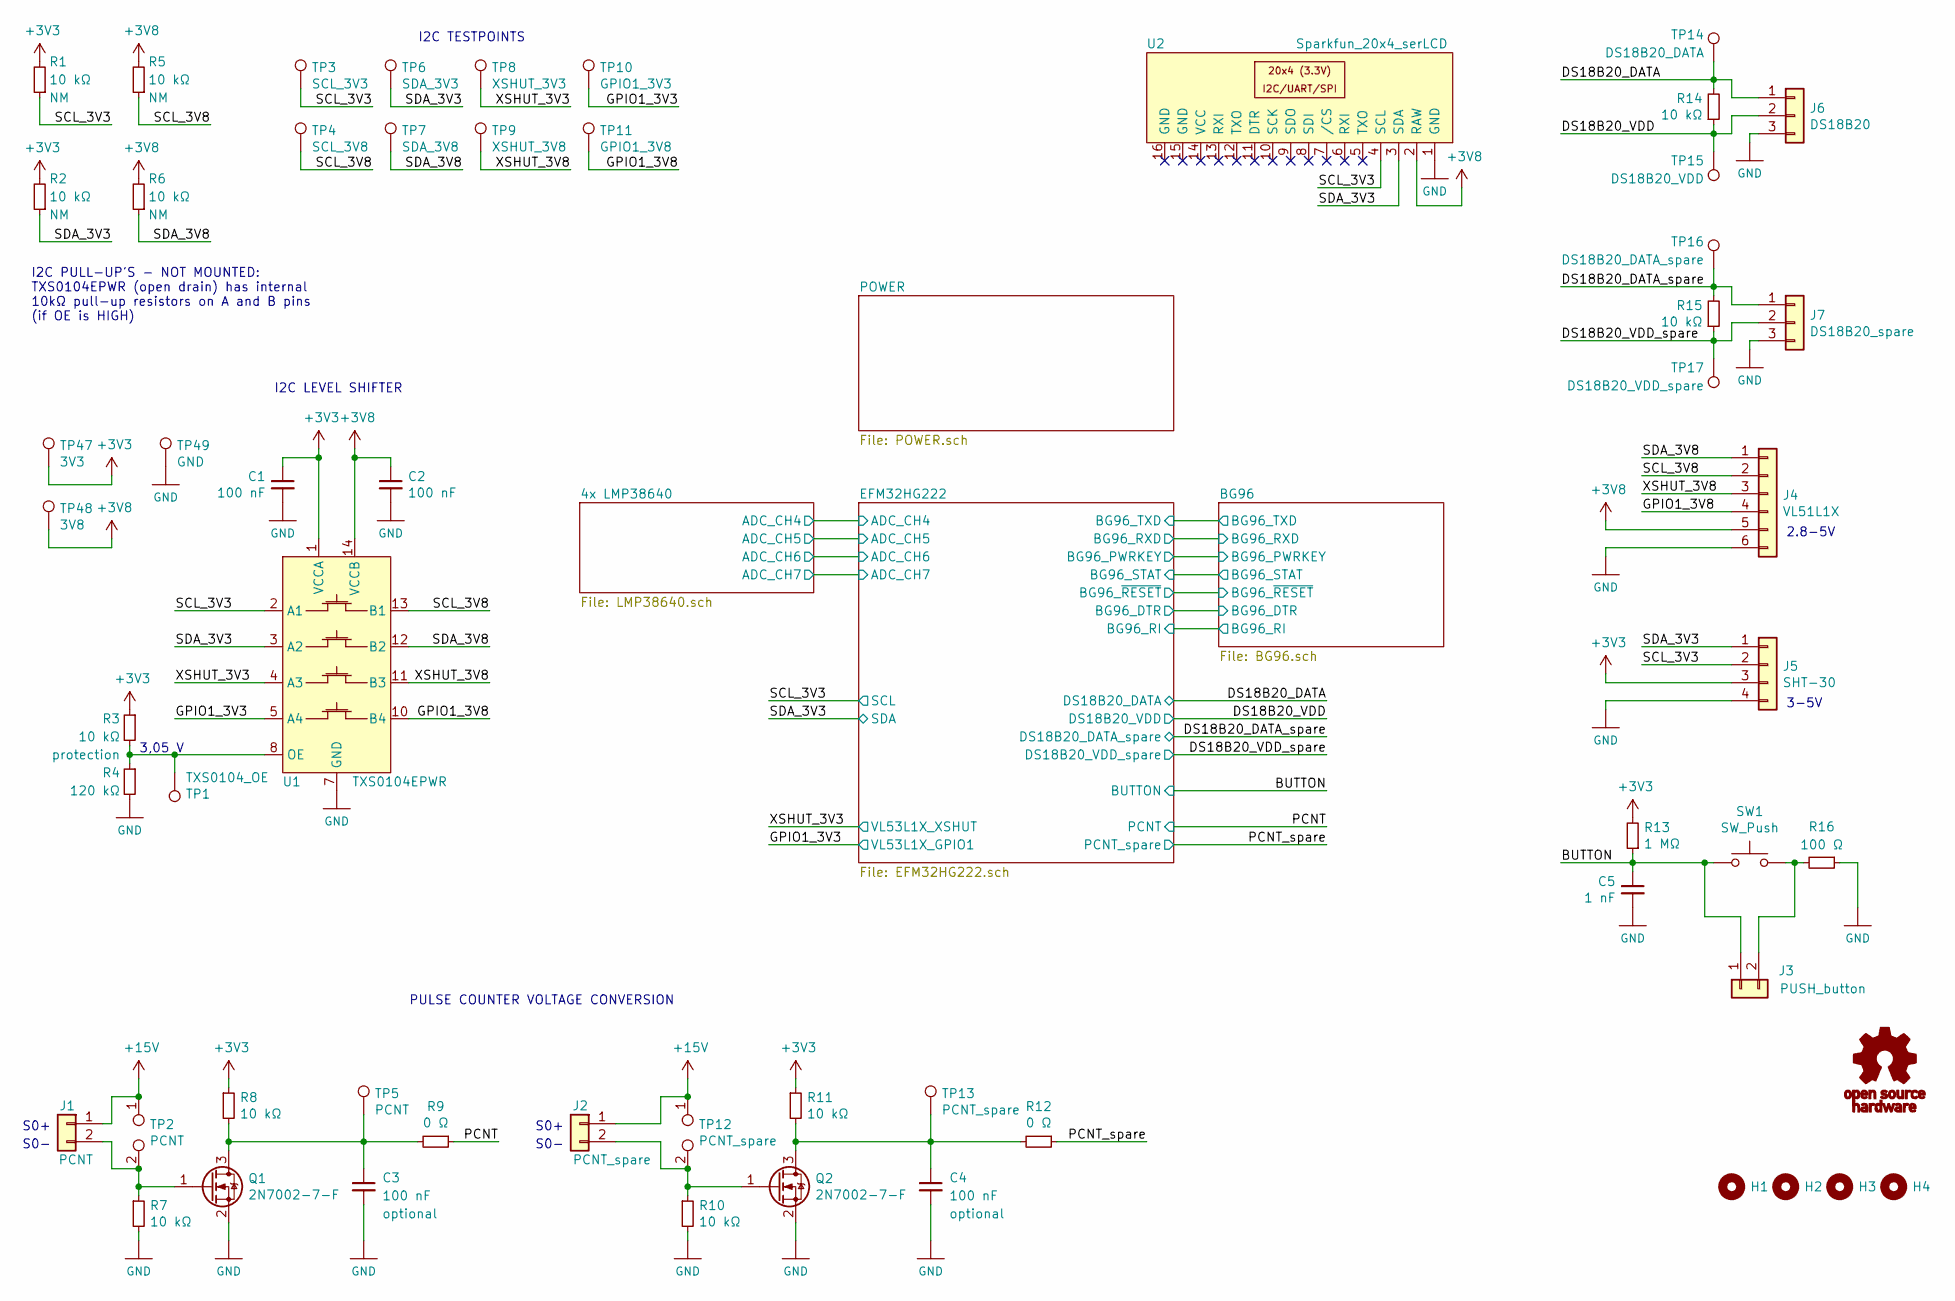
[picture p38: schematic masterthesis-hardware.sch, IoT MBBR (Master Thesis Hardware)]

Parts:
C1, C2, C3, C4: 100 nF; C_0805_2012Metric_Pad1.15x1.40mm_HandSolder
C5: 1 nF; C_0805_2012Metric_Pad1.15x1.40mm_HandSolder
G1: Symbol_OSHW-Logo_11.4x12mm; OSHW-Logo_5.7x6mm_SolderMask
H1, H2, H3, H4: MountingHole; MountingHole_3.2mm_M3
J1: PCNT; PhoenixContact_PTSA_1,5_2-G-3,5_1x02_P3.50mm_Angled
J2: PCNT_spare; PhoenixContact_PTSA_1,5_2-G-3,5_1x02_P3.50mm_Angled
J3: PUSH_button; JST_XH_B2B-XH-A_1x02_P2.50mm_Vertical
J4: VL51L1X; PhoenixContact_PTSA_1,5_6-G-3,5_1x06_P3.50mm_Angled
J5: SHT-30; PhoenixContact_PTSA_1,5_4-G-3,5_1x04_P3.50mm_Angled
J6: DS18B20; PhoenixContact_PTSA_1,5_3-G-3,5_1x03_P3.50mm_Angled
J7: DS18B20_spare; PhoenixContact_PTSA_1,5_3-G-3,5_1x03_P3.50mm_Angled
Q1, Q2: 2N7002-7-F; SOT-23_Handsoldering
R1, R2, R3, R5, R6, R7, R8, R10, R11, R14, R15: 10 kΩ; R_0805_2012Metric_Pad1.15x1.40mm_HandSolder
R4: 120 kΩ; R_0805_2012Metric_Pad1.15x1.40mm_HandSolder
R9, R12: 0 Ω; R_0805_2012Metric_Pad1.15x1.40mm_HandSolder
R13: 1 MΩ; R_0805_2012Metric_Pad1.15x1.40mm_HandSolder
R16: 100 Ω; R_0805_2012Metric_Pad1.15x1.40mm_HandSolder
SW1: SW_Push; SW_SPST_FSMSM
TP1: TXS0104_OE; PinHeader_1x01_P2.54mm_Vertical
TP2: PCNT; PinHeader_1x02_P2.54mm_Vertical
TP3: SCL_3V3; PinHeader_1x01_P2.54mm_Vertical
TP4: SCL_3V8; PinHeader_1x01_P2.54mm_Vertical
TP5: PCNT; PinHeader_1x01_P2.54mm_Vertical
TP6: SDA_3V3; PinHeader_1x01_P2.54mm_Vertical
TP7: SDA_3V8; PinHeader_1x01_P2.54mm_Vertical
TP8: XSHUT_3V3; PinHeader_1x01_P2.54mm_Vertical
TP9: XSHUT_3V8; PinHeader_1x01_P2.54mm_Vertical
TP10: GPIO1_3V3; PinHeader_1x01_P2.54mm_Vertical
TP11: GPIO1_3V8; PinHeader_1x01_P2.54mm_Vertical
TP12: PCNT_spare; PinHeader_1x02_P2.54mm_Vertical
TP13: PCNT_spare; PinHeader_1x01_P2.54mm_Vertical
TP14: DS18B20_DATA; PinHeader_1x01_P2.54mm_Vertical
TP15: DS18B20_VDD; PinHeader_1x01_P2.54mm_Vertical
TP16: DS18B20_DATA_spare; PinHeader_1x01_P2.54mm_Vertical
TP17: DS18B20_VDD_spare; PinHeader_1x01_P2.54mm_Vertical
TP47: 3V3; PinHeader_1x01_P2.54mm_Vertical
TP48: 3V8; PinHeader_1x01_P2.54mm_Vertical
TP49: GND; PinHeader_1x01_P2.54mm_Vertical
U1: TXS0104EPWR; TSSOP-14_4.4x5mm_P0.65mm
U2: Sparkfun_20x4_serLCD

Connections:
+3V3: C1.1, J5.3, R1.2, R2.2, R3.1, R8.1, R11.1, R13.2, TP47.1, U1.1 (VCCA); also elsewhere on the board
+3V8: C2.1, J4.5, R5.2, R6.2, TP48.1, U1.14 (VCCB), U2.2 (RAW); also elsewhere on the board
+15V: J1.1, J2.1, TP2.1, TP12.1; also elsewhere on the board
/BUTTON: C5.1, J3.1, R13.1, SW1.1; also elsewhere on the board
/DS18B20_DATA: J6.1, R14.2, TP14.1; also elsewhere on the board
/DS18B20_DATA_spare: J7.1, R15.2, TP16.1; also elsewhere on the board
/DS18B20_VDD: J6.2, R14.1, TP15.1; also elsewhere on the board
/DS18B20_VDD_spare: J7.2, R15.1, TP17.1; also elsewhere on the board
/GPIO1_3V3: TP10.1, U1.5 (A4); also elsewhere on the board
/GPIO1_3V8: J4.4, TP11.1, U1.10 (B4)
/PCNT: R9.1; also elsewhere on the board
/PCNT_spare: R12.1; also elsewhere on the board
/SCL_3V3: J5.2, R1.1, TP3.1, U1.2 (A1), U2.4 (SCL); also elsewhere on the board
/SCL_3V8: J4.2, R5.1, TP4.1, U1.13 (B1)
/SDA_3V3: J5.1, R2.1, TP6.1, U1.3 (A2), U2.3 (SDA); also elsewhere on the board
/SDA_3V8: J4.1, R6.1, TP7.1, U1.12 (B2)
/XSHUT_3V3: TP8.1, U1.4 (A3); also elsewhere on the board
/XSHUT_3V8: J4.3, TP9.1, U1.11 (B3)
GND: C1.2, C2.2, C3.2, C4.2, C5.2, J4.6, J5.4, J6.3, J7.3, Q1.2 (S), Q2.2 (S), R4.2, R7.2, R10.2, R16.1, TP49.1, U1.7 (GND), U2.1 (GND); also elsewhere on the board
unnamed: C3.1, Q1.3 (D), R8.2, R9.2, TP5.1
unnamed: C4.1, Q2.3 (D), R11.2, R12.2, TP13.1
unnamed: J1.2, Q1.1 (G), R7.1, TP2.2
unnamed: J2.2, Q2.1 (G), R10.1, TP12.2
unnamed: J3.2, R16.2, SW1.2
unnamed: R3.2, R4.1, TP1.1, U1.8 (OE)

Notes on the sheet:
3-5V
2.8-5V
I2C PULL-UP'S - NOT MOUNTED: TXS0104EPWR (open drain) has internal 10kΩ pull-up resistors on A and B pins (if OE is HIGH)
3,05 V
S0+
S0-
I2C TESTPOINTS
I2C LEVEL SHIFTER
PULSE COUNTER VOLTAGE CONVERSION

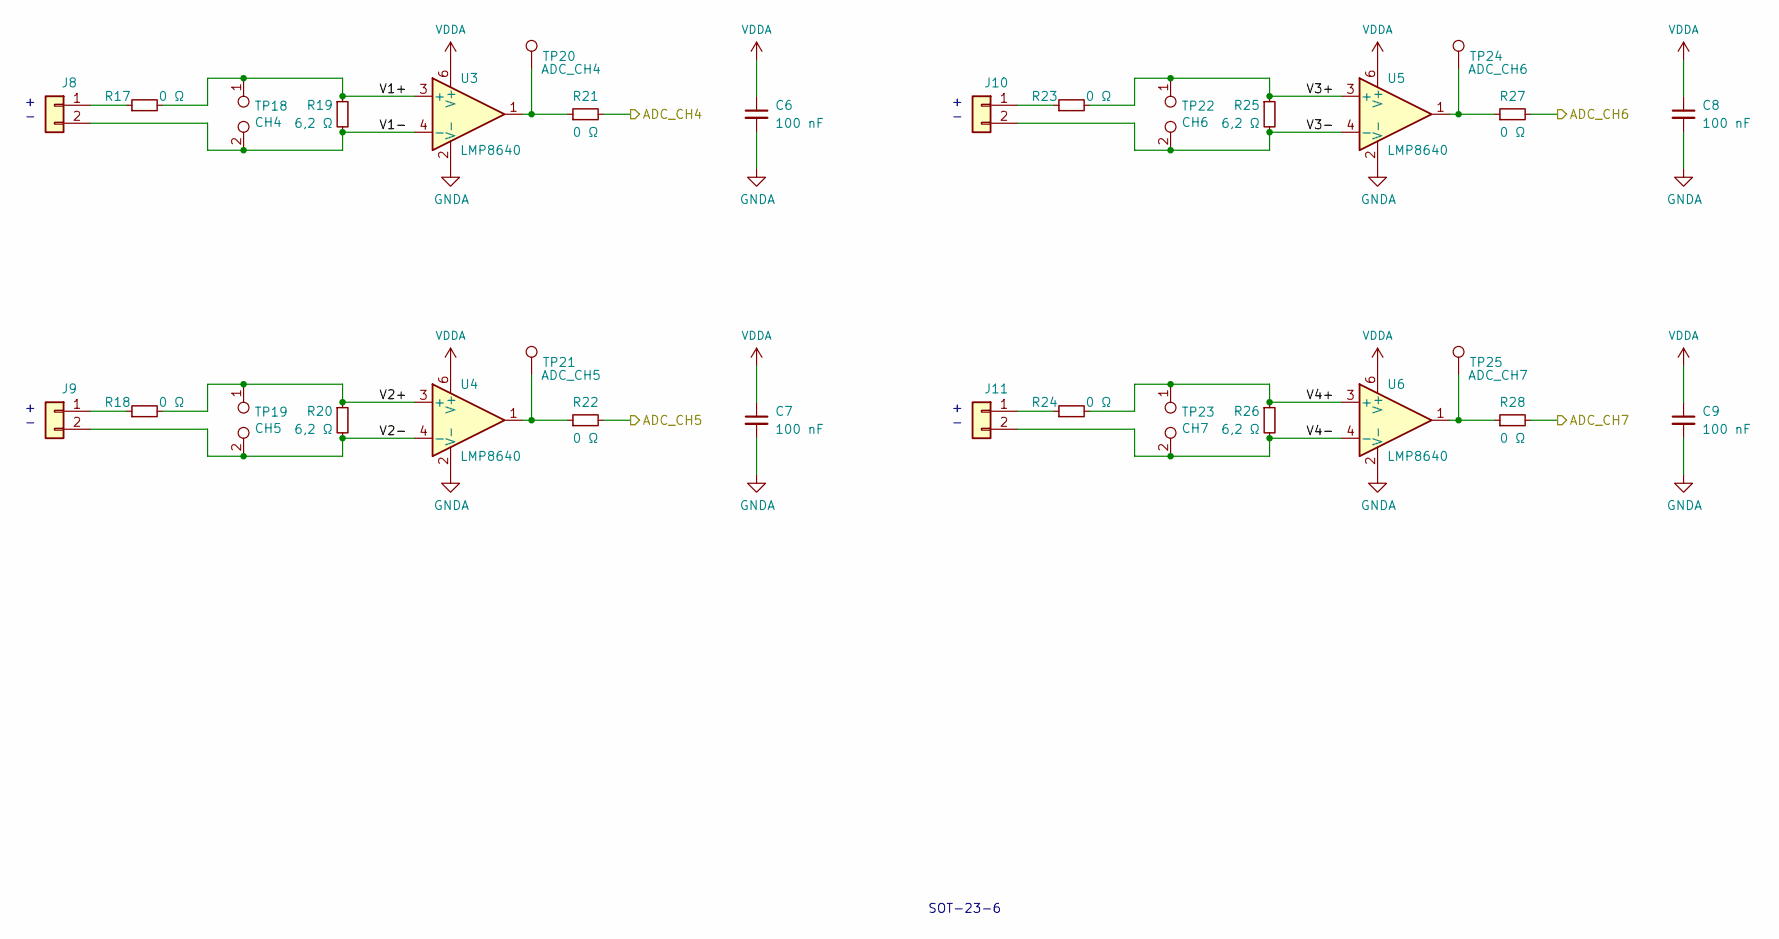
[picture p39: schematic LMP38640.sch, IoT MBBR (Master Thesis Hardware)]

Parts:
C6, C7, C8, C9: 100 nF; C_0805_2012Metric_Pad1.15x1.40mm_HandSolder
J8, J9, J10, J11: CH4; PhoenixContact_PTSA_1,5_2-G-3,5_1x02_P3.50mm_Angled
R17, R18, R21, R22, R23, R24, R27, R28: 0 Ω; R_0805_2012Metric_Pad1.15x1.40mm_HandSolder
R19, R20, R25, R26: 6,2 Ω; R_0805_2012Metric_Pad1.15x1.40mm_HandSolder
TP18: CH4; PinHeader_1x02_P2.54mm_Vertical
TP19: CH5; PinHeader_1x02_P2.54mm_Vertical
TP20: ADC_CH4; PinHeader_1x01_P2.54mm_Vertical
TP21: ADC_CH5; PinHeader_1x01_P2.54mm_Vertical
TP22: CH6; PinHeader_1x02_P2.54mm_Vertical
TP23: CH7; PinHeader_1x02_P2.54mm_Vertical
TP24: ADC_CH6; PinHeader_1x01_P2.54mm_Vertical
TP25: ADC_CH7; PinHeader_1x01_P2.54mm_Vertical
U3, U4, U5, U6: LMP8640; SOT-23-6_Handsoldering

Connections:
/4x LMP38640/ADC_CH4: R21.2; also elsewhere on the board
/4x LMP38640/ADC_CH5: R22.2; also elsewhere on the board
/4x LMP38640/ADC_CH6: R27.2; also elsewhere on the board
/4x LMP38640/ADC_CH7: R28.2; also elsewhere on the board
/4x LMP38640/V1+: R17.2, R19.1, TP18.1, U3.3 (+)
/4x LMP38640/V1-: J8.2, R19.2, TP18.2, U3.4 (-)
/4x LMP38640/V2+: R18.2, R20.1, TP19.1, U4.3 (+)
/4x LMP38640/V2-: J9.2, R20.2, TP19.2, U4.4 (-)
/4x LMP38640/V3+: R23.2, R25.1, TP22.1, U5.3 (+)
/4x LMP38640/V3-: J10.2, R25.2, TP22.2, U5.4 (-)
/4x LMP38640/V4+: R24.2, R26.1, TP23.1, U6.3 (+)
/4x LMP38640/V4-: J11.2, R26.2, TP23.2, U6.4 (-)
GNDA: C6.2, C7.2, C8.2, C9.2, U3.2 (V-), U4.2 (V-), U5.2 (V-), U6.2 (V-); also elsewhere on the board
unnamed: J8.1, R17.1
unnamed: J9.1, R18.1
unnamed: J10.1, R23.1
unnamed: J11.1, R24.1
unnamed: R21.1, TP20.1, U3.1
unnamed: R22.1, TP21.1, U4.1
unnamed: R27.1, TP24.1, U5.1
unnamed: R28.1, TP25.1, U6.1
VDDA: C6.1, C7.1, C8.1, C9.1, U3.6 (V+), U4.6 (V+), U5.6 (V+), U6.6 (V+); also elsewhere on the board

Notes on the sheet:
+ -
SOT-23-6

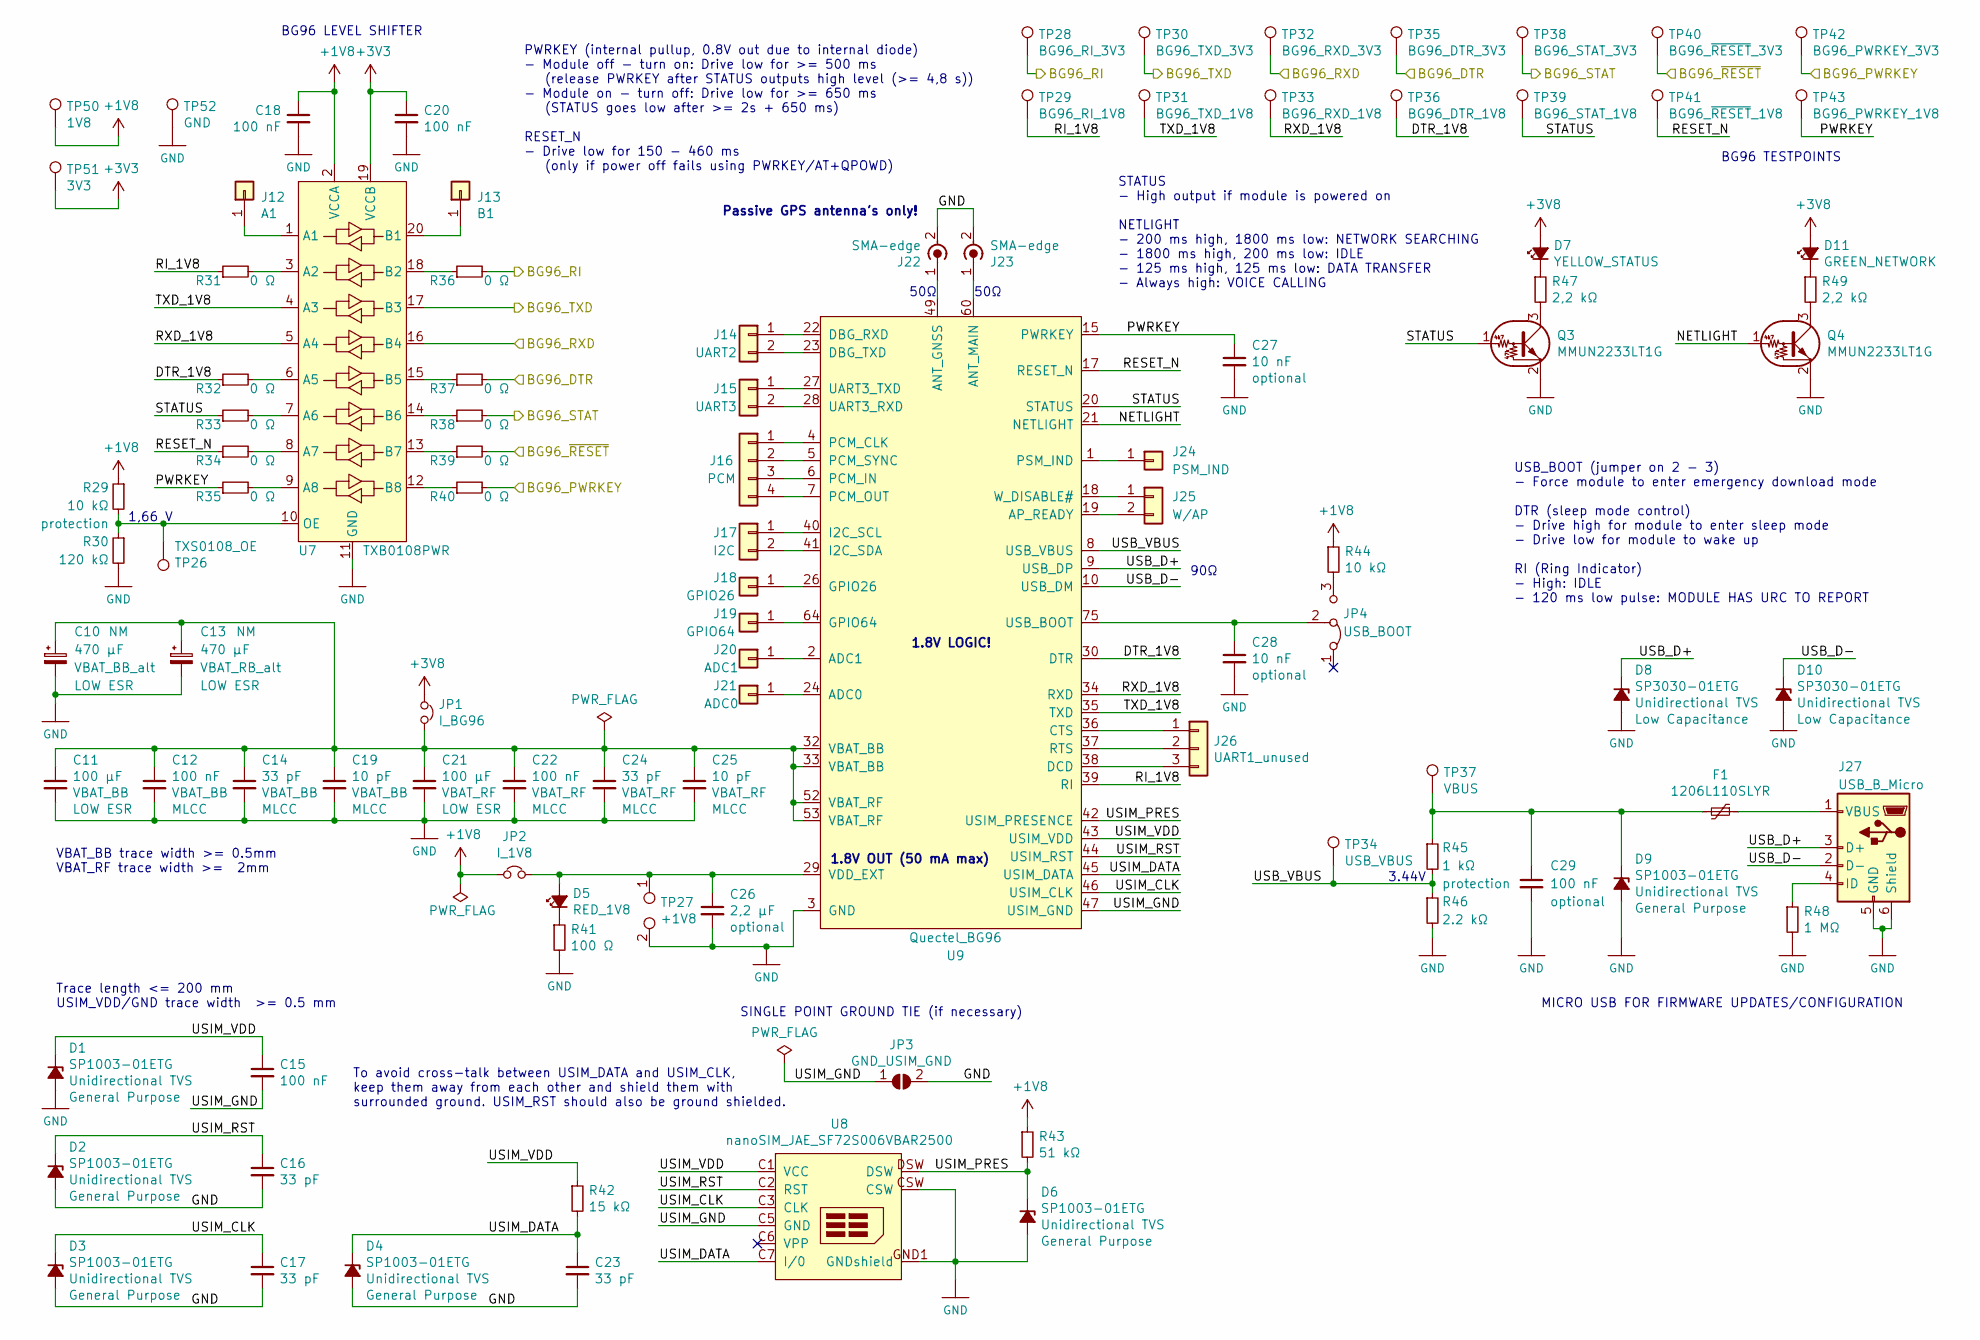
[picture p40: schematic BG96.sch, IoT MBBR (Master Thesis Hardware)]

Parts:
C10, C13: 470 µF; CP_EIA-7343-43_Kemet-X_Pad2.25x2.55mm_HandSolder
C11, C21: 100 µF; C_1206_3216Metric_Pad1.42x1.75mm_HandSolder
C12, C15, C18, C20, C22, C29: 100 nF; C_0805_2012Metric_Pad1.15x1.40mm_HandSolder
C14, C16, C17, C23, C24: 33 pF; C_0805_2012Metric_Pad1.15x1.40mm_HandSolder
C19, C25: 10 pF; C_0805_2012Metric_Pad1.15x1.40mm_HandSolder
C26: 2,2 µF; C_0805_2012Metric_Pad1.15x1.40mm_HandSolder
C27, C28: 10 nF; C_0805_2012Metric_Pad1.15x1.40mm_HandSolder
D1, D2, D3, D4, D6, D9: SP1003-01ETG; D_0402_1005Metric
D5: RED_1V8; LED_0805_2012Metric_Pad1.15x1.40mm_HandSolder
D7: YELLOW_STATUS; LED_0805_2012Metric_Pad1.15x1.40mm_HandSolder
D8, D10: SP3030-01ETG; D_0402_1005Metric
D11: GREEN_NETWORK; LED_0805_2012Metric_Pad1.15x1.40mm_HandSolder
F1: 1206L110SLYR; Fuse_1206_3216Metric_Pad1.42x1.75mm_HandSolder
J12: A1; PinHeader_1x01_P2.54mm_Vertical
J13: B1; PinHeader_1x01_P2.54mm_Vertical
J14: UART2; PinHeader_1x02_P2.54mm_Vertical_SMD_Pin1Left
J15: UART3; PinHeader_1x02_P2.54mm_Vertical_SMD_Pin1Left
J16: PCM; PinHeader_1x04_P2.54mm_Vertical_SMD_Pin1Left
J17: I2C; PinHeader_1x02_P2.54mm_Vertical_SMD_Pin1Left
J18: GPIO26; PinHeader_1x01_P2.54mm_Vertical
J19: GPIO64; PinHeader_1x01_P2.54mm_Vertical
J20: ADC1; PinHeader_1x01_P2.54mm_Vertical
J21: ADC0; PinHeader_1x01_P2.54mm_Vertical
J22, J23: SMA-edge; SMA_Samtec_SMA-J-P-X-ST-EM1_EdgeMount
J24: PSM_IND; PinHeader_1x01_P2.54mm_Vertical
J25: W/AP; PinHeader_1x02_P2.54mm_Vertical_SMD_Pin1Left
J26: UART1_unused; PinHeader_1x03_P2.54mm_Vertical_SMD_Pin1Left
J27: USB_B_Micro; USB_Micro-B_Molex_47346-0001
JP1: I_BG96; PinHeader_1x02_P2.54mm_Vertical
JP2: I_1V8; PinHeader_1x02_P2.54mm_Vertical
JP3: GND_USIM_GND; SolderJumper-2_P1.3mm_Open_TrianglePad1.0x1.5mm
JP4: USB_BOOT; PinHeader_1x03_P2.54mm_Vertical
Q3, Q4: MMUN2233LT1G; SOT-23_Handsoldering
R29, R44: 10 kΩ; R_0805_2012Metric_Pad1.15x1.40mm_HandSolder
R30: 120 kΩ; R_0805_2012Metric_Pad1.15x1.40mm_HandSolder
R31, R32, R33, R34, R35, R36, R37, R38, R39, R40: 0 Ω; R_0805_2012Metric_Pad1.15x1.40mm_HandSolder
R41: 100 Ω; R_0805_2012Metric_Pad1.15x1.40mm_HandSolder
R42: 15 kΩ; R_0805_2012Metric_Pad1.15x1.40mm_HandSolder
R43: 51 kΩ; R_0805_2012Metric_Pad1.15x1.40mm_HandSolder
R45: 1 kΩ; R_0805_2012Metric_Pad1.15x1.40mm_HandSolder
R46: 2.2 kΩ; R_0805_2012Metric_Pad1.15x1.40mm_HandSolder
R47, R49: 2,2 kΩ; R_0805_2012Metric_Pad1.15x1.40mm_HandSolder
R48: 1 MΩ; R_0805_2012Metric_Pad1.15x1.40mm_HandSolder
TP26: TXS0108_OE; PinHeader_1x01_P2.54mm_Vertical
TP27: +1V8; PinHeader_1x02_P2.54mm_Vertical
TP28: BG96_RI_3V3; PinHeader_1x01_P2.54mm_Vertical
TP29: BG96_RI_1V8; PinHeader_1x01_P2.54mm_Vertical
TP30: BG96_TXD_3V3; PinHeader_1x01_P2.54mm_Vertical
TP31: BG96_TXD_1V8; PinHeader_1x01_P2.54mm_Vertical
TP32: BG96_RXD_3V3; PinHeader_1x01_P2.54mm_Vertical
TP33: BG96_RXD_1V8; PinHeader_1x01_P2.54mm_Vertical
TP34: USB_VBUS; PinHeader_1x01_P2.54mm_Vertical
TP35: BG96_DTR_3V3; PinHeader_1x01_P2.54mm_Vertical
TP36: BG96_DTR_1V8; PinHeader_1x01_P2.54mm_Vertical
TP37: VBUS; PinHeader_1x01_P2.54mm_Vertical
TP38: BG96_STAT_3V3; PinHeader_1x01_P2.54mm_Vertical
TP39: BG96_STAT_1V8; PinHeader_1x01_P2.54mm_Vertical
TP40: BG96_~RESET~_3V3; PinHeader_1x01_P2.54mm_Vertical
TP41: BG96_~RESET~_1V8; PinHeader_1x01_P2.54mm_Vertical
TP42: BG96_PWRKEY_3V3; PinHeader_1x01_P2.54mm_Vertical
TP43: BG96_PWRKEY_1V8; PinHeader_1x01_P2.54mm_Vertical
TP50: 1V8; PinHeader_1x01_P2.54mm_Vertical
TP51: 3V3; PinHeader_1x01_P2.54mm_Vertical
TP52: GND; PinHeader_1x01_P2.54mm_Vertical
U7: TXB0108PWR; TSSOP-20_4.4x6.5mm_P0.65mm
U8: nanoSIM_JAE_SF72S006VBAR2500
U9: Quectel_BG96; Quectel_BG96_LGA102

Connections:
+1V8: C18.1, JP2.1, R29.1, R43.1, R44.1, TP50.1, U7.2 (VCCA)
+3V3: C20.1, TP51.1, U7.19 (VCCB); also elsewhere on the board
+3V8: D7.2 (A), D11.2 (A), JP1.1; also elsewhere on the board
/BG96/BG96_DTR: R37.2, TP35.1; also elsewhere on the board
/BG96/BG96_PWRKEY: R40.2, TP42.1; also elsewhere on the board
/BG96/BG96_RI: R36.2, TP28.1; also elsewhere on the board
/BG96/BG96_RXD: TP32.1, U7.16 (B4); also elsewhere on the board
/BG96/BG96_STAT: R38.2, TP38.1; also elsewhere on the board
/BG96/BG96_TXD: TP30.1, U7.17 (B3); also elsewhere on the board
/BG96/BG96_~RESET: R39.2, TP40.1; also elsewhere on the board
/BG96/DTR_1V8: R32.1, TP36.1, U9.30 (DTR)
/BG96/NETLIGHT: Q4.1 (B), U9.21 (NETLIGHT)
/BG96/PWRKEY: C27.1, R35.1, TP43.1, U9.15 (PWRKEY)
/BG96/RESET_N: R34.1, TP41.1, U9.17 (RESET_N)
/BG96/RI_1V8: R31.1, TP29.1, U9.39 (RI)
/BG96/RXD_1V8: TP33.1, U7.5 (A4), U9.34 (RXD)
/BG96/STATUS: Q3.1 (B), R33.1, TP39.1, U9.20 (STATUS)
/BG96/TXD_1V8: TP31.1, U7.4 (A3), U9.35 (TXD)
/BG96/USB_D+: D8.1 (K), J27.3 (D+), U9.9 (USB_DP)
/BG96/USB_D-: D10.1 (K), J27.2 (D-), U9.10 (USB_DM)
/BG96/USB_VBUS: R45.2, R46.1, TP34.1, U9.8 (USB_VBUS)
/BG96/USIM_CLK: C17.1, D3.1 (K), U8.C3 (CLK), U9.46 (USIM_CLK)
/BG96/USIM_DATA: C23.1, D4.1 (K), R42.2, U8.C7 (I/0), U9.45 (USIM_DATA)
/BG96/USIM_GND: C15.2, JP3.1 (A), U8.C5 (GND), U9.47 (USIM_GND)
/BG96/USIM_PRES: D6.1 (K), R43.2, U8.DSW, U9.42 (USIM_PRESENCE)
/BG96/USIM_RST: C16.1, D2.1 (K), U8.C2 (RST), U9.44 (USIM_RST)
/BG96/USIM_VDD: C15.1, D1.1 (K), R42.1, U8.C1 (VCC), U9.43 (USIM_VDD)
GND: C10.2, C11.2, C12.2, C13.2, C14.2, C16.2, C17.2, C18.2, C19.2, C20.2, C21.2, C22.2, C23.2, C24.2, C25.2, C26.2, C27.2, C28.2, C29.2, D1.2 (A), D2.2 (A), D3.2 (A), D4.2 (A), D6.2 (A), D8.2 (A), D9.2 (A), D10.2 (A), J22.2 (Ext), J23.2 (Ext), J27.5 (GND), J27.6 (Shield), JP3.2 (B), Q3.2 (E), Q4.2 (E), R30.2, R41.2, R46.2, R48.2, TP27.2, TP52.1, U7.11 (GND), U8.CSW, U8.GND1 (GNDshield), U8.GND2, U8.GND3, U8.GND4, U8.GND5, U8.GND6, U8.GND7, U8.GND8, U8.GND9, U8.GND10, U9.3 (GND), U9.31 (GND), U9.48 (GND), U9.50 (GND), U9.54 (GND), U9.55 (GND), U9.58 (GND), U9.59 (GND), U9.61 (GND), U9.62 (GND), U9.67 (GND), U9.68 (GND), U9.69 (GND), U9.70 (GND), U9.71 (GND), U9.72 (GND), U9.73 (GND), U9.74 (GND), U9.79 (GND), U9.80 (GND), U9.81 (GND), U9.82 (GND), U9.89 (GND), U9.90 (GND), U9.91 (GND), U9.100 (GND), U9.101 (GND), U9.102 (GND); also elsewhere on the board
unnamed: C10.1, C11.1, C12.1, C13.1, C14.1, C19.1, C21.1, C22.1, C24.1, C25.1, JP1.2, U9.32 (VBAT_BB), U9.33 (VBAT_BB), U9.52 (VBAT_RF), U9.53 (VBAT_RF)
unnamed: C26.1, D5.2 (A), JP2.2, TP27.1, U9.29 (VDD_EXT)
unnamed: C28.1, JP4.2 (C), U9.75 (USB_BOOT)
unnamed: C29.1, D9.1 (K), F1.2, R45.1, TP37.1
unnamed: D5.1 (K), R41.1
unnamed: D7.1 (K), R47.1
unnamed: D11.1 (K), R49.1
unnamed: F1.1, J27.1 (VBUS)
unnamed: J12.1, U7.1 (A1)
unnamed: J13.1, U7.20 (B1)
unnamed: J14.1, U9.22 (DBG_RXD)
unnamed: J14.2, U9.23 (DBG_TXD)
unnamed: J15.1, U9.27 (UART3_TXD)
unnamed: J15.2, U9.28 (UART3_RXD)
unnamed: J16.1, U9.4 (PCM_CLK)
unnamed: J16.2, U9.5 (PCM_SYNC)
unnamed: J16.3, U9.6 (PCM_IN)
unnamed: J16.4, U9.7 (PCM_OUT)
unnamed: J17.1, U9.40 (I2C_SCL)
unnamed: J17.2, U9.41 (I2C_SDA)
unnamed: J18.1, U9.26 (GPIO26)
unnamed: J19.1, U9.64 (GPIO64)
unnamed: J20.1, U9.2 (ADC1)
unnamed: J21.1, U9.24 (ADC0)
unnamed: J22.1 (In), U9.49 (ANT_GNSS)
unnamed: J23.1 (In), U9.60 (ANT_MAIN)
unnamed: J24.1, U9.1 (PSM_IND)
unnamed: J25.1, U9.18 (W_DISABLE#)
unnamed: J25.2, U9.19 (AP_READY)
unnamed: J26.1, U9.36 (CTS)
unnamed: J26.2, U9.37 (RTS)
unnamed: J26.3, U9.38 (DCD)
unnamed: J27.4 (ID), R48.1
unnamed: JP4.3 (B), R44.2
unnamed: Q3.3 (C), R47.2
unnamed: Q4.3 (C), R49.2
unnamed: R29.2, R30.1, TP26.1, U7.10 (OE)
unnamed: R31.2, U7.3 (A2)
unnamed: R32.2, U7.6 (A5)
unnamed: R33.2, U7.7 (A6)
unnamed: R34.2, U7.8 (A7)
unnamed: R35.2, U7.9 (A8)
unnamed: R36.1, U7.18 (B2)
unnamed: R37.1, U7.15 (B5)
unnamed: R38.1, U7.14 (B6)
unnamed: R39.1, U7.13 (B7)
unnamed: R40.1, U7.12 (B8)

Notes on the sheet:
1.8V OUT (50 mA max)
VBAT_BB trace width >= 0.5mm VBAT_RF trace width >= 2mm
Trace length <= 200 mm USIM_VDD/GND trace width >= 0.5 mm
To avoid cross-talk between USIM_DATA and USIM_CLK, keep them away from each other and shield them with surrounded ground. USIM_RST should also be ground shielded.
Passive GPS antenna's only!
50Ω
90Ω
SINGLE POINT GROUND TIE (if necessary)
1,66 V
BG96 TESTPOINTS
MICRO USB FOR FIRMWARE UPDATES/CONFIGURATION
BG96 LEVEL SHIFTER
3.44V
1.8V LOGIC!
STATUS - High output if module is powered on NETLIGHT - 200 ms high, 1800 ms low: NETWORK SEARCHING - 1800 ms high, 200 ms low: IDLE - 125 ms high, 125 ms low: DATA TRANSFER - Always high: VOICE CALLING
PWRKEY (internal pullup, 0.8V out due to internal diode) - Module off - turn on: Drive low for >= 500 ms (release PWRKEY after STATUS outputs high level (>= 4,8 s)) - Module on - turn off: Drive low for >= 650 ms (STATUS goes low after >= 2s + 650 ms) RESET_N - Drive low for 150 - 460 ms (only if p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
USB_BOOT (jumper on 2 - 3) - Force module to enter emergency download mode DTR (sleep mode control) - Drive high for module to enter sleep mode - Drive low for module to wake up RI (Ring Indicator) - High: IDLE - 120 ms low pulse: MODULE HAS URC TO REPORT

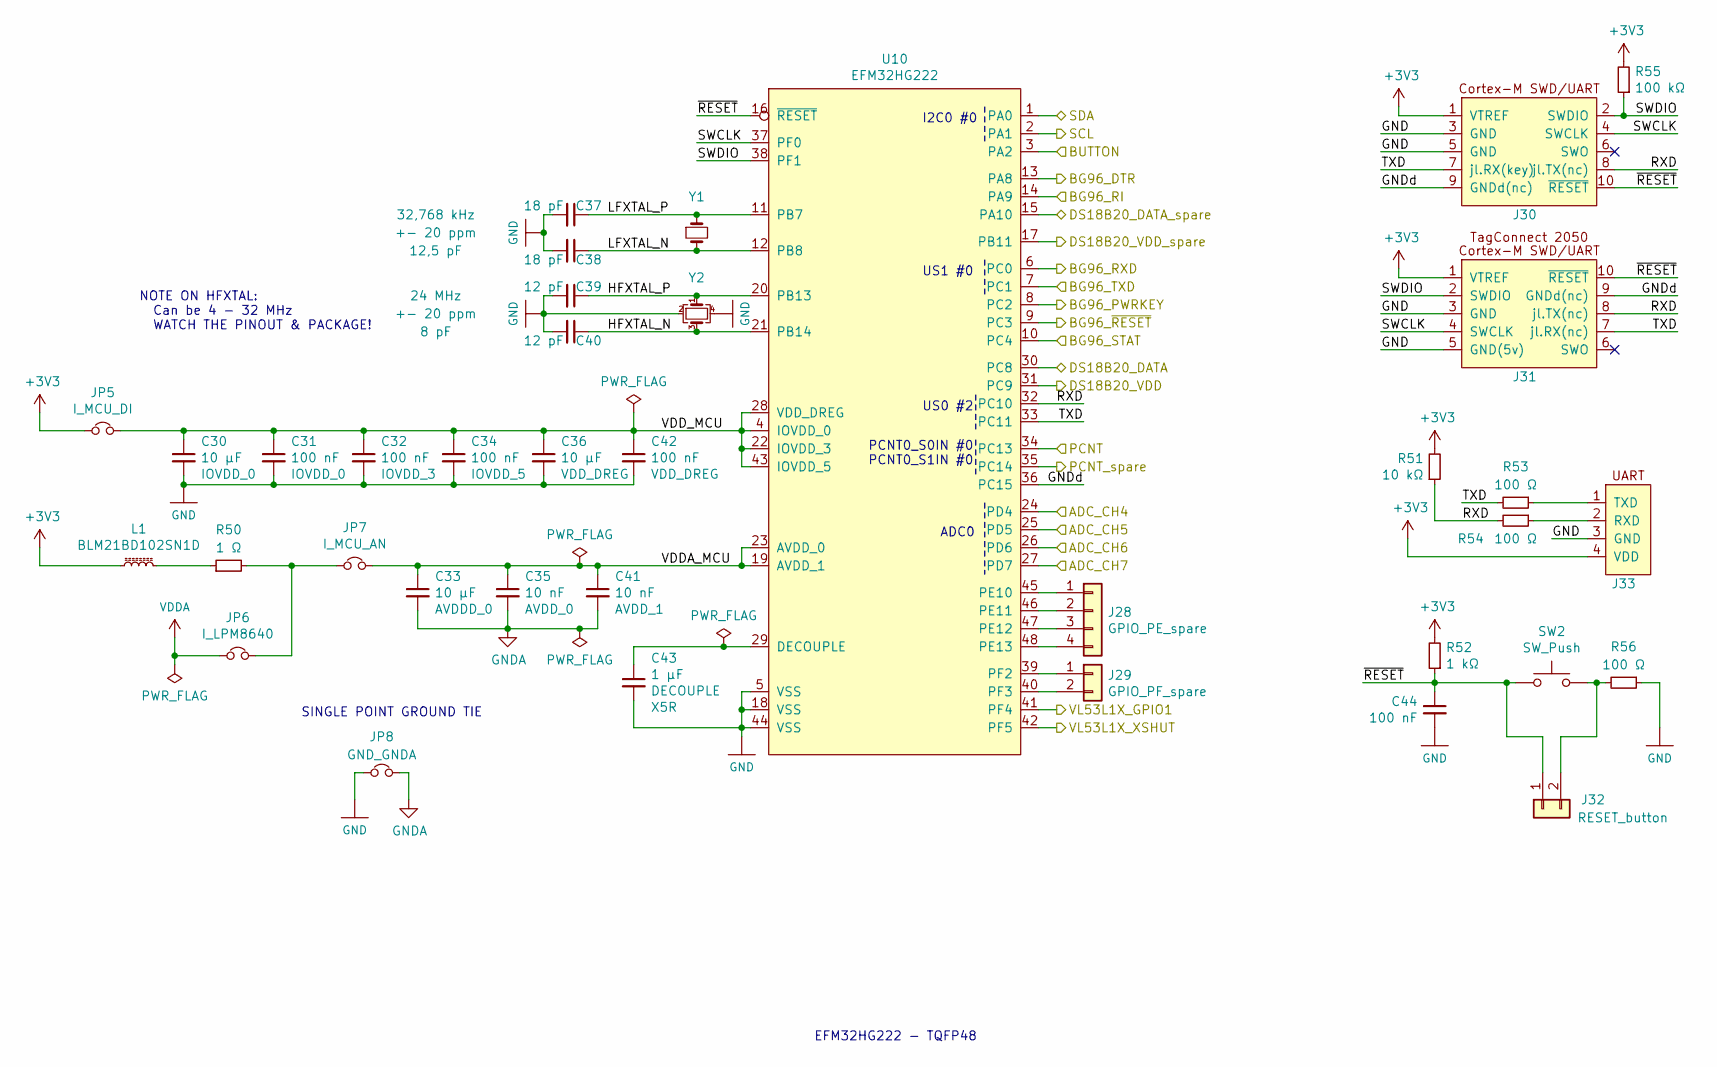
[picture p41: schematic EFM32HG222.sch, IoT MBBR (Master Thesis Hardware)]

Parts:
C30, C33, C36: 10 µF; C_0805_2012Metric_Pad1.15x1.40mm_HandSolder
C31, C32, C34, C42, C44: 100 nF; C_0805_2012Metric_Pad1.15x1.40mm_HandSolder
C35, C41: 10 nF; C_0805_2012Metric_Pad1.15x1.40mm_HandSolder
C37, C38: 18 pF; C_0805_2012Metric_Pad1.15x1.40mm_HandSolder
C39, C40: 12 pF; C_0805_2012Metric_Pad1.15x1.40mm_HandSolder
C43: 1 µF; C_0805_2012Metric_Pad1.15x1.40mm_HandSolder
J28: GPIO_PE_spare; PinHeader_1x04_P2.54mm_Vertical_SMD_Pin1Left
J29: GPIO_PF_spare; PinHeader_1x02_P2.54mm_Vertical_SMD_Pin1Left
J30: DebugHeader_Cortex-M_SWD_UART_10p; PinHeader_2x05_P1.27mm_Vertical_SMD
J31: DebugHeader_Cortex-M_JTAG_10p_TagConnect; Tag-Connect_TC2050-IDC-NL_2x05_P1.27mm_Vertical
J32: RESET_button; JST_XH_B2B-XH-A_1x02_P2.50mm_Vertical
J33: DebugHeader_UART_4p; PinHeader_1x04_P2.54mm_Vertical
JP5: I_MCU_DI; PinHeader_1x02_P2.54mm_Vertical
JP6: I_LPM8640; PinHeader_1x02_P2.54mm_Vertical
JP7: I_MCU_AN; PinHeader_1x02_P2.54mm_Vertical
JP8: GND_GNDA; PinHeader_1x02_P2.54mm_Vertical
L1: BLM21BD102SN1D; L_0805_2012Metric_Pad1.15x1.40mm_HandSolder
R50: 1 Ω; R_0805_2012Metric_Pad1.15x1.40mm_HandSolder
R51: 10 kΩ; R_0805_2012Metric_Pad1.15x1.40mm_HandSolder
R52: 1 kΩ; R_0805_2012Metric_Pad1.15x1.40mm_HandSolder
R53, R54, R56: 100 Ω; R_0805_2012Metric_Pad1.15x1.40mm_HandSolder
R55: 100 kΩ; R_0805_2012Metric_Pad1.15x1.40mm_HandSolder
SW2: SW_Push; SW_SPST_FSMSM
U10: EFM32HG222; TQFP-48_7x7mm_P0.5mm
Y1: 32,768 kHz; Crystal_SMD_2012-2Pin_2.0x1.2mm_HandSoldering; Tolerance +- 20 ppm
Y2: 24 MHz; Crystal_SMD_5032-4Pin_5.0x3.2mm; Tolerance +- 20 ppm

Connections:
+3V3: J30.1 (VTREF), J31.1 (VTREF), J33.4 (VDD), JP5.1, L1.1, R51.2, R52.2, R55.2; also elsewhere on the board
/4x LMP38640/ADC_CH4: U10.24 (PD4); also elsewhere on the board
/4x LMP38640/ADC_CH5: U10.25 (PD5); also elsewhere on the board
/4x LMP38640/ADC_CH6: U10.26 (PD6); also elsewhere on the board
/4x LMP38640/ADC_CH7: U10.27 (PD7); also elsewhere on the board
/BG96/BG96_DTR: U10.13 (PA8); also elsewhere on the board
/BG96/BG96_PWRKEY: U10.8 (PC2); also elsewhere on the board
/BG96/BG96_RI: U10.14 (PA9); also elsewhere on the board
/BG96/BG96_RXD: U10.6 (PC0); also elsewhere on the board
/BG96/BG96_STAT: U10.10 (PC4); also elsewhere on the board
/BG96/BG96_TXD: U10.7 (PC1); also elsewhere on the board
/BG96/BG96_~RESET: U10.9 (PC3); also elsewhere on the board
/BUTTON: U10.3 (PA2); also elsewhere on the board
/DS18B20_DATA: U10.30 (PC8); also elsewhere on the board
/DS18B20_DATA_spare: U10.15 (PA10); also elsewhere on the board
/DS18B20_VDD: U10.31 (PC9); also elsewhere on the board
/DS18B20_VDD_spare: U10.17 (PB11); also elsewhere on the board
/EFM32HG222/GNDd: J30.9 (GNDd(nc)), J31.9 (GNDd(nc)), U10.36 (PC15)
/EFM32HG222/HFXTAL_N: C40.1, U10.21 (PB14), Y2.3
/EFM32HG222/HFXTAL_P: C39.1, U10.20 (PB13), Y2.1
/EFM32HG222/LFXTAL_N: C38.1, U10.12 (PB8), Y1.2
/EFM32HG222/LFXTAL_P: C37.1, U10.11 (PB7), Y1.1
/EFM32HG222/RXD: J30.8 (jl.TX(nc)), J31.8 (jl.TX(nc)), R51.1, R54.2, U10.32 (PC10)
/EFM32HG222/SWCLK: J30.4 (SWCLK), J31.4 (SWCLK), U10.37 (PF0)
/EFM32HG222/SWDIO: J30.2 (SWDIO), J31.2 (SWDIO), R55.1, U10.38 (PF1)
/EFM32HG222/TXD: J30.7 (jl.RX(key)), J31.7 (jl.RX(nc)), R53.2, U10.33 (PC11)
/EFM32HG222/VDDA_MCU: C33.1, C35.1, C41.1, JP7.2, U10.19 (AVDD_1), U10.23 (AVDD_0)
/EFM32HG222/VDD_MCU: C30.1, C31.1, C32.1, C34.1, C36.1, C42.1, JP5.2, U10.4 (IOVDD_0), U10.22 (IOVDD_3), U10.28 (VDD_DREG), U10.43 (IOVDD_5)
/EFM32HG222/~RESET: C44.1, J30.10 (~RESET), J31.10 (~RESET), J32.1, R52.1, SW2.1, U10.16 (~RESET)
/GPIO1_3V3: U10.41 (PF4); also elsewhere on the board
/PCNT: U10.34 (PC13); also elsewhere on the board
/PCNT_spare: U10.35 (PC14); also elsewhere on the board
/SCL_3V3: U10.2 (PA1); also elsewhere on the board
/SDA_3V3: U10.1 (PA0); also elsewhere on the board
/XSHUT_3V3: U10.42 (PF5); also elsewhere on the board
GND: C30.2, C31.2, C32.2, C34.2, C36.2, C37.2, C38.2, C39.2, C40.2, C42.2, C43.2, C44.2, J30.3 (GND), J30.5 (GND), J31.3 (GND), J31.5 (GND(5v)), J33.3 (GND), JP8.1, R56.1, U10.5 (VSS), U10.18 (VSS), U10.44 (VSS), Y2.2, Y2.4; also elsewhere on the board
GNDA: C33.2, C35.2, C41.2, JP8.2; also elsewhere on the board
unnamed: C43.1, U10.29 (DECOUPLE)
unnamed: J28.1, U10.45 (PE10)
unnamed: J28.2, U10.46 (PE11)
unnamed: J28.3, U10.47 (PE12)
unnamed: J28.4, U10.48 (PE13)
unnamed: J29.1, U10.39 (PF2)
unnamed: J29.2, U10.40 (PF3)
unnamed: J32.2, R56.2, SW2.2
unnamed: J33.1 (TXD), R53.1
unnamed: J33.2 (RXD), R54.1
unnamed: JP6.2, JP7.1, R50.2
unnamed: L1.2, R50.1
VDDA: JP6.1; also elsewhere on the board

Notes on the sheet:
NOTE ON HFXTAL: Can be 4 - 32 MHz WATCH THE PINOUT & PACKAGE!
I2C0 #0
US1 #0
ADC0
US0 #2
PCNT0_S0IN #0 PCNT0_S1IN #0
SINGLE POINT GROUND TIE
EFM32HG222 - TQFP48

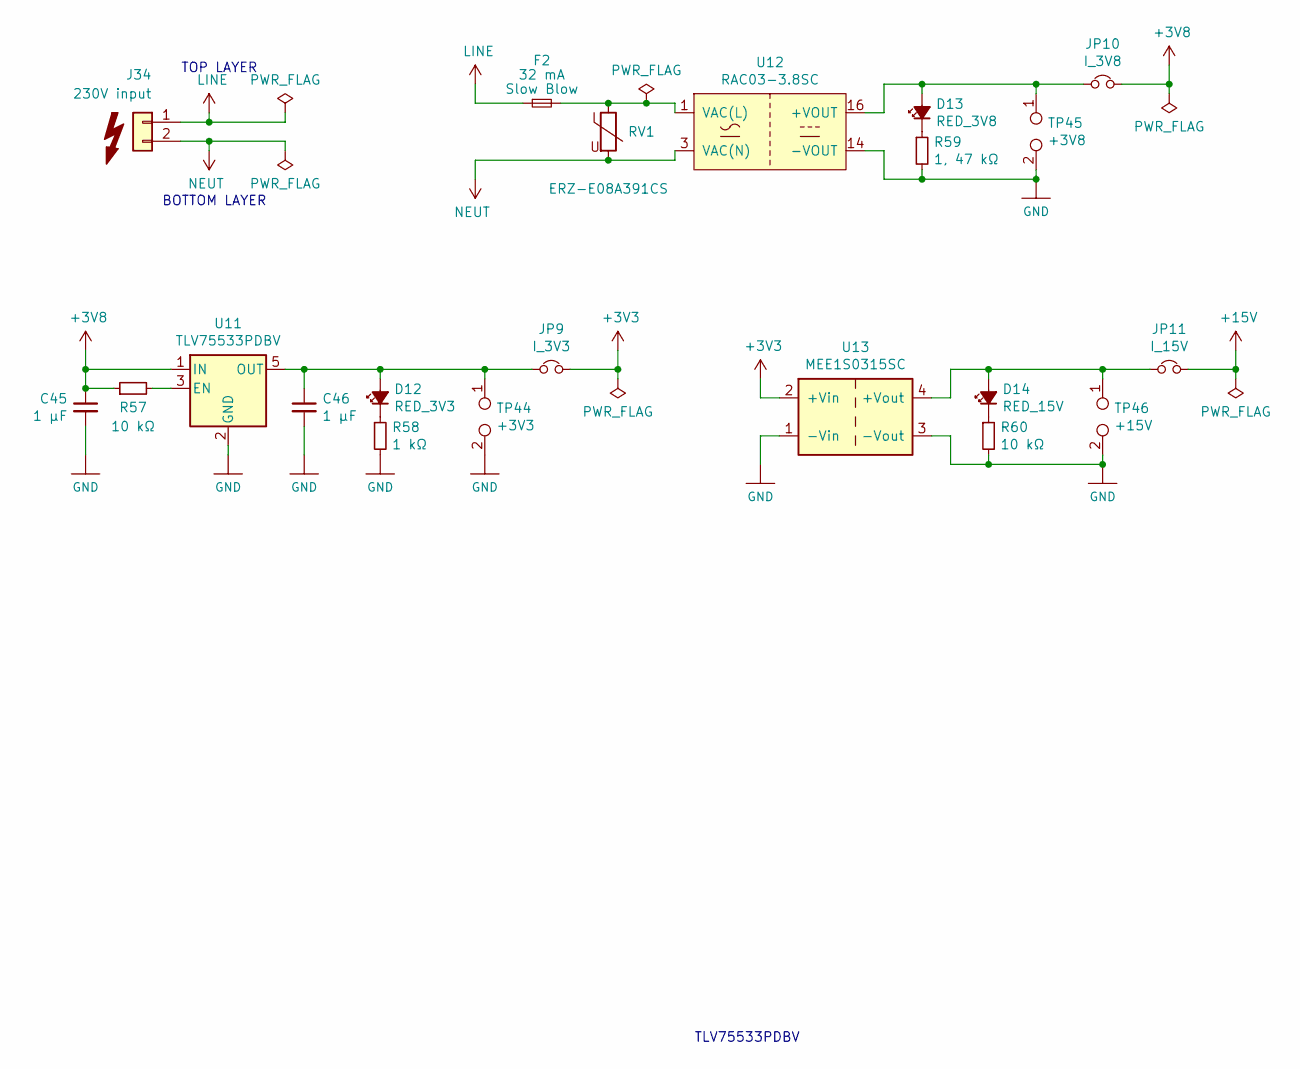
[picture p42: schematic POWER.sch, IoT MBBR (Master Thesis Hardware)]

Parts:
C45, C46: 1 µF; C_0805_2012Metric_Pad1.15x1.40mm_HandSolder
D12: RED_3V3; LED_0805_2012Metric_Pad1.15x1.40mm_HandSolder
D13: RED_3V8; LED_0805_2012Metric_Pad1.15x1.40mm_HandSolder
D14: RED_15V; LED_0805_2012Metric_Pad1.15x1.40mm_HandSolder
F2: 32 mA; Fuseholder_Cylinder-5x20mm_Stelvio-Kontek_PTF78_Horizontal_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
J34: 230V input; PhoenixContact_PTSA_1,5_2-G-3,5_1x02_P3.50mm_Angled
JP9: I_3V3; PinHeader_1x02_P2.54mm_Vertical
JP10: I_3V8; PinHeader_1x02_P2.54mm_Vertical
JP11: I_15V; PinHeader_1x02_P2.54mm_Vertical
R57, R60: 10 kΩ; R_0805_2012Metric_Pad1.15x1.40mm_HandSolder
R58: 1 kΩ; R_0805_2012Metric_Pad1.15x1.40mm_HandSolder
R59: 1, 47 kΩ; R_0805_2012Metric_Pad1.15x1.40mm_HandSolder
RV1: ERZ-E08A391CS; RV_Disc_D12mm_W6.1mm_P7.5mm
TP44: +3V3; PinHeader_1x02_P2.54mm_Vertical
TP45: +3V8; PinHeader_1x02_P2.54mm_Vertical
TP46: +15V; PinHeader_1x02_P2.54mm_Vertical
U11: TLV75533PDBV; SOT-23-5
U12: RAC03-3.8SC
U13: MEE1S0315SC; Converter_DCDC_Murata_MEE1SxxxxSC_THT

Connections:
+3V3: JP9.2, U13.2 (+Vin); also elsewhere on the board
+3V8: C45.1, JP10.2, R57.1, U11.1 (IN); also elsewhere on the board
+15V: JP11.2; also elsewhere on the board
GND: C45.2, C46.2, R58.2, R59.2, R60.2, TP44.2, TP45.2, TP46.2, U11.2 (GND), U12.14 (-VOUT), U13.1 (-Vin), U13.3 (-Vout); also elsewhere on the board
LINE: F2.1, J34.1
NEUT: J34.2, RV1.2, U12.3 (VAC(N))
unnamed: C46.1, D12.2 (A), JP9.1, TP44.1, U11.5 (OUT)
unnamed: D12.1 (K), R58.1
unnamed: D13.1 (K), R59.1
unnamed: D13.2 (A), JP10.1, TP45.1, U12.16 (+VOUT)
unnamed: D14.1 (K), R60.1
unnamed: D14.2 (A), JP11.1, TP46.1, U13.4 (+Vout)
unnamed: F2.2, RV1.1, U12.1 (VAC(L))
unnamed: R57.2, U11.3 (EN)

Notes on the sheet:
TOP LAYER
BOTTOM LAYER
TLV75533PDBV

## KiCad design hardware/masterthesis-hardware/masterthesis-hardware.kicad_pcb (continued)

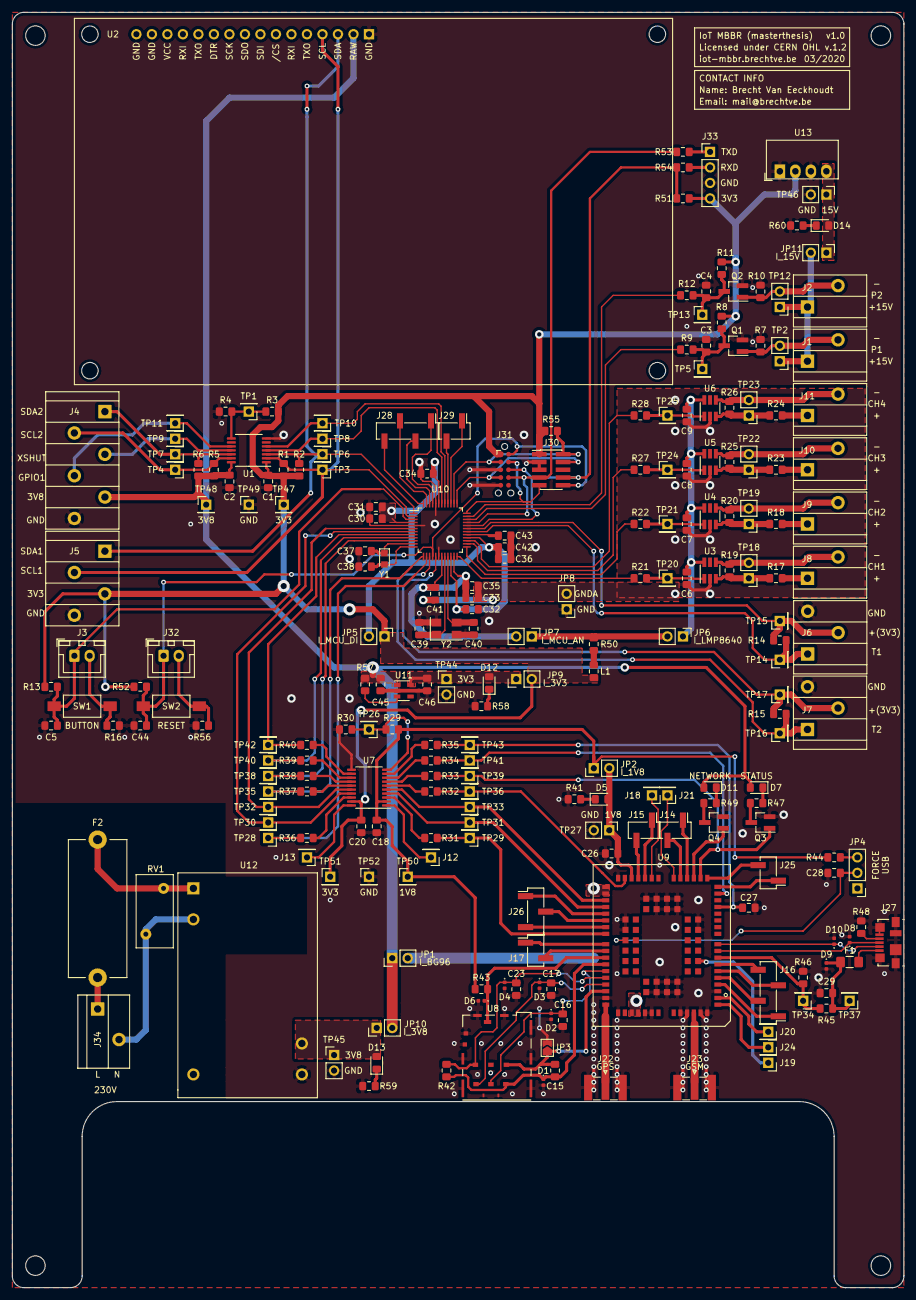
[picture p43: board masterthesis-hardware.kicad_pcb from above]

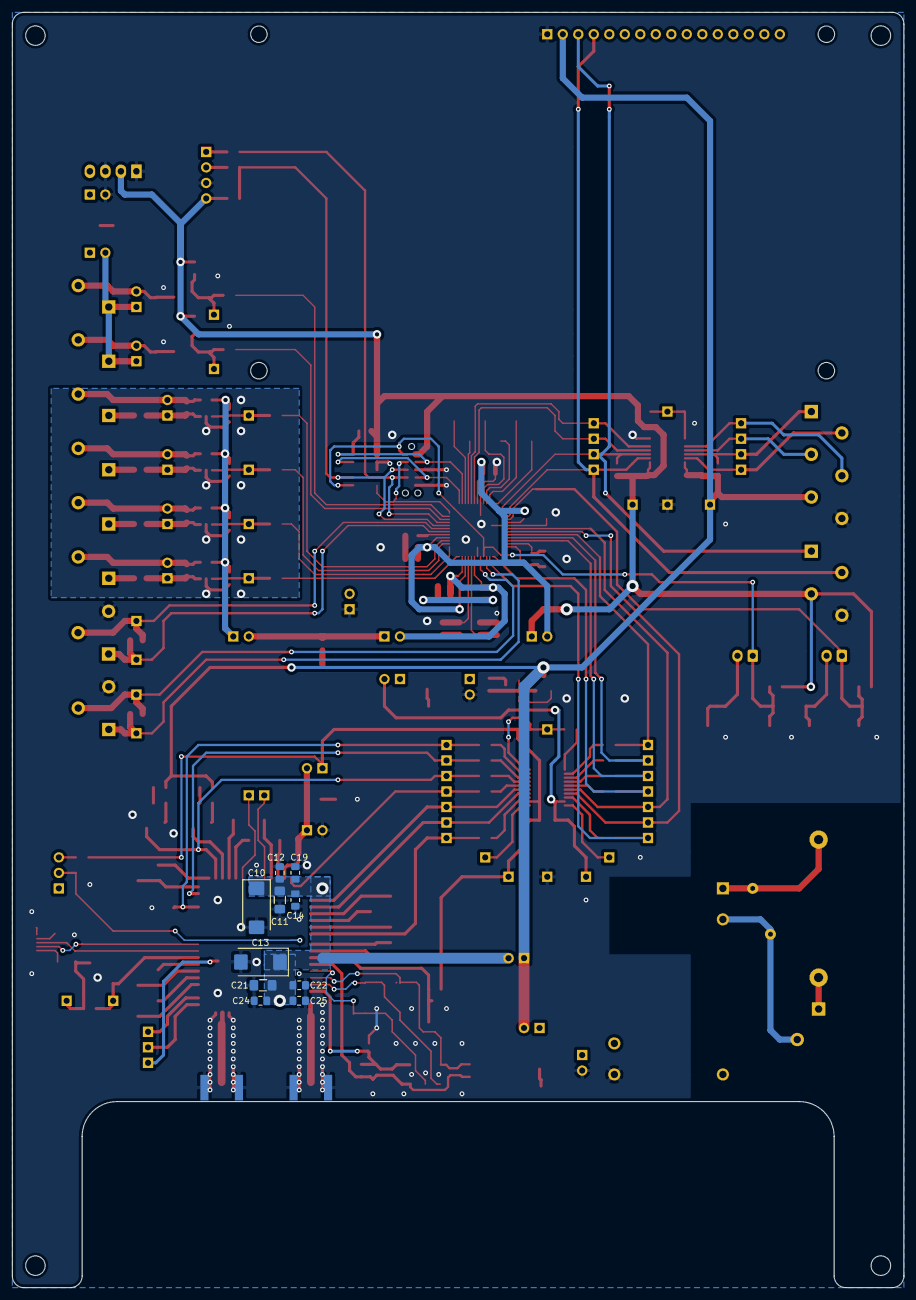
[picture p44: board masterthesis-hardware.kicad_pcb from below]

Board: 2 copper layers, 146.1 x 208.9 mm, 247 parts (10 on the bottom side), 153 nets.

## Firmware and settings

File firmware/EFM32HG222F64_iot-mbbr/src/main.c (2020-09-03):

/***************************************************************************//**
 * @file main.c
 * @brief The main file for the IoT-MBBR project.
 * @version 1.1
 * @author Brecht Van Eeckhoudt
 *
 * ******************************************************************************
 *
 * @section Versions
 * *
 *   @li v1.0: Initial version.
 *   @li v1.1: Changed `float` to `float32_t`, added ADC measurement functionality.
 *
 * ******************************************************************************
 *
 * @section License
 *
 *   **Copyright (C) 2020 - Brecht Van Eeckhoudt**
 *
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
 *   *A copy of the GNU General Public License can be found in the `LICENSE`
 *   file along with this source code.*
 *
 *   @n
 *
 *   Some methods also use code obtained from examples from [Silicon Labs' GitHub](https://github.com/SiliconLabs/peripheral_examples).
 *   These sections are licensed under the Silabs License Agreement. See the file
 *   "Silabs_License_Agreement.txt" for details. Before using this software for
 *   any purpose, you must agree to the terms of that agreement.
 *
 ******************************************************************************/


#include <stdint.h>         /* (u)intXX_t */
#include <stdbool.h>        /* "bool", "true", "false" */
#include "em_device.h"      /* Include necessary MCU-specific header file */
#include "em_chip.h"        /* Chip Initialization */
#include "em_cmu.h"         /* Clock management unit */
#include "em_gpio.h"        /* General Purpose IO */
#include "em_rtc.h"         /* Real Time Counter (RTC) */

#include "pin_mapping.h"    /* PORT and PIN definitions */
#include "debug_dbprint.h"  /* Enable or disable printing to UART for debugging */
#include "delay.h"          /* Delay functionality */
#include "util.h"           /* Utility functionality */
#include "util_string.h"    /* String functionality */
#include "interrupt.h"      /* GPIO wake-up initialization and interrupt handlers */
#include "DS18B20.h"        /* Functions related to the temperature sensor */
#include "adc.h"            /* Internal voltage and temperature reading functionality */
#include "datatypes.h"      /* Definitions of the custom data-types */
#include "serlcd.h"         /* serLCD functionality */
#include "BG96_at_driver.h" /* BG96 functionality */
#include "VL53L1X.h"        /* VL53L1X functionality */
#include "SHT30.h"          /* SHT30 functionality */


/* Local definitions */
/** Enable (1) or disable (0) the `status = 0` message */
#define SEND_STATUS_BOOT 1

/** Enable (1) or disable (0) sending of messages (for debugging) */
#define SENDING_DATA 1

/** Maximum measured height for percent calculation [mm] */
#define MAX_LENGTH_MM 300

/** Time between each wake-up in seconds
 *    @li max 500 seconds when using LFXO delay
 *    @li 3600 seconds (one hour) works fine when using ULFRCO delay */
#define WAKE_UP_PERIOD_S 3600 /* 360 = every 5 minutes */

/* Local variables */
/** Keep the state of the state machine */
static MCU_State_t MCUstate; /* Static so it's always kept in memory (@data segment, space provided during compile time) */

/** Keep the measurement data */
MeasurementData_t data;


/**************************************************************************//**
 * @brief
 *   Method to check if any interrupts are triggered by buttons.
 *
 * @return
 *   @li `true` - A button interrupt was triggered.
 *   @li `false` - No button interrupt was triggered.
 *****************************************************************************/
bool checkBTNinterrupts (void)
{
	bool value = false;

	if (BTN_getTriggered())
	{
		value = true;

		BTN_setTriggered(false); /* Clear variable */
	}

	return (value);
}


/**************************************************************************//**
 * @brief
 *   Method to display the latest measurements on the LCD.
 *****************************************************************************/
void displayMeas (void)
{
	setCursorLCD(1, 2); /* Move to second row, first column */
	writeStringLCD("T1 ");

	uint16_t temp1 = data.t1;
	if (data.t1 > 9999) temp1 /= 10; /* Remove last digit */ // TODO: round up/down!
	uint8_t temp1L = temp1 / 100;
	uint8_t temp1R = temp1 - ((temp1 / 100) * 100);
	char temp1L_char[10]; // TODO: Use less chars here because we use uint16_t (check if values aren't bigger than 0xFFFF)
	char temp1R_char[10]; // TODO: Use less chars here because we use uint16_t (check if values aren't bigger than 0xFFFF)
	uint32_to_charDec(temp1L, temp1L_char); // TODO: display negative values!
	uint32_to_charDec(temp1R, temp1R_char); // TODO: display negative values!

	writeStringLCD(temp1L_char);
	writeStringLCD(".");
	writeStringLCD(temp1R_char);
	writeStringLCD("C  T2 ");

	uint16_t temp2= data.t2;
	if (data.t2 > 9999) temp2 /= 10; /* Remove last digit */ // TODO: round up/down!
	uint8_t temp2L = temp2 / 100;
	uint8_t temp2R = temp2 - ((temp2 / 100) * 100);
	char temp2L_char[10]; // TODO: Use less chars here because we use uint16_t (check if values aren't bigger than 0xFFFF)
	char temp2R_char[10]; // TODO: Use less chars here because we use uint16_t (check if values aren't bigger than 0xFFFF)
	uint32_to_charDec(temp2L, temp2L_char); // TODO: display negative values!
	uint32_to_charDec(temp2R, temp2R_char); // TODO: display negative values!

	writeStringLCD(temp2L_char);
	writeStringLCD(".");
	writeStringLCD(temp2R_char);
	writeStringLCD("C");

	setCursorLCD(1, 3); /* Move to third row, first column */
	writeStringLCD("N1 ");

	char nitr1_char[10]; // TODO: Use less chars here because we use uint16_t (check if values aren't bigger than 0xFFFF)
	uint32_to_charDec(data.n1, nitr1_char);

	writeStringLCD(nitr1_char);
	writeStringLCD("mA N2 ");

	char nitr2_char[10]; // TODO: Use less chars here because we use uint16_t (check if values aren't bigger than 0xFFFF)
	uint32_to_charDec(data.n2, nitr2_char);

	writeStringLCD(nitr2_char);
	writeStringLCD("mA C");

	char carbon_char[10]; // TODO: Use less chars here because we use uint16_t (check if values aren't bigger than 0xFFFF)
	uint32_to_charDec(data.c, carbon_char);

	writeStringLCD(carbon_char);
	writeStringLCD("%");

	setCursorLCD(1, 4); /* Move to fourth row, first column */
	writeStringLCD("pH ");

	char pH_char[10]; // TODO: Use less chars here because we use uint16_t (check if values aren't bigger than 0xFFFF)
	uint32_to_charDec(data.p, pH_char);

	writeStringLCD(pH_char);
	writeStringLCD("mA RP ");

	char red_char[10]; // TODO: Use less chars here because we use uint16_t (check if values aren't bigger than 0xFFFF)
	uint32_to_charDec(data.r, red_char);

	writeStringLCD(red_char);
	writeStringLCD("mA");

	delay(50); /* Delay so all of the data is shown on the screen */
}


/**************************************************************************//**
 * @brief
 *   Main function.
 *****************************************************************************/
int main (void)
{
	/* Value to keep the remaining sleep time when waking up using the accelerometer */
	uint32_t remainingSleeptime = 0;

	while (1)
	{
		switch (MCUstate)
		{
			case INIT:
			{
				/* Initialize chip */
				CHIP_Init();

#if DEBUG_DBPRINT == 1 /* DEBUG_DBPRINT */
				dbprint_INIT(DBG_UART, DBG_UART_LOC, false, false);
#endif  /* DEBUG_DBPRINT */

				/* Initialize delay and sleep functionality */
				delay(0);
				sleep(2); /* Time so the I2C devices have time to start up */

				/* Initialize the LCD */
				clearLCD();
				writeStringLCD("Initializing...");

				/* Soft reset SHT30 */ // TODO: SHT30 (0x88) seems to respond to VL53L1X (0x52) commands and break the I2C bus until power cycle
//				softResetSHT30();
//				delay(2000);

				/* Initialize GPIO wake-up */
				initGPIOwakeup();

				/* Init VL53L1X */
				initVL53L1X();

				/* Init ADC */
				initADC(CH1);

				/* Initialize BG96 */
#if SENDING_DATA == 1 /* SENDING_DATA */
				initBG96();
#endif /* SENDING_DATA */

#if SEND_STATUS_BOOT == 1 /* SEND_STATUS_BOOT */

#if DEBUG_DBPRINT == 1 /* DEBUG_DBPRINT */
				dbwarn("Sending startup status ...");
#endif /* DEBUG_DBPRINT */

				clearLCD();
				writeStringLCD("Sending status (0)");

#if SENDING_DATA == 1 /* SENDING_DATA */
				sendStatus(0); /* Send the status data */
#endif /* SENDING_DATA */

#endif /* SEND_STATUS_BOOT */

				MCUstate = MEASURE;
			} break;

			case MEASURE:
			{
				clearLCD();
				writeStringLCD("Measuring...");
				displayMeas(); /* Display measurements on following rows */

				/* Measure and store the temperatures */
				int32_t temp = readTempDS18B20(0);
				if (temp < 0) data.t1 = 0;
				else data.t1 = temp;

				temp = readTempDS18B20(1);
				if (temp < 0) data.t2 = 0;
				else data.t2 = temp;

//				data.t2 = SHT30_readTemp(); // TODO: SHT30 (0x88) seems to respond to VL53L1X (0x52) commands and break the I2C bus until power cycle

				/* Measure and store distance */
				uint16_t distance = measureVL53L1X();

#if DEBUG_DBPRINT == 1 /* DEBUG_DBPRINT */
				dbinfoInt("distance = ", distance, " mm");
#endif /* DEBUG_DBPRINT */

				data.c = (uint16_t)(((float32_t)(MAX_LENGTH_MM - measureVL53L1X()) / MAX_LENGTH_MM) * 100.0);

				data.n1 = readADC(CH1);

				// TODO: measure more things!
				data.n2 = 20;
				data.p = 20;
				data.r = 20;

#if DEBUG_DBPRINT == 1 /* DEBUG_DBPRINT */
				dbprintln("");
				dbinfoInt(">> t1: ", data.t1, "");
				dbinfoInt(">> t2: ", data.t2, "");
				dbinfoInt(">> c: ", data.c, " %");
				dbinfoInt(">> n1: ", data.n1, " mA");
				dbinfoInt(">> n2: ", data.n2, " mA");
				dbinfoInt(">> p: ", data.p, " mA");
				dbinfoInt(">> r: ", data.r, " mA");
				dbprintln("");
#endif /* DEBUG_DBPRINT */

				MCUstate = SEND_DATA;
			} break;

			case SEND_DATA:
			{

#if DEBUG_DBPRINT == 1 /* DEBUG_DBPRINT */
				dbwarn("Sending measurements ...");
#endif /* DEBUG_DBPRINT */

				clearLCD();
				writeStringLCD("Sending measurements");
				displayMeas(); /* Display measurements on following rows */

#if SENDING_DATA == 1 /* SENDING_DATA */
				sendMeasurements(&data);
#endif /* SENDING_DATA */

				MCUstate = SLEEP;
			} break;

			case SEND_STATUS:
			{

#if DEBUG_DBPRINT == 1 /* DEBUG_DBPRINT */
				dbwarn("Sending STATUS ...");
#endif /* DEBUG_DBPRINT */

				// TODO

				MCUstate = SLEEP;
			} break;

			case SLEEP:
			{
				clearLCD();
				writeStringLCD("Waiting...");
				displayMeas(); /* Display measurements on following rows */


				sleep(WAKE_UP_PERIOD_S); /* Go to sleep for xx seconds */

				MCUstate = WAKEUP;
			} break;

			case WAKEUP:
			{
				/* Check if we woke up using a button */
				if (checkBTNinterrupts())
				{

#if DEBUG_DBPRINT == 1 /* DEBUG_DBPRINT */
					dbprintln("    ");
					dbprintln_color("BTN INT", 4);
#endif /* DEBUG_DBPRINT */

					remainingSleeptime = 0; /* Reset passed sleeping time */
				}

				/* Check if we woke up using the RTC sleep functionality and act accordingly */
				if (RTC_checkWakeup())
				{
					RTC_clearWakeup(); /* Clear variable */

#if DEBUG_DBPRINT == 1 /* DEBUG_DBPRINT */
					dbprintln("    ");
					dbprintln_color("RTC INT", 4);
#endif /* DEBUG_DBPRINT */

					remainingSleeptime = 0; /* Reset passed sleeping time since it's an RTC wakeup */
				}

				/* Check if we woke up because of a current pulse */
				if (PULSE_getTriggered(0) || PULSE_getTriggered(1))
				{
					RTC_Enable(false); /* Disable the counter */

#if DEBUG_DBPRINT == 1 /* DEBUG_DBPRINT */
					dbprintln("    ");
					dbprintln_color("PULSE INT", 4);
#endif /* DEBUG_DBPRINT */

					clearLCD();
					writeStringLCD("Sending pulses...");
					displayMeas(); /* Display measurements on following rows */

					if (PULSE_getTriggered(0))
					{

#if DEBUG_DBPRINT == 1 /* DEBUG_DBPRINT */
					dbwarn("Sending P1 pulses ...");
#endif /* DEBUG_DBPRINT */

#if SENDING_DATA == 1 /* SENDING_DATA */
						sendPulse (0, 1);
#endif /* SENDING_DATA */

						PULSE_setTriggered(0, false);
					}
					else if (PULSE_getTriggered(1))
					{

#if DEBUG_DBPRINT == 1 /* DEBUG_DBPRINT */
					dbwarn("Sending P2 pulses ...");
#endif /* DEBUG_DBPRINT */

#if SENDING_DATA == 1 /* SENDING_DATA */
						sendPulse (1, 1);
#endif /* SENDING_DATA */

						PULSE_setTriggered(1, false);
					}

					MCUstate = WAKEUP;

					clearLCD();
					writeStringLCD("Waiting...");
					displayMeas(); /* Display measurements on following rows */

					remainingSleeptime += RTC_getPassedSleeptime(); /* Add the time spend sleeping to the variable */

					/* Go back to sleep for the remaining time until another measurement (we only take measurements on RTC/button wake-up) */
					sleep(WAKE_UP_PERIOD_S - remainingSleeptime);

				}
				else
				{
					MCUstate = MEASURE;
				}

			} break;

			default:
			{
				error(10);
			} break;
		}
	}
}


/**************************************************************************//**
 * @brief
 *   NMI interrupt service routine.
 *
 * @note
 *   The *weak* definition for this method is located in `startup_gcc_efm32hg.h`.
 *****************************************************************************/
void NMI_Handler(void)
{
	while(1);
}


/**************************************************************************//**
 * @brief
 *   HardFault interrupt service routine.
 *
 * @note
 *   The *weak* definition for this method is located in `startup_gcc_efm32hg.h`.
 *****************************************************************************/
void HardFault_Handler(void)
{
	while(1);
}


/**************************************************************************//**
 * @brief
 *   SVC interrupt service routine.
 *
 * @note
 *   The *weak* definition for this method is located in `startup_gcc_efm32hg.h`.
 *****************************************************************************/
void SVC_Handler(void)
{
	while(1);
}


/**************************************************************************//**
 * @brief
 *   PendSV interrupt service routine.
 *
 * @note
 *   The *weak* definition for this method is located in `startup_gcc_efm32hg.h`.
 *****************************************************************************/
void PendSV_Handler(void)
{
	while(1);
}

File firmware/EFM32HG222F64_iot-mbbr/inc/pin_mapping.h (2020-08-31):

/***************************************************************************//**
 * @file pin_mapping.h
 * @brief The pin definitions for the custom board.
 * @version 1.0
 * @author Brecht Van Eeckhoudt
 *
 * ******************************************************************************
 *
 * @section Versions
 *
 *   @li v1.0: Initial version.
 *
 * ******************************************************************************
 *
 * @section License
 *
 *   **Copyright (C) 2020 - Brecht Van Eeckhoudt**
 *
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
 *   *A copy of the GNU General Public License can be found in the `LICENSE`
 *   file along with this source code.*
 *
 *   @n
 *
 *   Some methods use code obtained from examples from [Silicon Labs' GitHub](https://github.com/SiliconLabs/peripheral_examples).
 *   These sections are licensed under the Silabs License Agreement. See the file
 *   "Silabs_License_Agreement.txt" for details. Before using this software for
 *   any purpose, you must agree to the terms of that agreement.
 *
 ******************************************************************************/


/* Include guards prevent multiple inclusions of the same header */
#ifndef _PIN_MAPPING_H_
#define _PIN_MAPPING_H_


/* Include necessary for this header file */
#include "em_device.h" /* Include necessary MCU-specific header file */
#include "em_gpio.h"   /* General Purpose IO */


/* I2C */
#define BUS_I2C            	I2C0
#define BUS_I2C_LOC        	I2C_ROUTE_LOCATION_LOC0
#define BUS_SDA_PORT		gpioPortA
#define BUS_SDA_PIN       	0
#define BUS_SCL_PORT      	gpioPortA
#define BUS_SCL_PIN       	1

/* BUTTON */
#define BTN_PORT      		gpioPortA
#define BTN_PIN       		2

/* VL53L1X */
#define VL53L1X_GPIO1_PORT	gpioPortF
#define VL53L1X_GPIO1_PIN	4
#define VL53L1X_XSHUT_PORT	gpioPortF
#define VL53L1X_XSHUT_PIN	5

/* BG96 */
#define BG96_UART           USART1
#define BG96_UART_LOC       0
#define BG96_TXD_PORT       gpioPortC
#define BG96_TXD_PIN        1
#define BG96_RXD_PORT       gpioPortC
#define BG96_RXD_PIN        0
#define BG96_PWRKEY_PORT    gpioPortC
#define BG96_PWRKEY_PIN     2
#define BG96_RESET_PORT     gpioPortC
#define BG96_RESET_PIN      3
#define BG96_STAT_PORT     	gpioPortC
#define BG96_STAT_PIN      	4
#define BG96_DTR_PORT     	gpioPortA
#define BG96_DTR_PIN      	8
#define BG96_RI_PORT     	gpioPortA
#define BG96_RI_PIN      	9

/* DEBUG UART */
#define DBG_UART            USART0
#define DBG_UART_LOC        2
#define DBG_TXD_PORT        gpioPortC
#define DBG_TXD_PIN         11
#define DBG_RXD_PORT        gpioPortC
#define DBG_RXD_PIN         10
#define DBG_GNDD_PORT       gpioPortC
#define DBG_GNDD_PIN        15

/* DS18B20 */
#define TEMP0_DATA_PORT     gpioPortC
#define TEMP0_DATA_PIN      8
#define TEMP0_VDD_PORT      gpioPortC
#define TEMP0_VDD_PIN       9
#define TEMP1_DATA_PORT     gpioPortA
#define TEMP1_DATA_PIN      10
#define TEMP1_VDD_PORT      gpioPortB
#define TEMP1_VDD_PIN       11

/* PULSE INPUTS */
#define PULSE0_PORT         gpioPortC /* PCNT0_S0IN #0 */
#define PULSE0_PIN          13
#define PULSE1_PORT         gpioPortC /* PCNT0_S1IN #0 */
#define PULSE1_PIN          14

/* ADC INPUTS */
#define ADC0_PORT      		gpioPortD /* ADC0_CH4 */
#define ADC0_PIN       		4
#define ADC1_PORT      		gpioPortD /* ADC0_CH5 */
#define ADC1_PIN       		5
#define ADC2_PORT      		gpioPortD /* ADC0_CH6 */
#define ADC2_PIN       		6
#define ADC3_PORT      		gpioPortD /* ADC0_CH7 */
#define ADC3_PIN       		7

/* SPARE */
#define J28_0_PORT			gpioPortE
#define J28_0_PIN			10
#define J28_1_PORT			gpioPortE
#define J28_1_PIN			11
#define J28_2_PORT			gpioPortE
#define J28_2_PIN			12
#define J28_3_PORT			gpioPortE
#define J28_3_PIN			13
#define J29_0_PORT			gpioPortF
#define J29_0_PIN			2
#define J29_1_PORT			gpioPortF
#define J29_1_PIN			3


#endif /* _PIN_MAPPING_H_ */

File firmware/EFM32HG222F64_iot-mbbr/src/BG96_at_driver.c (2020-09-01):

/***************************************************************************//**
 * @file BG96_at_driver.c
 * @brief BG96 AT-command driver functionality.
 * @version 1.0
 * @author Brecht Van Eeckhoudt
 *
 * ******************************************************************************
 *
 * @section Versions
 *
 *   @li v1.0: Basic functionality to send measurements to the cloud using NB-IoT
 *             without timeout functionality.
 *
 * ******************************************************************************
 *
 * @section License
 *
 *   **Copyright (C) 2020 - Brecht Van Eeckhoudt**
 *
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
 *   *A copy of the GNU General Public License can be found in the `LICENSE`
 *   file along with this source code.*
 *
 *   @n
 *
 *   Some methods use code obtained from examples from [Silicon Labs' GitHub](https://github.com/SiliconLabs/peripheral_examples).
 *   These sections are licensed under the Silabs License Agreement. See the file
 *   "Silabs_License_Agreement.txt" for details. Before using this software for
 *   any purpose, you must agree to the terms of that agreement.
 *
 ******************************************************************************/


#include <stdint.h>         /* (u)intXX_t */
#include <stdbool.h>        /* "bool", "true", "false" */
#include "em_cmu.h"         /* Clock Management Unit */
#include "em_device.h"      /* Include necessary MCU-specific header file */
#include "em_gpio.h"        /* General Purpose IO */

#include "BG96_at_driver.h" /* Corresponding header file */
#include "debug_dbprint.h"  /* Enable or disable printing to UART */
#include "delay.h"          /* Delay functionality */
#include "util_string.h"    /* String functionality */
#include "datatypes.h"      /* Definitions of the custom data-types */
#include "credentials.h"    /* DEVICE_ID and DEVICE_TOKEN */
#include "pin_mapping.h"    /* PORT and PIN definitions */


/* Local definitions */
#define PRINT_ID_TOKEN 0 /* 0 = don't print ID & Token, 1 = print ID & Token */


/* Local variables */
/*   Convert ASCII to hex:
 *    => "-1" to get the correct length because the NULL termination character is at the end of the array
 *    => "*2" because one ASCII char becomes two HEX chars
 *    => "+1" to add the NULL termination character at the end
 */
char DEVICE_ID_hex[2*(sizeof(DEVICE_ID)-1) +1];
char DEVICE_TOKEN_hex[2*(sizeof(DEVICE_TOKEN)-1) +1];


/* Local prototypes */
static bool transmissionBegin (bool continueCode);
static bool transmissionEnd (bool continueCode);


/**************************************************************************//**
 * @brief
 *   Initialize the GPIO pins and UART0 module necessary to communicate with
 *   the BG96 module.
 *****************************************************************************/
void initBG96 (void)
{
	/* Convert ID & Token */
	charASCII_to_charHex(DEVICE_ID, DEVICE_ID_hex);
	charASCII_to_charHex(DEVICE_TOKEN, DEVICE_TOKEN_hex);

#if PRINT_ID_TOKEN == 1 /* PRINT_ID_TOKEN */
#if DEBUG_DBPRINT == 1 /* DEBUG_DBPRINT */
		dbprint("INFO: DEVICE_ID = ");
		dbprintln(DEVICE_ID);
		dbprint("INFO: DEVICE_ID_hex = ");
		dbprintln(DEVICE_ID_hex);
		dbprintln("");
		dbprint("INFO: DEVICE_TOKEN = ");
		dbprintln(DEVICE_TOKEN);
		dbprint("INFO: DEVICE_TOKEN_hex = ");
		dbprintln(DEVICE_TOKEN_hex);
		dbprintln("");
#endif /* DEBUG_DBPRINT */
#endif /* PRINT_ID_TOKEN */

	/* Enable oscillator to GPIO*/
	CMU_ClockEnable(cmuClock_GPIO, true);

	/* Initialize GPIO pin for PWR key */
	/* In the case of gpioModePushPull, the last argument directly sets the pin state */
	GPIO_PinModeSet(BG96_PWRKEY_PORT, BG96_PWRKEY_PIN, gpioModePushPull, 0);

	/*
	 * USART_INITASYNC_DEFAULT:
	 *   config.enable = usartEnable       // Specifies whether TX and/or RX is enabled when initialization is completed
	 *                                     // (Enable RX/TX when initialization is complete).
	 *   config.refFreq = 0                // USART/UART reference clock assumed when configuring baud rate setup
	 *                                     // (0 = Use current configured reference clock for configuring baud rate).
	 *   config.baudrate = 115200          // Desired baudrate (115200 bits/s).
	 *   config.oversampling = usartOVS16  // Oversampling used (16x oversampling).
	 *   config.databits = usartDatabits8  // Number of data bits in frame (8 data bits).
	 *   config.parity = usartNoParity     // Parity mode to use (no parity).
	 *   config.stopbits = usartStopbits1  // Number of stop bits to use (1 stop bit).
	 *   config.mvdis = false              // Majority Vote Disable for 16x, 8x and 6x oversampling modes (Do not disable majority vote).
	 *   config.prsRxEnable = false        // Enable USART Rx via PRS (Not USART PRS input mode).
	 *   config.prsRxCh = 0                // Select PRS channel for USART Rx. (Only valid if prsRxEnable is true - PRS channel 0).
	 *   config.autoCsEnable = false       // Auto CS enabling (Auto CS functionality enable/disable switch - disabled).
	 */

	USART_InitAsync_TypeDef config = USART_INITASYNC_DEFAULT;

	/* Enable oscillator to USARTx modules */
	if (BG96_UART == USART0) CMU_ClockEnable(cmuClock_USART0, true);
	else if (BG96_UART == USART1) CMU_ClockEnable(cmuClock_USART1, true);

	/* Set pin modes for UART TX and RX pins */
	if (BG96_UART == USART0)
	{
		switch (BG96_UART_LOC)
		{
			case 0:
				GPIO_PinModeSet(gpioPortE, 11, gpioModeInput, 0);    /* RX */
				GPIO_PinModeSet(gpioPortE, 10, gpioModePushPull, 1); /* TX */
				break;
			case 2:
				GPIO_PinModeSet(gpioPortC, 10, gpioModeInput, 0);    /* RX */
				/* No TX pin in this mode */
				break;
			case 3:
				GPIO_PinModeSet(gpioPortE, 12, gpioModeInput, 0);    /* RX */
				GPIO_PinModeSet(gpioPortE, 13, gpioModePushPull, 1); /* TX */
				break;
			case 4:
				GPIO_PinModeSet(gpioPortB, 8, gpioModeInput, 0);     /* RX */
				GPIO_PinModeSet(gpioPortB, 7, gpioModePushPull, 1);  /* TX */
				break;
			case 5:
			case 6:
				GPIO_PinModeSet(gpioPortC, 1, gpioModeInput, 0);     /* RX */
				GPIO_PinModeSet(gpioPortC, 0, gpioModePushPull, 1);  /* TX */
				break;
			/* default: */
				/* No default */
		}
	}
	else if (BG96_UART == USART1)
	{
		switch (BG96_UART_LOC)
		{
			case 0:
				GPIO_PinModeSet(gpioPortC, 1, gpioModeInput, 0);     /* RX */
				GPIO_PinModeSet(gpioPortC, 0, gpioModePushPull, 1);  /* TX */
				break;
			case 2:
			case 3:
				GPIO_PinModeSet(gpioPortD, 6, gpioModeInput, 0);     /* RX */
				GPIO_PinModeSet(gpioPortD, 7, gpioModePushPull, 1);  /* TX */
				break;
			case 4:
				GPIO_PinModeSet(gpioPortA, 0, gpioModeInput, 0);     /* RX */
				GPIO_PinModeSet(gpioPortF, 2, gpioModePushPull, 1);  /* TX */
				break;
			case 5:
				GPIO_PinModeSet(gpioPortC, 2, gpioModeInput, 0);     /* RX */
				GPIO_PinModeSet(gpioPortC, 1, gpioModePushPull, 1);  /* TX */
				break;
			/* default: */
				/* No default */
		}
	}

	/* Initialize USART asynchronous mode */
	USART_InitAsync(BG96_UART, &config);
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

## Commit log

2020-08-31 Added hardware files
    [0ZCJ0010FF2E--3DModel-STEP-56544.STEP, BG96.sch, CON-SMA-EDGE-S.stp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]
2020-08-31 Added documentation files
    [EFM32HG_BRD2012A_B01_bom.xlsx]
2020-09-01 Fixed documentation and minor debug changes
    [BG96_at_driver.c, i2c.c, serlcd.c]
2020-09-03 Added ADC CH4/5/6/7 functionality

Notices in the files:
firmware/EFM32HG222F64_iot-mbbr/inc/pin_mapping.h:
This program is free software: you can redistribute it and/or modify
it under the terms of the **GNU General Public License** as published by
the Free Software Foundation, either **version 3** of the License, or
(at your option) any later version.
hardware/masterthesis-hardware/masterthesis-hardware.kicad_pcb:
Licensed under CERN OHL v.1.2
